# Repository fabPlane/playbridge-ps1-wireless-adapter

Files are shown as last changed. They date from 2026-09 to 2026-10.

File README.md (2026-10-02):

# PlayBridge PS1 Wireless Adapter

PlayBridge is an ESP32-based wireless bridge that receives PC controller state
over Wi-Fi and presents it to an original PlayStation through the native PS1
controller protocol.

## Hardware versions

| Version | Design | Status |
| --- | --- | --- |
| `v1.0.0` | Direct PCB-mounted PS1 pin array | Frozen prototype checkpoint under [`versions/v1-pcb-mounted-pin-array/`](versions/v1-pcb-mounted-pin-array/) |
| `v2.0.0` | Modular donor-plug harness through board-mounted 9-contact connectors | Frozen release candidate under [`versions/v2-donor-plug-modular-adapter/`](versions/v2-donor-plug-modular-adapter/) |
| `v2.1.0` | V2.0 baseline plus status LEDs and UART debug access | Release candidate under [`versions/v2.1-status-leds-uart-debug/`](versions/v2.1-status-leds-uart-debug/) |
| `v3.0.0` | Combined PS1 controller and serial-harness evaluation | Frozen development checkpoint under [`versions/v3.0-ps1-serial-harness/`](versions/v3.0-ps1-serial-harness/) |
| `v4.0.0` | New two-layer controller/serial bridge with protected dual-source power | Digitally verified design under [`versions/v4.0-controller-serial-bridge/`](versions/v4.0-controller-serial-bridge/); physical qualification pending |
| `v4.1.0` | V4.0 electrical design with ANTS-compatible enlarged routed vias | Digitally verified fabrication revision under [`versions/v4.1-controller-serial-bridge/`](versions/v4.1-controller-serial-bridge/); physical qualification pending |

Each hardware version is a self-contained FabDesk project under `versions/`.
Open the version directory itself in FabDesk; the repository root is only the
project index plus shared firmware and documentation.

## V4.0.0 status

- Board: 68 × 60 mm, two copper layers.
- J1: PS1 controller harness with open-drain DATA and ACK stages.
- J2: PS1 serial harness on ESP32 UART2.
- Power: protected USB-C and PS1 inputs, TPS2116 source mux, AP63203 buck,
  and AP2112K 3.3 V regulation.
- Programming: CH340C with manual BOOT and RESET switches; automatic DTR/RTS
  behavior is present but is not required for acceptance.
- Indicators: always-on power LED and firmware-controlled status LED.
- Digital checks: ERC, DRC, schematic/PCB parity, BOM/CPL reference parity,
  fabrication archive integrity, and export manifest all pass.
- Manufacturing: bare-board Gerbers and in-house assembly BOM/CPL are present.
- Production remains on hold until the current-limited power, source-switching,
  programming, J1, and J2 bench tests are recorded.

See [`versions/v4.0-controller-serial-bridge/README.md`](versions/v4.0-controller-serial-bridge/README.md)
for the design summary and exact connector/GPIO maps.

## V4.1.0 fabrication revision

V4.1 preserves the V4.0 schematic, component placement, connector mechanics,
GPIO map, and BOM. Its routed through-vias are enlarged to 0.90 mm copper
diameter with 0.40 mm drills to satisfy the ANTS PCB production feedback.
The affected escape routing and manufacturing outputs were regenerated and
pass ERC, DRC, connectivity, drill, and archive-integrity checks. The same
physical bench-test hold still applies.

## V3.0 and V4.0 comparison

| Area | V3.0 | V4.0 | Compatibility / action |
| --- | --- | --- | --- |
| J1/J2 | Hong Cheng C7501856; same signal pinout | Same | Harness-compatible |
| Shells | Isolated | J1→GND pad 4; J2→GND pad 7 | Grounding changed |
| Placement | J1 `(8.025,50.825)`; J2 `(26.025,50.825)` mm | J1 `(14,48.5)`; J2 `(39.2,48.5)` mm | Not mechanically drop-in |
| Controller GPIO | CMD32, CLK33, ATT34, DATA19, ACK21 | CMD19, CLK32, ATT21, DATA33, ACK27/sense34 | Firmware change |
| DATA/ACK | 2N7002 open-drain; no ACK sense | Same drivers plus ACK sense | Firmware change |
| J2 UART | TX17 / RX16 | TX17 / RX16 | Compatible |
| Power | AP63203 + AP2112K + TPS2113A | AP63203 + AP2112K + TPS2116 | Mux changed |
| Protection | USBLC6, SMBJ12A, BAT54 clamps | SMAJ TVS, TPD2EUSB30A, ACK ESD | Prototype-test required |
| LEDs | Red power; yellow-green status GPIO4 | Green power; blue status GPIO25 | GPIO/color change |
| Programming | CH340C; manual BOOT/RESET; DTR/RTS | Same | Auto mode unqualified |
| PCB | 56.295 × 62 mm; 4-layer; 1.2 mm | 68 × 60 mm; 2-layer; 1.6 mm | Size/stackup changed |
| Validation | J1/J2 PoC tested | Digital checks pass; bench pending | First prototype only |

## V2.0.0 historical status

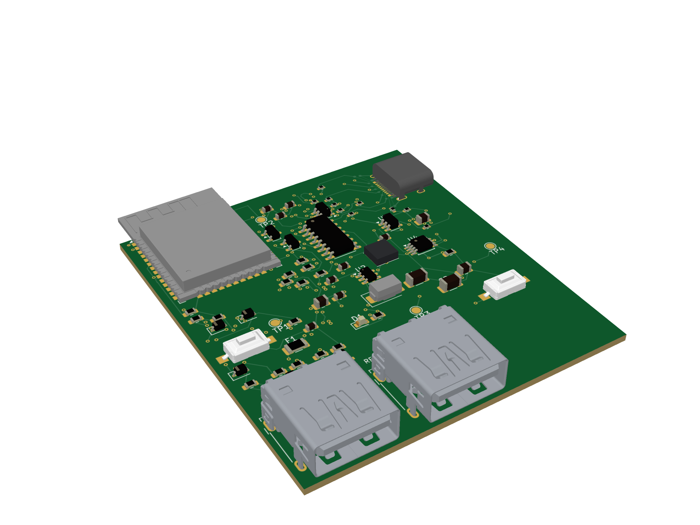
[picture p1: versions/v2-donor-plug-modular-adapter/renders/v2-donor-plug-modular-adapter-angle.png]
PlayBridge V2.0 donor-plug modular adapter board


_Board render created with [PCB Fiddle](https://pcbfiddle.com/)._

- Board: 56.295 × 62.000 mm, four copper layers, 1.20 mm thick.
- J1: 9-contact non-USB connector for a genuine PS1 donor-plug harness.
- J2: mechanically identical reserved connector; every contact is intentionally NC.
- J3: USB-C programming/power receptacle on the right edge, facing outward.
- J1 and J2: lower-edge mating mouths face outward and remain registered to the approved Molex footprints.
- Routing: complete; zero unconnected items.
- DRC: zero errors and zero warnings.
- ERC: zero errors and zero warnings.
- Schematic/PCB parity: zero findings.
- FabDesk release gate: PASS.
- PCBA data: 63 fitted references, 32 grouped BOM lines, and four DNP test pads.
- Controller-port bench firmware passed visible original-PS1 system-menu testing over Wi-Fi: all supported digital buttons worked, quick clicks were reliable, and the final check recorded 17,913 complete polls.

The design release is electrically and mechanically validated. Ordering still
requires a final live JLCPCB stock check and review of the uploaded BOM/CPL
rotation previews; see
[`versions/v2-donor-plug-modular-adapter/ordering/DO-NOT-ORDER.md`](versions/v2-donor-plug-modular-adapter/ordering/DO-NOT-ORDER.md).

## Repository layout

- `versions/v1-pcb-mounted-pin-array/` — complete frozen V1 FabDesk project, fit checks, historical renders, and provisional-contact studies.
- `versions/v2-donor-plug-modular-adapter/` — complete V2.0.0 FabDesk project, manufacturing package, reports, tools, references, and accepted renders.
- `versions/v2.1-status-leds-uart-debug/` — complete V2.1.0 FabDesk project, debug interface, manufacturing package, reports, tools, and accepted renders.
- `versions/v3.0-ps1-serial-harness/` — complete V3.0 controller/serial-harness development checkpoint and PoC evidence.
- `versions/v4.0-controller-serial-bridge/` — complete V4.0 FabDesk project, local libraries, validation evidence, renders, and manufacturing package.
- `versions/v4.1-controller-serial-bridge/` — V4.1 ANTS-compatible via revision, regenerated validation evidence, renders, and manufacturing package.
- `firmware/playbridge_wifi_test/` — shared ESP32 Wi-Fi controller firmware and bench instructions.
- `docs/` — shared protocol and modular-interconnect diagrams.

## Opening a hardware project

In FabDesk, select the desired directory under `versions/`, not the repository
root. New hardware work should begin by copying the latest applicable version
to a new version directory so previous releases remain unchanged.

## Important connector warning

J1 and J2 use USB 3 Type-A connector hardware only as inexpensive keyed
9-contact interconnects. They carry native console signals and are **NOT USB**.
Never connect either port to a computer, charger, or ordinary USB peripheral.

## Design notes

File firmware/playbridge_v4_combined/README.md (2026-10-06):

# PlayBridge V4 controller and J2 firmware

Experimental combined firmware for the PS1 controller port and rear serial
port. This preserves the console-tested polling controller and adds an opaque
TCP to UART2 bridge. The bench-profile combined build has now been flashed and
tested with controller input, two small RAM dumps, and a checksum-verified
128 KiB memory-card download through Wi-Fi to a Mac-mounted SD card. This is
not production qualification or proof of game loading/simultaneous gameplay.

The unchanged, working controller-only source is preserved in
[`../playbridge_v4_controller`](../playbridge_v4_controller).
The pre-existing `../playbridge_wifi_test` sketch is also untouched.
The older handoff prompt's SPI pin mapping and claim that J2 is NC must not be
used as V4 wiring instructions.

## Select the physical pin profile

The default is the **actual working breadboard**, not the assembled PCB.

| Signal | Profile 1 bench default | Profile 2 V4 PCB |
| --- | --- | --- |
| CMD input | GPIO34 | GPIO19 |
| CLK input | GPIO32 | GPIO32 |
| ATT input | GPIO21 | GPIO21 |
| DATA drive | GPIO33 | GPIO33 |
| ACK drive | GPIO27 | GPIO27 |
| DATA diagnostic input | GPIO19 via 1 kΩ | Disabled |
| ACK diagnostic input | Not used | GPIO34 reserved, not read |
| J2 TX | GPIO17 via **220 Ω** to console RX (bench equivalent of J2.1) | GPIO17 via 1 kΩ to J2.1; not qualified |
| J2 RX | Console TX via 1 kΩ to GPIO16; 10 kΩ pull-up at harness-side junction | J2.4 via 1 kΩ to GPIO16; not qualified |
| J2 GND | J2.7 | Same |

J2.1 connects to **console RX**, J2.4 to **console TX**. These are J2 connector
numbers, not rear-PS1-port pin numbers. Continuity-map the real harness and
verify 3.3 V-compatible levels; never infer by wire colour. J2 carries no power,
is not USB, and all other J2 contacts remain open. Remove the old UART loopback
before attaching the peer. UART0 USB programming/debug is separate.

Bench controller values verified during debugging: DATA C50 pull-up **1 kΩ** to
3.3 V; E51 to F51 control resistor **1 kΩ**; C51 pull-down **100 kΩ** to GND.
Keep E50 to F50 **1 kΩ** and G50 to GPIO19 for diagnostic readback in profile 1.
GPIO HIGH turns on the external output stage and pulls the PS1 line LOW.
The bench NPN circuit is not evidence that V4 PCB component values or its
2N7002 stages are physically qualified. No PCB or BOM files are changed by this
PR; the breadboard-only serial adjustments above are recorded in TEST-RESULTS.md.

## Architecture

- Core 1 Arduino loop owns the IRAM polling controller. The 16-bit active-low
  button state is latched once per transaction. ACK delay is 14 µs, LOW for
  2 µs, and there is no final-byte ACK. No per-edge ISR, networking, allocation,
  or logging occurs inside the controller transaction.
- Core 0 web task owns Wi-Fi AP/STA and HTTP 80. Saved credentials are reused,
  Wi-Fi sleep is disabled, and runtime credential writes/OTA are not exposed.
  The current full-state `POST /state` interface is retained; the obsolete
  reference `/input` and `/button` interfaces are not imported.
- A separate core 0 task owns UART2, TCP 3333 and UDP 3334. It initializes the
  IDF UART driver on that core, which also allocates the UART ISR there.
  HTTP never accesses live UART or bridge sockets.
- Short synchronized snapshots provide `/status` (controller) and
  `/bridge/status` (serial counters, baud, fault, owner core, timing, heap,
  stack). Web handling remains active during transfers.
- Browser holds refresh every 200 ms. Button input expires after 800 ms
  without an accepted update; blur/cancel/neutral release immediately when
  the request arrives. HTTP success is not proof the console accepted a reply.

The bounded polling wait still disables interrupts on core 1 for up to 2 ms,
plus up to a 2 ms transaction timeout. Core separation reduces UART contention
but is not proof of performance. Measure simultaneous pad latency, serial
integrity and throughput on hardware.

## Serial protocol

UART starts at **115200 8N1**, with no hardware flow control. The existing
PC launcher coordinates the PS1-side baud switch; the bridge does not negotiate
it with the console. Supported rates: 115200, 230400, 518400, 691200, 1036800,
2073600. Support here means accepted configuration, not a measured speed claim.

TCP 3333 has one owner and carries only raw bytes, with no added framing or
logs. The PC asset server, patched PS1 launcher/game code, and checksums/retries
remain external. This is not direct SD access or universal game compatibility.
The unchanged handoff `host/bridge_baud.py` controls bridge baud. The additional
`host/memcard_backup.py` performs read-only Unirom 8.0.K memory-card backups;
it is not the game asset server.

### Read-only memory-card backup (Unirom 8.0.K)

Use Python 3 on the host. Boot to the Unirom menu, insert the card, verify the
three-wire serial harness, remove any loopback, and leave the bridge idle at
115200. Specify the physical slot (1 or 2) and a **new** output filename in an
existing writable directory on the mounted destination. For example:

```sh
python3 firmware/playbridge_v4_combined/host/memcard_backup.py \
  --host ESP32_IP --slot 1 --output /Volumes/YOUR_SD/ps1-slot1-backup.mcd
```

The tool sends `MCDN`, negotiates `OKV2`/`UPV2` (or V3), waits for **`OKAY`**,
sends zero-based card index, and waits for `MCRD` plus RAM address/length.
It validates a 128 KiB buffer wholly within PS1 RAM, uses `DUMP`, sends `MORE`
after each 2048 bytes, verifies the negotiated checksum, saves without
overwriting, and verifies the saved file's SHA-256 by reading it back.
It prints a JSON result; it does not commit or upload backups anywhere.
The memory card is read-only; Unirom temporarily stages its data in console RAM.
Do not disconnect/power off or press controller buttons during the read.

This protocol is pinned to the
[older official NoPS definitions](https://github.com/JonathanDotCel/NOTPSXSerial/blob/63a47555353404ff067563f26529897bf84cf84c/NOTPSXSERIAL.CS)
and [transfer implementation](https://github.com/JonathanDotCel/NOTPSXSerial/blob/63a47555353404ff067563f26529897bf84cf84c/TransferLogic.cs).
The newer client's `HLTD` expectation for MCDN did not match this bench console.
After a timeout the console may still be waiting for a protocol field: **do not
blindly retry**. Return it to a fresh Unirom menu first. The published tool has
no automatic retry or mid-session resume shortcut.

`PING` returned only its own echo on this console, while DUMP and MCDN succeeded.
Do not treat an echoed PING as a loopback diagnosis or demand PONG as a required
gate for this setup. A full negotiated, checksum-verified dump is stronger
evidence. Do not stop a handshake just because the command itself is echoed.

UDP 3334 accepts exactly 20 bytes:

| Bytes | Meaning |
| --- | --- |
| 0 to 3 | ASCII PSB1 |
| 4 to 7 | Host nonce, little-endian |
| 8 to 11 | Baud, little-endian |
| 12 to 15 | Flags: 0 normal, 1 abort session |
| 16 to 19 | Standard CRC32 of bytes 0 to 15, little-endian |

Success echoes the exact request to its originating IP/port. Invalid packets,
wrong active-owner IP, busy queues, failed baud changes, or drain timeout get
no success echo. During normal handoff, both forwarding queues and new input
must be empty. TX drain is polled with zero ticks and a 150 ms deadline; new
input cancels that handoff. The launcher retries on no acknowledgement.

Successful control effects are cached **before** sending the echo: eight
requests for ten seconds, keyed by sender IP/port and exact frame. A retry
does not abort a new session. An older request whose baud has since changed
gets no misleading success echo. This is bounded duplicate suppression, not
authentication or indefinite replay protection; use a trusted LAN.

Abort/disconnect/error discards application queues and reinstalls UART2 to
discard driver RX/TX rings and reset FIFOs. Bytes already transmitted cannot be
retracted: abort does not reset the PS1 or restore Unirom. The launcher must
resynchronize. If UART reset fails, the bridge stays faulted until reboot.
New clients are accepted only after UART cleanup. UART bytes without a client
are discarded, so connect the PC session before requesting a console response.
TCP close is a session abort, not a supported half-close request/response mode.

Queue sizes: 16,384 UART RX; 4,096 UART TX; 16,384 UART-to-TCP pending;
1,024 TCP-to-UART pending. Partial writes retain offsets. Retryable socket
errors do not discard data. Each direction has its own ten-second progress
deadline; traffic in the other direction cannot mask a stalled queue.

## Build and test

Use Arduino CLI with installed Arduino-ESP32 **3.3.11**, Node32s, standard
4 MB board profile; do not copy the handoff's COM10 or 16 MB flash settings.
Commands from repository root:

```sh
sh firmware/playbridge_v4_combined/tests/run.sh

arduino-cli compile --fqbn esp32:esp32:node32s \
  --build-path /tmp/playbridge-combined-bench-build \
  firmware/playbridge_v4_combined

arduino-cli compile --fqbn esp32:esp32:node32s \
  --build-property compiler.cpp.extra_flags=-DPLAYBRIDGE_PROFILE=2 \
  --build-path /tmp/playbridge-combined-pcb-build \
  firmware/playbridge_v4_combined
```

Native tests need a C++17 compiler with ASan/UBSan, Node.js and Python 3. They execute the
actual transport core and actual polled engine, not independent protocol
reimplementations. The browser script is exercised with a mocked DOM/network.
The Python backup tests use synthetic data and fake peers. The test runner
does not open UART, send LAN traffic, or flash hardware. The explicitly invoked
host backup tool does send serial commands and writes the requested backup file.

Keep the controller-only rollback source and existing verified binary before
any separately authorized upload. Change wires only with USB unplugged and PS1
off; physically disconnect both console harnesses before flashing. Do not
flash the handoff's compile-only harness.

## Evidence and remaining acceptance

See [TEST-RESULTS.md](TEST-RESULTS.md) and [provenance.json](provenance.json).
The user confirmed every controller web button on the controller-only baseline,
then confirmed movement on the flashed combined build. Subsequent combined-build
testing transferred actual PS1 RAM and slot-1 memory-card data through Wi-Fi.
The preceding 1,624-complete-reply diagnostic with zero sampled DATA mismatches
remains controller-only evidence; do not attribute it to the combined build.

Before calling this combined firmware stable:

1. Recheck controller-only and known serial-only baselines.
2. Transfer a small known Unirom payload at 115200 with the existing launcher.
3. Run repeated large end-to-end CRC-verified transfers at every supported rate.
4. Repeat with rapid and held web inputs, checking pad poll failures/latency,
   UART errors, transfer retries, throughput, heap and stack headroom.
5. Exercise cable/network interruptions, baud changes, duplicate controls and
   reconnects; confirm no old bytes cross into a new session.
6. Observe simultaneous gameplay. Keep save-write tests separate from read-only
   integrity tests. Record exact harness, hardware/profile and firmware hash.

## Source references

The user-supplied handoff provides `bridge-txqueue-1`, its extraction starter,
PSB1 contract, and host helper. Hashes are recorded in provenance.json; no
game data, flash dumps, private credentials, or save files are included.
ACK timing follows the existing PlayBridge/BlueRetro PSX reference (BlueRetro,
Apache-2.0) and PSX-SPX documentation. The polling implementation replaces the
old SPI/per-edge controller path; existing repository attribution is preserved.

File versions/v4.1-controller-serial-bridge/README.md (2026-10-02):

# PlayBridge V4.1 — ANTS-compatible controller + serial bridge

Status: **digital verification PASS; production HOLD pending physical bench tests**.

V4.1 is the self-contained FabDesk/KiCad project for the 68 × 60 mm,
two-layer PlayBridge board. It combines the PS1 controller interface on J1,
the PS1 serial interface on J2, USB-C programming/power, protected PS1 power,
and automatic source selection.

## V4.1 fabrication adjustment

- The schematic, component placement, connector mechanics, firmware GPIO map,
  and BOM are unchanged from V4.0.
- All 190 routed through-vias are 0.90 mm diameter with 0.40 mm drills and a
  0.25 mm minimum annular ring.
- Local routing around the ESP32, CH340C, and USB-C fanout was adjusted for the
  enlarged vias. The USB-C VBUS escape uses a documented 0.15 mm neckdown.
- Generated drill data identifies all routed vias as 0.40 mm `ViaDrill` hits.
- ERC reports 0 violations; DRC reports 0 violations and 0 unconnected items.

## Interfaces

- J1: pin 1 NC, 2 CMD, 3 CLK, 4 GND, 5 ATT, 6 DATA, 7 ACK, 8 PS1 power,
  and 9 NC. Both shell/retention pads are GND through pad 4.
- J2: pin 1 TX, 4 RX, and 7 GND; all other signal pins are NC. Both
  shell/retention pads are GND through pad 7.
- J1 and J2 use USB-A connector hardware only as keyed PS1 harness ports.
  They are **NOT USB**.
- The SERVICE / DEBUG holes are GND, UART0 TX, and UART0 RX at 3.2 mm pitch.

The exact firmware GPIO map is in `exports/firmware-handoff.md` and
`exports/firmware-pin-map.h`.

## V3.0 and V4.1 comparison

| Area | V3.0 | V4.1 | Compatibility / action |
| --- | --- | --- | --- |
| J1/J2 | Hong Cheng C7501856; same signal pinout | Same | Harness-compatible |
| Shells | Isolated | J1→GND pad 4; J2→GND pad 7 | Grounding changed |
| Placement | J1 `(8.025,50.825)`; J2 `(26.025,50.825)` mm | J1 `(14,48.5)`; J2 `(39.2,48.5)` mm | Not mechanically drop-in |
| Controller GPIO | CMD32, CLK33, ATT34, DATA19, ACK21 | CMD19, CLK32, ATT21, DATA33, ACK27/sense34 | Firmware change |
| DATA/ACK | 2N7002 open-drain; no ACK sense | Same drivers plus ACK sense | Firmware change |
| J2 UART | TX17 / RX16 | TX17 / RX16 | Compatible |
| Power | AP63203 + AP2112K + TPS2113A | AP63203 + AP2112K + TPS2116 | Mux changed |
| Protection | USBLC6, SMBJ12A, BAT54 clamps | SMAJ TVS, TPD2EUSB30A, ACK ESD | Prototype-test required |
| LEDs | Red power; yellow-green status GPIO4 | Green power; blue status GPIO25 | GPIO/color change |
| Programming | CH340C; manual BOOT/RESET; DTR/RTS | Same | Auto mode unqualified |
| PCB | 56.295 × 62 mm; 4-layer; 1.2 mm | 68 × 60 mm; 2-layer; 1.6 mm | Size/stackup changed |
| Validation | J1/J2 PoC tested | Digital checks pass; bench pending | First prototype only |

## Electrical and mechanical verification evidence

- ERC: 0 errors and 0 warnings.
- DRC: 0 violations, 0 unconnected pads, and 0 schematic-parity issues.
- Connectivity: 53/53 named nets and 227/227 connected nodes match.
- Board: 68 × 60 mm, two copper layers.
- J1/J2 signal pins and retention legs cross the 1.6 mm PCB and protrude
  about 1.2 mm below it for soldering.
- Every fitted footprint has a 3D model; TP1/TP2/TP3 are intentionally DNP.
- Engineering BOM: 80 references. Assembly BOM/CPL: 77 fitted references,
  with an exact reference-set match and no blank LCSC codes.
- The fabrication ZIP contains the complete Gerber and drill set and passes
  archive integrity testing.
- `exports/manifest-sha256.txt` verifies the canonical project, manufacturing
  outputs, accepted renders, and final reports.

## Directory layout

- `board.kicad_*`, `circuit.netlist.json`, and `fabdesk.json` — canonical project.
- `NewPlayBridge.pretty/`, `NewPlayBridge.kicad_sym`, and
  `PlayBridge.3dshapes/` — project-local libraries and models.
- `exports/` — canonical Gerbers, fabrication ZIP, BOM, CPL, positions,
  shopping list, firmware handoff, interchange files, and checksum manifest.
- `ordering/` — convenient vendor-facing copies for bare-board ordering and
  in-house assembly preparation.
- `reports/` — final electrical, mechanical, procurement, and verification evidence.
- `renders/` — generated populated-board, connector, and GLB renders.

Open this version directory itself in FabDesk; do not open the repository root.

## Bench-test hold

No assembled V4 board has been bench-qualified. Complete and record the plan
in `reports/bench-test.md` before production approval. In particular, verify
current-limited USB and PS1 power, TPS2116 source switching and backfeed,
manual programming, J1 controller waveforms, J2 UART operation, and L1
temperature/current margin. Manual BOOT/RESET is the accepted programming path.

See `RELEASE-v4.1.0.md` for the digitally verified fabrication-revision statement.

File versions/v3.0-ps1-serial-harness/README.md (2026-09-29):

# PlayBridge V3.0 — PS1 serial harness evaluation

Status: **J2 implementation and bench test passed; manufacturing package refresh required before ordering**.

This directory is the authoritative V3.0 development project derived from the
validated, frozen V2.1 release. V3.0 evaluates a third keyed donor-harness
connector, J4, for a PS1 serial-port link while preserving the V2.1 status
LEDs and connector-free UART0 service row.

## V3.0 design intent

- Evaluate whether the currently all-NC J2 can safely serve the PS1 serial
  harness before adding another connector. Do not populate both J2 and J4 for
  the same purpose without a documented mechanical/electrical reason.
- If J4 remains necessary, use one outward-facing USB-A connector body matching
  J1/J2 and identify it clearly as J4 and `NOT USB`.
- Preserve J1, J2, J3, the SERVICE / DEBUG row, RESET, BOOT, STATUS, PWR,
  antenna clearance, and all V2.1 functionality.
- Confirm the PS1 serial-harness pinout, logic levels, direction, protocol,
  throughput/latency, supported console revisions, and isolation/backfeed
  policy before committing copper. Do not silently parallel console buses.
- Keep the intended path explicit: PC/browser -> Wi-Fi -> ESP32 -> GPIO17/TX,
  GPIO16/RX and GND -> keyed NOT-USB harness -> PS1 serial port.
- The user/team confirmed the teammate firmware/protocol and electrical bench
  PoC on 2026-09-25. The preserved photos document the powered test hardware;
  functional operation is a user-reported bench result rather than something
  independently visible in the still images. Do not generalize that result to
  untested console revisions, cables, protocol modes, or full handshaking.

## V2.1 baseline retained

- D1 is the yellow-green firmware `STATUS` LED: KENTO `KT-0603YG` / LCSC `C2289`, driven by ESP32 module pin 26 on `STATUS_LED` through R13, 1 kΩ Yageo `RC0603FR-071KL` / `C22548`; polarity is unchanged.
- D6 is the red always-on 3V3 `PWR` LED: KENTO `KT-0603R` / `C2286`, through R29, 1 kΩ Yageo `RC0603FR-071KL` / `C22548`.
- The physical J4 header was removed. The lower-right SERVICE/DEBUG row contains DNP plated holes: TP2 GND at (43.500, 54.000) mm, TP3 UART_TX at (46.700, 54.000) mm, and TP4 UART_RX at (49.900, 54.000) mm. Pitch is 3.200 mm; each pad is 2.0 mm with a 1.0 mm finished plated hole.
- J1, J2, J3, and SERVICE / DEBUG are explicitly identified on F.Silkscreen. No J4 reference is fabricated in V2.1; V3.0 must first decide whether J2 can serve the serial harness or whether a distinct J4 is justified.
- TP1 remains the existing 3V3 test point. UART signals are 3.3 V logic only.
- RESET, BOOT, J1/J2/J3, USB orientations, antenna keepout, outline, and unrelated V2.0 placement/copper remain unchanged.

## Final verification and outputs

Verified 2026-09-25: DRC 0 errors, 0 unconnected, and only three approved historical `track_dangling` warnings; ERC 0 errors/0 warnings; schematic/PCB parity 0; release gate PASS.

- Accepted verification renders: `renders/service-debug-full-top.png` and `renders/service-debug-close.png`.
- Generic outputs: `exports/gerbers/`, `exports/gerbers/board.drl`, `exports/bom.csv`, `exports/positions.csv`, `exports/assembly-bom.csv`, `exports/assembly-cpl.csv`, `exports/netlist.net`, and `exports/fabrication.zip`.
- JLCPCB preparation: `ordering/jlcpcb-bom.csv`, `ordering/jlcpcb-cpl.csv`, and `ordering/gerbers-jlcpcb.zip`.
- Detailed evidence: `reports/V2.1-AUDIT.md`.
- V3.0 PoC evidence: `reports/evidence/README.md` and the two preserved setup
  photographs.
- V3.0 release result and package hashes: `reports/final-release-gate.md`.

**ORDER CHECKOUT HOLD:** fresh V3.0 manufacturing files are generated from the
verified board. Before purchase, upload them to the assembler and complete the
BOM/CPL rotation, substitution, and live-stock review described in
`ordering/DO-NOT-ORDER.md`. The user-reported J2 bench test has passed.

The fabrication exports and validation reports have been regenerated for V2.1.

V2 replaces the PCB-mounted PlayStation pin array with a removable donor-plug harness.

The main PlayBridge board will expose removable multi-contact connectors. A console-specific adapter will use a genuine donor controller cable and molded PlayStation male plug soldered to a matching breakout board. Swapping the adapter cable will make it possible to support other console systems without manufacturing their proprietary plug contacts directly on the main PCB.

## Architecture

- Keep the ESP32, signal protection and protocol-generation circuitry on the main board.
- Replace the console-facing PCB pin array with a removable cable interface.
- Use the genuine molded PlayStation donor plug for console alignment, contact geometry and insertion loads.
- Map every donor wire by continuity testing; never rely on wire color.
- Treat the observed missing pin 8 as a donor-plug property that must be verified electrically.
- Define connector pin allocation, power/backfeed protection, shield policy and cable requirements before designing the V2 PCB.
- Add other console adapters only after the PS1 harness is validated.

## Safety warning

The concept currently uses USB 3 Type-A connector hardware because it provides enough inexpensive contacts and readily available breakout boards. The signals would be native console signals—not USB. Any implementation must be clearly marked **NOT USB**, protected against accidental connection to computers/chargers, and reviewed before hardware is powered.

## References

- [`concepts/`](concepts/) contains the supplied system architecture, breakout-board example and illustrative product layout.
- [`references/ps1-donor-plug/`](references/ps1-donor-plug/) contains photographs of the actual donor plug, including the empty pin-8 position.

## V2.0.0 baseline checkpoint

This directory began as a self-contained copy of the V2.0.0 release snapshot. It includes the
KiCad project, FabDesk netlist/configuration, local symbol/footprint/3D-model
libraries, verification reports, manufacturing package, release tools,
references, and accepted renders.

The baseline details below remain useful for comparison, but V2.1 must pass a
fresh release gate after modification.

- Board: 56.295 × 62.000 mm, four layers, 1.20 mm thick.
- J1/J2: Hong Cheng `HC-USB3.0-L168-ZP` / JLCPCB `C7501856`, used as keyed nine-contact **non-USB** harness interfaces. J2 carries the validated three-wire PS1 serial link.
- The official JLCPCB/EasyEDA footprint and 3D model are stored locally. All nine electrical-pad centers exactly match the prior routed pattern; only the connector shell slots, body/courtyard and visual model changed.
- J1 is at (8.025, 50.825) mm and J2 at (26.025, 50.825) mm in the vendor footprint coordinate frame. Their absolute signal-pad coordinates and all routed copper are unchanged, and both mating mouths face outward through the lower edge. J3 remains at (51.025, 9.625) mm, 90°, facing outward through the right edge.
- ERC, DRC, schematic parity, and connectivity currently pass with zero errors, warnings, or unconnected items. Ordering remains subject to the sourcing and PCBA-completeness checks in `ordering/`.

See [`RELEASE-v2.0.0.md`](RELEASE-v2.0.0.md) for the release gate,
manufacturing-package status, 3D-model provenance, and remaining checkout hold.

## Snapshot layout

- `board.kicad_*`, `circuit.netlist.json`, and `fabdesk.json` — complete V2 design.
- `PlayBridge.pretty/`, `PlayBridge.3dshapes/`, and the symbol libraries — project-local libraries required to reopen the design.
- `ordering/` — Gerber archive, BOM, CPL, sourcing audit, and checkout hold.
- `reports/` — release build, DRC, ERC, statistics, and gate reports.
- `tools/` — scripts used for model inspection and order-file generation.
- `renders/` — accepted V2.0.0 renders only.

## USB-A mechanical fit

J1 and J2 use the official Hong Cheng `HC-USB3.0-L168-ZP` / `C7501856`
through-hole pattern: nine 0.70 mm signal holes plus two 0.60 × 2.30 mm plated
shell slots. The 13.10 × 16.80 mm body fits at the existing lower edge without
a PCB cutout; its mouth intentionally overhangs the board while all signal pins
and both shell slots remain supported by the PCB. Board thickness remains 1.20 mm.

## 3D-model validation

The official `C7501856` WRL/STEP model uses zero offset, zero rotation and unit
scale in the vendor footprint frame. Direct front and perspective renders show
both bodies seated on the top surface, the two mouths facing outward, and the
through-hole tails/retention legs aligned to their pads. See the accepted
`renders/v3.0-*.png` inspection set.

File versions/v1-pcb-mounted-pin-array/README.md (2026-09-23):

# V1.0.0 — PCB-mounted PS1 pin array

PlayBridge is an ESP32-based adapter intended to plug directly into an original PlayStation controller port. A PC sends controller state over Wi-Fi, and the adapter presents that state to the console through the PS1 controller protocol.

Open this directory directly in FabDesk. This is the frozen V1.0.0 project;
start later hardware work from a separate version directory.

## Current status

The PCB design is electrically complete, but physical PS1-contact validation is still required before fabrication release.

- Board: 55 x 52 mm, four copper layers
- ESP32-WROOM-32 module
- USB-C programming and development connection
- Nine-position provisional PS1 contact footprint with eight metal contacts
- Seven active PS1 contacts; pin 5 is physically present but isolated, and pin 8 is physically absent
- Routing: complete, with zero unconnected items
- ERC: zero errors and zero warnings
- DRC: zero errors and zero unconnected items; 25 physical warnings remain documented
- Schematic/PCB parity: 66 archived `extra_footprint` warnings because this
  checkpoint predates synchronized schematic-to-board identity metadata
- USB-C breakout and full-board routing are complete
- The nine-pin 4.00 mm spacing/insertion concept passed a physical guide fit; the final contact MPN, assembly tolerances, retention and printed alignment shell still require manufacturing validation

## Repository layout

- `circuit.netlist.json` — FabDesk source design
- `board.kicad_*` — generated/current KiCad project files
- `PlayBridge.pretty/` — project-local footprints
- `PlayBridge.3dshapes/` — project-local provisional 3D models
- `fit-test-coupon/` — PS1 contact measurement and fit-test material
- `fit-check/` — printable STL fixtures and physical controller-port test photos
- `enclosure/` — provisional mechanical studies
- `manufacturing-notes.md` — current manufacturing constraints and open questions
- `docs/images/current/` — latest reviewed images only
- `docs/images/archive/` — superseded and diagnostic images kept for design history

## Important mechanical note

The nine PS1 contacts use 4.00 mm pitch and a 32.00 mm first-to-last center span. A printed guide carrying all nine nominal 0.64 mm square pins was successfully inserted into a spare original PS1 controller port. Each pin projects 16.00 mm beyond the PCB edge: the inner 8.00 mm is reserved for printed-nose capture/alignment/support and only the outer 8.00 mm is the console mating section. The final contact manufacturer part number, production hole/tolerance, retention method and plating have not been released.

J1 pin 5 is `PS_3V5_CONSOLE`, measured at 3.58 V relative to pin 4/GND with the console powered and ESP32 disconnected. It remains intentionally isolated from board 3V3 and every USB/console power path to avoid backfeed. Pin 8 is the only true console NC.

This checkpoint is suitable for team review and prototype-output preparation, but it is not yet an approved assembly release. Resolve or formally accept the remaining DRC and parity warnings, finish J1 contact sourcing/assembly validation, and verify the production-board USB-C 3D transform before ordering assembled boards.

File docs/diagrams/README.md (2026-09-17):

# PlayBridge modular interconnect diagrams

These diagrams document the proposed two-connector modular architecture. The
USB 3 Type-A shells are used only as inexpensive **nine-contact mechanical
connectors**. The signals are native PlayStation/ESP32 signals, not USB data,
so the finished hardware must be labeled to prevent connection to a USB host.

## Rendered diagrams

- [System architecture](./ps1-modular-interconnect.svg)
- [Front-port harness](./ps1-front-harness.svg)
- [Proposed contact allocation](./ps1-contact-allocation.svg)
- [Photorealistic product concept](../images/concepts/playbridge-modular-harness-concept.png)

PNG exports are stored beside the SVG files for quick previews. The editable
Mermaid sources are the matching `.mmd` files.

## Architecture summary

The main ESP32 PCB has two USB 3 female receptacles:

1. `J1 FRONT BUS` connects to a passive harness for two controller plugs and,
   optionally, two memory-card edge adapters.
2. `J2 SERIAL` connects to a passive rear-serial-port harness.

The front harness shares `DATA`, `CMD`, `CLK`, `ACK`, and `GND` between the two
PlayStation ports. Separate `ATT1` and `ATT2` lines select the two ports. This
mirrors the PlayStation bus topology; it is not a USB hub.

The proposed contact assignments are a design reference, not a finalized
pinout. Confirm voltage rails, ESP32 protection, the PS1 serial-port electrical
interface, connector orientation, and continuity on actual donor cables before
fabrication.

The product concept image is illustrative rather than dimensionally accurate.
Connector geometry, pin count, cable construction, enclosure clearances, and
the memory-card edge adapters must be validated against production parts.

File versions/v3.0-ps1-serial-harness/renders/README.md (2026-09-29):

# Accepted V3.0 J2 serial verification renders

- `v3.0-populated-top.png`: complete populated top view with board routing,
  component models, `J2 PS1 SERIAL`, STATUS/PWR LEDs, switches and UART0 service
  holes visible.
- `v3.0-populated-perspective.png`: populated perspective view proving the J1
  and J2 connector bodies are seated at the lower edge and face outward.
- `v3.0-j1-j2-edge.png`: direct lower-edge view into both J1 and J2 mouths.
- `v3.0-bottom.png`: full bottom copper, pad and via inspection view.

These images were regenerated after replacing the unavailable C3197928 with
ready-for-assembly Hong Cheng HC-USB3.0-L168-ZP / JLCPCB C7501856. The nine
electrical-pad centers remain unchanged, so no copper was rerouted. The new
official vendor model, two shell slots and body/courtyard are shown. Final DRC
remains zero errors, zero unconnected pads and zero schematic-parity findings,
with only the three inherited locally approved UART0 test-stub warnings.

SHA-256:

```text
7430235c1d6ccdc6e1f984870e74b5c252d18815d5336b8645e68bc4859c599c  v3.0-bottom.png
3348143ce81ccffe45ece28a55ce5dd7a45624dd9e076883bae2e75fa52c4568  v3.0-j1-j2-edge.png
e473214ecfee678085f4d2535282d27b7a868cd929821892c8ba9b2b4f12acbb  v3.0-populated-perspective.png
4f17eef1b52b5d0e5f0a0a7df80283226a352747681b3990957ca9d529a8d80f  v3.0-populated-top.png
```

The older V2.1 service-debug images remain as inherited comparison artifacts;
the four `v3.0-*.png` images above are the V3.0 release-review set.

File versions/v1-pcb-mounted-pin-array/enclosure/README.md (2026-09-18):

# PlayBridge direct bare-male-pin architecture

## Corrected signal path

**Eight bare PCB-mounted male contacts in a nine-position pattern → PS1 console female controller port → PCB traces → protection/interface → ESP32.**

The two user photographs under `references/user-photos/` show nine recessed console socket openings behind three keyed plastic housing divisions. Direct physical measurement establishes that the nine electrical contact centers remain on one continuous uniform pitch; the plastic divisions do not introduce wider contact gaps.

The product has no donor plug, cable, internal wires, or female socket contacts. Eight provisional straight male contacts project from the console-facing PCB edge; position 8 is intentionally empty, matching the reference controller plug. A future printed keyed shell must align the contacts, reproduce the plastic 3+3+3 divisions, set the insertion datum, prevent rotation, and transfer insertion/removal/rocking loads into the enclosure rather than the contacts or solder joints.

## Fixed architecture

- CONSOLE SIDE: eight bare male contacts projecting outward in positions 1–7 and 9; position 8 is empty. The three visible groups are mechanical shell divisions only.
- USER SIDE: USB-C on the exact opposite edge, opening outward.
- ESP32-WROOM-32 retained with full antenna keepout.
- Maximum assembled envelope: 42 × 42 mm; PCB must fit the measured internal cavity.
- Manufacturing solder mask: **red**.

Position 8 is the only true console NC and has no metal contact on the reference controller plug. Position 5 is physically present and is `PS_3V5_CONSOLE`: it measured 3.58 V relative to pin 4/GND with the console powered and the ESP32 disconnected. The self-powered MVP intentionally leaves pin 5 electrically isolated to prevent backfeed; it must never be tied directly to board 3V3 or USB-derived power.

## Gate status

| Item | Status |
| --- | --- |
| Electrical gender | Eight bare male contacts in a nine-position pattern, mating with the console's female port |
| Nine positions and plastic 3+3+3 divisions | Proven by user photo |
| Electrical center pitch/span | Measured and spacing-fit-checked with nine temporary test pins: continuous 4.00 mm; 32.00 mm first-to-last. Production omits position 8. |
| Pin projection | 16.00 mm beyond PCB edge: inner 8.00 mm capture/support plus outer 8.00 mm console insertion; coupon confirmation required |
| Console contact/opening size | Approximately 1.00 mm; exact mating profile/tolerance still required |
| Exact male pin MPN, production drill and assembly process | Not selected |
| Production footprint | Not created |
| Fit-test status | Nine-position guide fit passed; production uses eight contacts. MPN, hole tolerance, retention and assembled-process validation remain open. |
| Full PCB placement/routing | Frozen |

See `male-pin-feasibility.md` and `../fit-test-coupon/`.

## Provisional male-pin-array update

J1 is a provisional nine-position pattern populated with eight bare male contacts. Looking directly at the male mating face, positions run left-to-right as `1 2 3 | 4 5 6 | 7 8 9`, with position 8 empty. In PCB top view the order is mirrored. Contact-center positions are `0, 4, 8, 12, 16, 20, 24, 28, 32 mm`: continuous uniform 4.00 mm pitch and a 32.00 mm first-to-last span. The separators shown by `|` describe only the future keyed shell divisions.

Each provisional installed contact is 0.64 × 0.64 mm square and gold plated, projecting 16.00 mm beyond the PCB-edge datum. The inner 8.00 mm is reserved for keyed-shell capture, alignment and lateral support; only the outermost 8.00 mm enters the console. The current PCB footprint/model still needs position 8 removed before release. The 1.00 mm drills and 1.70 mm pads are **MECHANICAL TBD / NOT PRODUCTION RELEASED**. A coupon must validate the selected pin MPN, mating fit, both datums, retention, production drill and assembly method before any populated-board order.

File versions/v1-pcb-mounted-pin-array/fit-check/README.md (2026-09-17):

# PS1 direct-plug fit checks

These models are provisional mechanical test fixtures for the PlayBridge
direct-plug connector. They are not final enclosure or manufacturing CAD.

## STL files

- [`playbridge-ps1-fit-check-v4-one-piece.stl`](stl/playbridge-ps1-fit-check-v4-one-piece.stl)
  tests the one-piece printed guide and overall controller-port fit.
- [`9-pin-fitcheck.stl`](stl/9-pin-fitcheck.stl) tests simultaneous insertion
  and alignment of all nine metal contacts. The model measures approximately
  39.4 x 9.8 x 2.5 mm.

Print at 100% scale. Perform initial insertion tests with the console powered
off and do not force the fixture if the contacts do not align freely.

## Physical test photos

### One-piece V4

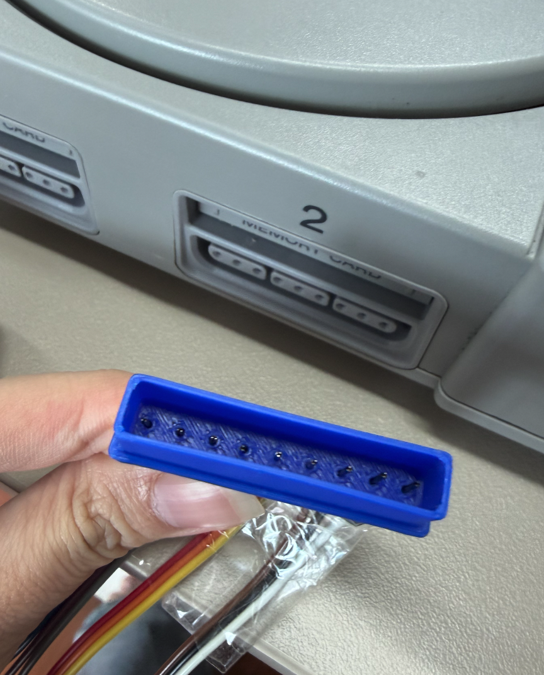
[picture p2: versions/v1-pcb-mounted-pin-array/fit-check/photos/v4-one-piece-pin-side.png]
One-piece V4 pin side


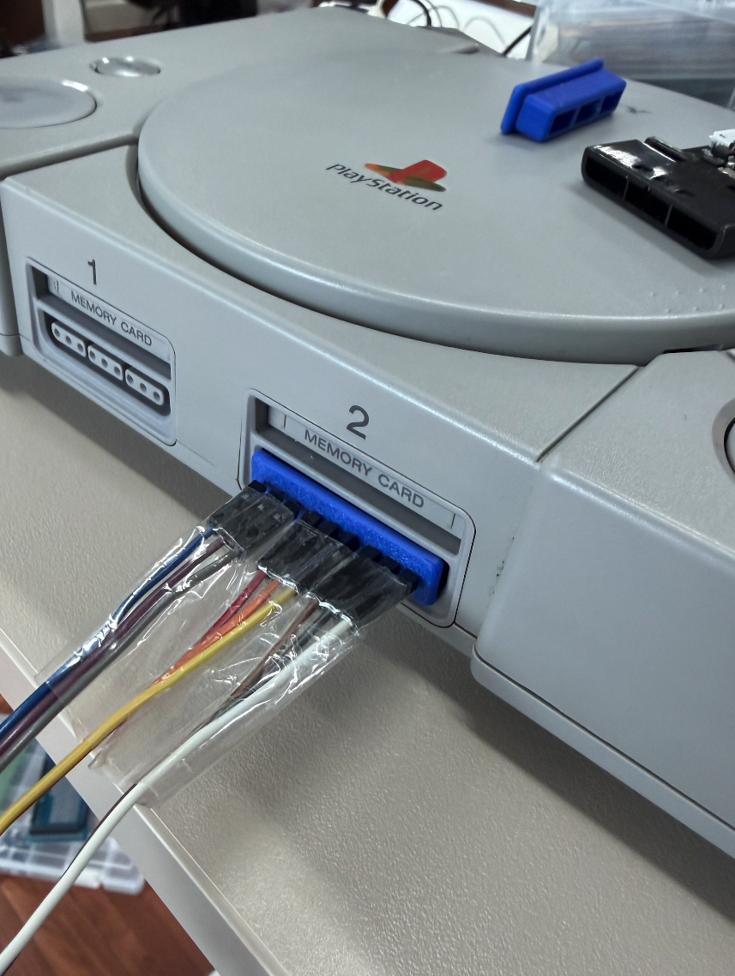
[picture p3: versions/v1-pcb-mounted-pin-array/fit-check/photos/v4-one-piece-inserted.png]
One-piece V4 inserted into the PS1 controller port


### Nine-pin insertion coupon

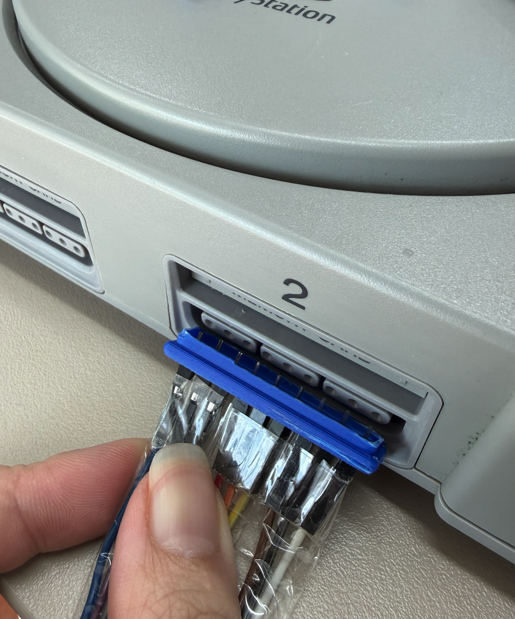
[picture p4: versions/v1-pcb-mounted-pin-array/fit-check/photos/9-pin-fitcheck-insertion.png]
Nine-pin fit-check during controller-port insertion


The photos document early fit checks only. Electrical contact reliability,
final tolerances, retention and production pin selection still require
validation.

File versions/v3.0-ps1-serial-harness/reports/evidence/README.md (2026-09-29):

# V3.0 user-confirmed bench PoC evidence

Date recorded: 2026-09-25

The user confirmed that the teammate firmware/protocol and electrical proof of
concept passed on the tested hardware configuration. The accompanying photos
are preserved here as supporting setup evidence:

- `poc-node32lite-wiring.png` — Node32 Lite development board with the bench
  wiring attached and USB power/programming connection present.
- `poc-esp32-powered.png` — ESP32 development board powered over USB with its
  indicator illuminated.

These still photographs document the physical powered setup. They do not, by
themselves, display protocol traces, measured voltage levels, console screen
output, or game-image contents. Functional operation is therefore recorded as
a user/team-reported bench result. Acceptance is limited to the tested console,
donor harness, firmware and protocol configuration; it is not a claim of full
PS1 serial handshaking or untested-console compatibility.

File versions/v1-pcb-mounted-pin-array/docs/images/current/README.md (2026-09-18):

# Current images

These are the visually reviewed renders of the electrically complete 55 x 52 mm revision generated on 2026-09-17.

Routing is complete with zero DRC errors and zero unconnected items; 25 physical DRC warnings remain documented. ERC is 0/0. The provisional nine-pin model has the corrected 0.3937007874 WRL scale and outward orientation.

The six images in this folder were generated from a disposable visualization copy using the verified J2 USB-C model transform: offset `(-4.45, -3.65, 0)`, rotation `(-90, 0, 0)`, scale `(1, 1, 1)`. They show the intended final appearance, but do not prove that the production `board.kicad_pcb` has synchronized that 3D-only transform. PCB land geometry and routing were not changed for these renders.

Connector correction found after these renders: the standard controller plug has eight metal contacts across nine positions, with pin 8 (second from the right when looking directly at the male mating face) physically absent. These images still show nine provisional pins and must not be used as the final J1 population reference.

- `full-board-top-orthographic.png`
- `full-board-bottom-orthographic.png`
- `full-board-perspective.png`
- `usb-c-edge-close-up.png`
- `usb-c-top-close-up.png`
- `usb-c-close-perspective.png`

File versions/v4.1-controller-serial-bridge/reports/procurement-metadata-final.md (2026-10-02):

# NewPlayBridge2 procurement metadata update

Date: 2026-10-01

## Applied substitutions

| References | Final manufacturer / MPN | LCSC | Quantity |
| --- | --- | --- | ---: |
| L1 | Magnetsyc CPN4020H4R7MT | C52741363 | 1 |
| Q4, Q5 | onsemi MMBT3904LT1G | C81464 | 2 |
| U2 | WCH CH340C | C84681 | 1 |
| R5, R7, R9, R10, R11, R14, R15, R41, R42 | 0603WAF1001T5E | C21190 | 9 |

The red power LED D8 remains MPN 19-217/GHC-YR1S2/3T, LCSC C2286.
No C22548, C98363, C20526, or C7464026 identifiers remain in the canonical
source, schematic, PCB metadata, engineering BOM, assembly BOM, or shopping
list.

## L1 engineering review

The electrical inductance remains 4.7 uH +/-20% and the existing 4 x 4 mm
footprint remains unchanged. CPN4020H4R7MT is rated for 2.5 A DC current,
4.7 A saturation current, and approximately 123 milliohm DCR.

The 4.7 A saturation rating comfortably exceeds the AP63203 full-load peak
inductor-current range. The 2.5 A DC rating is acceptable for this board only
while sustained load remains below approximately 1.85 A. It provides 25%
headroom over a 2.0 A load, while the AP63203 datasheet recommends at least
35% DC-current-rating headroom (2.7 A for a sustained 2.0 A load). The 123
milliohm DCR is also above the datasheet's preferred sub-100-milliohm value
for highest efficiency.

Therefore L1 is accepted for the expected sub-2 A board load, subject to the
existing production HOLD and current/temperature verification during bench
qualification. It must not be represented as qualified for continuous 2.0 A
operation without thermal testing or a higher-current inductor.

## V4.1 no-BOM-change guard

- ERC: 0 errors, 0 warnings.
- DRC: 0 violations, 0 unconnected pads, 0 schematic parity issues.
- Connected-net parity: 53/53 named nets, 0 node mismatches.
- Metadata-normalized source, schematic, and PCB signatures exactly match
  their pre-update signatures.
- Q4/Q5 remain SOT-23 with pins 1=B, 2=E, 3=C and retain their DTR/RTS nets.
- CPL, engineering positions, BOM, and shopping-list contents are unchanged.
- PCB routing, Gerbers, drill files, maps, IPC-2581, connectivity export,
  fabrication ZIP, GLB, and board renders were regenerated for V4.1.
- The 190 routed vias are 0.90 mm diameter with 0.40 mm drills.
- Engineering BOM: 80 references.
- Assembly BOM: 77 fitted references.
- Shopping list: 29 purchasing groups totaling 77 fitted components.

Production remains on HOLD pending physical bench tests.

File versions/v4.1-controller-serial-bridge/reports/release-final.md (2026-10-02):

# NewPlayBridge2 final digital verification report

Date: 2026-10-01

## Status

**Digital design/order package: PASS. Production: HOLD pending physical bench tests.**

No bench qualification is claimed. Manual BOOT/RESET is the accepted
programming path.

## Final ESP32 map

| Function | GPIO | U1 pad | Direction / path |
| --- | ---: | ---: | --- |
| PS1 CMD | 19 | 31 | output via R7 1 kOhm |
| PS1 CLK | 32 | 8 | output via R9 1 kOhm |
| PS1 ATT | 21 | 33 | output via R21/R22 and R10 1 kOhm |
| PS1 DATA drive | 33 | 9 | output via R8 100 Ohm to Q1 gate |
| PS1 ACK drive | 27 | 12 | output via R37 100 Ohm to Q2 gate |
| PS1 ACK sense | 34 | 6 | input via R11 |
| Status LED | 25 | 10 | output via R42 to D9 |
| UART2 TX | 17 | 28 | output via R14 1 kOhm to J2 pin 1 |
| UART2 RX | 16 | 27 | input via R15 1 kOhm from J2 pin 4 |
| UART0 TX | 1 | 35 | CH340/debug only |
| UART0 RX | 3 | 34 | CH340/debug only |

GPIO13/U1 pad 16 and GPIO5/U1 pad 29 are unconnected.

## Open-drain stages

- Q1 is a 2N7002 DATA driver: pin 1 gate=`DATA_GATE`, pin 2 source=`GND`,
  pin 3 drain=`J1_DATA`.
- Q2 is a 2N7002 ACK driver: pin 1 gate=`ACK_GATE`, pin 2 source=`GND`,
  pin 3 drain=`J1_ACK`.
- Gate resistors R8/R37 remain 100 Ohm. The proven external series parts
  R7/R9/R10/R14/R15 remain 1 kOhm, MPN `0603WAF1001T5E`, LCSC `C21190`.

## BOOT/RESET topology

- SW1 manually pulls `ESP_EN` low.
- SW2 manually pulls `ESP_BOOT`/GPIO0 low.
- Retained Q4 MMBT3904: base from DTR through R39, emitter=`CH340_RTS`,
  collector=`ESP_EN`.
- Retained Q5 MMBT3904: base from RTS through R40, emitter=`CH340_DTR`,
  collector=`ESP_BOOT`/GPIO0.
- Q4/Q5 pin semantics are 1=B, 2=E, 3=C. Automatic behavior is not claimed
  as bench-qualified; the manual switches are accepted.

## Connectors and mechanics

- J1: 1 NC, 2 CMD, 3 CLK, 4 GND, 5 ATT, 6 DATA, 7 ACK, 8 PS1 power, 9 NC.
  Both retention/shell pads are pad 4/GND.
- J2: 1 TX, 4 RX, 7 GND; all other signal pins NC. Both retention/shell pads
  are pad 7/GND.
- J1/J2 anchors remain `(14.0,48.5)` and `(39.2,48.5)` mm. Their exact local
  HC-USB3.0-L168-ZP models use zero translation/rotation and unit scale.
- All nine connector pins and both retention legs cross the 1.6 mm PCB and
  protrude approximately 1.200096 mm below it for soldering.

## V4.1 fabrication adjustment

- 190/190 routed through-vias are 0.90 mm diameter with 0.40 mm drills.
- The minimum routed-via annular ring is 0.25 mm.
- The generated Excellon report identifies exactly 190 0.40 mm `ViaDrill`
  hits; smaller drills belong only to component pads.
- Local ESP32, CH340C, and USB-C fanout routing was adjusted without changing
  the schematic, component placement, connector anchors, GPIO map, or BOM.
- The USB-C VBUS escape includes a 0.15 mm local neckdown; all other board
  rules and the explicit ANTS via constraints pass DRC.

## Validation

- ERC: 0 errors, 0 warnings.
- DRC: 0 violations, 0 unconnected pads, 0 schematic-parity issues.
- Source/schematic/PCB: 80/80 references, 53/53 connected nets, 227/227
  connected nodes, 0 value/footprint or MPN/LCSC mismatches.
- 3D models: 77/80 footprints. The only omissions are intentionally
  unpopulated plated holes TP1/TP2/TP3; every fitted footprint is modeled.
- Engineering BOM/positions: 80/80 references.
- Assembly BOM/CPL: 77/77 references, exact reference-set match, no blank
  LCSC codes.
- Fabrication ZIP: 13 entries and passes archive integrity testing.
- GLB: valid binary glTF v2 container.

## Core hashes

- schematic: `a37339ff2e3cd012f82b29cc9e7a413b695dbe06d35fb2b2dbc70e65833c2766`
- PCB: `8fd929cdf0b25af03990034cb2438cf1a9f9e3fe6bf505f63394370eb3d723d0`
- source netlist: `7104430e672968607f18d1a9db0ea59e10c2b096bb1d0f0d475dc129700e53ef`
- GLB: `31fca05641d61d162e14c98a57e09779deead4df406bec145a6c0ee69dee7d42`
- fabrication ZIP: `7c78ebbeda8da288dd8440135660bd6ea79eea3ad4738a35f8e296a6d68de48b`
- assembly BOM: `7c8db1dd1eff2c2cde9a478bdd75c6df08e845f80563c4fcab68b336eed56539`
- CPL: `688b4a6d6405525f1ae15db4892079bc81b94ff4be9aa11bdee67e2d655c9458`

See `reports/bench-test.md`. Do not release to production until its required
physical measurements have been completed and recorded.

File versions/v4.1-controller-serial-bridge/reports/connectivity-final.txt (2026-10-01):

NEWPLAYBRIDGE2 FINAL CONNECTIVITY / PIN-DIRECTION / METADATA CHECK

PASS: GPIO19_CMD - nodes=[('R7', '1'), ('U1', '31')]
PASS: GPIO32_CLK - nodes=[('R9', '1'), ('U1', '8')]
PASS: GPIO21_ATT - nodes=[('R21', '1'), ('U1', '33')]
PASS: GPIO33_DATA - nodes=[('R8', '1'), ('U1', '9')]
PASS: GPIO27_ACK_DRIVE - nodes=[('R37', '1'), ('U1', '12')]
PASS: GPIO34_ACK - nodes=[('R11', '1'), ('U1', '6')]
PASS: GPIO25_STATUS - nodes=[('R42', '1'), ('U1', '10')]
PASS: GPIO17_UART2_TX - nodes=[('R14', '1'), ('U1', '28')]
PASS: GPIO16_UART2_RX - nodes=[('R15', '2'), ('U1', '27')]
PASS: Q1 gate - pin1 on DATA_GATE
PASS: Q1 source - pin2 on GND
PASS: Q2 gate - pin1 on ACK_GATE
PASS: Q2 source - pin2 on GND
PASS: Q1 symbol - Transistor_FET:2N7002
PASS: Q1 drain - pin3 on J1_DATA
PASS: Q2 symbol - Transistor_FET:2N7002
PASS: Q2 drain - pin3 on J1_ACK
PASS: Q4 B/E/C - B=DTR_BASE, E=CH340_RTS, C=ESP_EN
PASS: Q5 B/E/C - B=RTS_BASE, E=CH340_DTR, C=ESP_BOOT
PASS: R7 proven value/MPN - 1k PS1 CMD, 0603WAF1001T5E, C21190
PASS: R9 proven value/MPN - 1k PS1 CLK, 0603WAF1001T5E, C21190
PASS: R10 proven value/MPN - 1k PS1 ATT, 0603WAF1001T5E, C21190
PASS: R14 proven value/MPN - 1k UART2 TX, 0603WAF1001T5E, C21190
PASS: R15 proven value/MPN - 1k UART2 RX, 0603WAF1001T5E, C21190
PASS: U1 pad 10 - GPIO25_STATUS
PASS: U1 pad 12 - GPIO27_ACK_DRIVE
PASS: U1 pad 16 - unconnected-(U1-IO13-Pad16)
PASS: U1 pad 29 - unconnected-(U1-IO5-Pad29)
PASS: J1 signal+shell grounds - 3 pads numbered 4 on GND
PASS: J2 signal+shell grounds - 3 pads numbered 7 on GND
PASS: J2 pad 1 - J2_TX
PASS: J2 pad 4 - J2_RX
PASS: J2 pad 7 - GND
PASS: J1 pad 2 - J1_CMD
PASS: J1 pad 3 - J1_CLK
PASS: J1 pad 4 - GND
PASS: J1 pad 5 - J1_ATT
PASS: J1 pad 6 - J1_DATA
PASS: J1 pad 7 - J1_ACK
PASS: J1 pad 8 - PS1_7V6_RAW

Checks passed: 40
Checks failed: 0

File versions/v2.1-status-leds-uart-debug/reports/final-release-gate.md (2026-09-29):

# V2.1 final release gate

- Date: 2026-09-25
- Board SHA-256: `1a1a1da305ea273c94f223b624208c1a9615784997cdfd1591985f96933a2df3`
- DRC errors: 0
- DRC unconnected: 0
- Approved historical warnings: 3 `track_dangling`
- ERC errors/warnings: 0/0
- Schematic/PCB parity findings: 0
- FabDesk release gate: PASS
- Order state: DO-NOT-ORDER pending human approval

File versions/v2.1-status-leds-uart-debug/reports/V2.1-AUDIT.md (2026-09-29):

# PlayBridge V2.1 final audit — 2026-09-25

## Authoritative design

- PCB SHA-256: `1a1a1da305ea273c94f223b624208c1a9615784997cdfd1591985f96933a2df3`
- Schematic SHA-256: `1858ee6e73ef7d452be634f165da4e10daeaf17e959187c368d39088004af4d0`
- Netlist SHA-256: `0368790999dae2bda2095eb750de953a6a60f364de7f9eb6ac775d2783a27dc2`
- Board: 56.295 x 62.000 mm, four copper layers, 1.20 mm thick.
- J4 is absent. TP1 remains the original 3V3 point.
- F.Silkscreen labels: J1 (2.500,46.200), J2 (20.000,44.500), J3 (52.500,17.000), SERVICE / DEBUG (46.700,49.700) mm. The planned V2.2 third SNAC-style connector will take J4.

## Electrical identity

- D1: green STATUS LED, Everlight `19-217/GHC-YR1S2/3T`, LCSC `C72043`; `STATUS_LED` from ESP32 module pin 26 through R13.
- R13: 1 kΩ UNI-ROYAL `0603WAF1001T5E`, LCSC `C21190`.
- D6: red always-on POWER LED, KENTO `KT-0603R`, LCSC `C2286`; cathode to GND.
- R29: 1 kΩ UNI-ROYAL `0603WAF1001T5E`, LCSC `C21190`; 3V3 to `POWER_LED_A`.
- TP2 GND: (43.500,54.000) mm; TP3 UART_TX: (46.700,54.000) mm; TP4 UART_RX: (49.900,54.000) mm.
- Test-hole geometry: 2.0 mm plated copper, 1.0 mm finished hole, 3.2 mm pitch; DNP/no purchased component.

## Mechanical/usability audit

- TP2 copper to J2 courtyard/body envelope: 8.975 mm.
- Debug copper to bottom edge: 7.000 mm; TP4 copper to right edge: 5.395 mm.
- Debug row to BOOT courtyard: approximately 7.425 mm.
- RESET and BOOT remain top-accessible. STATUS and PWR are readable and visible.
- J1/J2 mouths face outward through the lower edge; J3 USB-C faces outward through the right edge.
- Antenna region, outline, connectors, switches, and unrelated placement/copper are unchanged.

## Verification

- DRC: 0 errors; 0 unconnected; only three approved historical `track_dangling` warnings.
- ERC: 0 errors, 0 warnings. Schematic/PCB parity: 0. FabDesk release gate: PASS.
- Reports: `final-release-drc.rpt`, `final-release-erc.rpt`.

## Fresh release artifacts

- Generic: `exports/gerbers/`, `exports/gerbers/board.drl`, `exports/bom.csv`, `exports/positions.csv`, `exports/assembly-bom.csv`, `exports/assembly-cpl.csv`, `exports/netlist.net`, `exports/fabrication.zip`.
- JLCPCB: `ordering/jlcpcb-bom.csv`, `ordering/jlcpcb-cpl.csv`, `ordering/gerbers-jlcpcb.zip`.
- D6/R29 are present in both assembly sets. TP1–TP4 are excluded from assembly BOM/CPL but remain in bare-board fabrication data. J4 is absent.
- Accepted renders: `renders/service-debug-full-top.png`, `renders/service-debug-close.png`.

## Artifact hashes

- `exports/fabrication.zip`: `e9d03d99454d954de3735937dcde97e5e4bd061d33e074a3a4b483aed9a517ab`
- Gerber/drill set manifest hash: `b1ce125daa3033edb0288c89d64e4c2e00f4970826d6f4aae0074c7f7dd0a6b0`
- `exports/assembly-bom.csv`: `77ad00e2c9268b5353d16dc4867df91f27e2c11c09419f5c55171346396c80fa`
- `exports/assembly-cpl.csv`: `a7dc2abaf22eea658672b5ca4eeb491b89b85bff55613b182417f520f6b2779e`
- `ordering/jlcpcb-bom.csv`: `362af10cb74084845b3440dcdc97842ee0becfff98721d71c47a5d02e554f191`
- `ordering/jlcpcb-cpl.csv`: `5d506d808bb20b2ac4206f4502e4b090c33d59e9e54dea799f1549c17d84139d`
- `ordering/gerbers-jlcpcb.zip`: `df883a90075e0b347b25f078679040470e5020530c69fcce4d5c8430f2af641e`
- `renders/service-debug-full-top.png`: `383c5050c014bc21f2286277cde47892aabb3d7aaaf03e59859af51b7aeb5a22`
- `renders/service-debug-close.png`: `8d876d6af57bd42fa26932f45aeba3c829c0efe7d64f4039b675d4db12052a4d`

**DO NOT ORDER** until final human render/mechanical review, BOM/CPL rotation preview, substitutions, and live-stock checks are approved.

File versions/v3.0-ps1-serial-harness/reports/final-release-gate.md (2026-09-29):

# V3.0 J2 serial implementation gate

- Date: 2026-09-25
- PCB DRC errors: 0
- PCB unconnected pads: 0
- Approved historical warnings: 3 `track_dangling` UART0 test stubs
- ERC errors/warnings: 0/0
- Schematic/PCB parity findings: 0
- J2 serial pins: GPIO17/UART2 TX, GPIO16/UART2 RX, GND
- Bench result: PASS, confirmed by the user/team for the tested PoC; supporting
  setup photos are preserved under `reports/evidence/`
- Design gate: PASS
- Manufacturing package gate: PASS — fresh V3.0 Gerbers, drill, BOM, CPL,
  netlist and fabrication archives were regenerated and include J2/R30/R31
- Archive integrity: PASS — both ZIP archives pass `zip -T`
- Assembler checkout gate: PENDING — live stock, substitutions and uploaded
  BOM/CPL rotation/placement previews require final human review
- Order state: HOLD until the assembler checkout gate passes

## J1/J2 sourcing replacement

- Replaced unavailable/pre-order Molex C3197928 with ready-for-assembly Hong
  Cheng HC-USB3.0-L168-ZP / JLCPCB C7501856.
- All nine signal-pad centers are unchanged; no routed copper moved.
- Official C7501856 shell slots, courtyard, footprint and WRL/STEP model are
  included locally.
- New top, perspective, lower-edge and bottom renders confirm correct seating
  and outward-facing connector mouths.

## Release hashes

- PCB: `9f35f14a72d0283f639ca8e53e08e3d4ad675e4c4d4937ba2a34dda01c05f976`
- Schematic: `73d8a4e9e3b117d3dc982e4980389b215d62b1fa0540ba7ee33bbf3e6a9babcf`
- Generic fabrication ZIP: `f9774fabc9b61e5b25378fa0577895634e06d6d3ad8792c2b2a0efb07ab0fc4d`
- JLCPCB Gerber ZIP: `79cee6ab2a2817c448c97eeb5dafd0ae774262c85803f4c59c31d65bda27bab0`
- JLCPCB BOM: `843957971777767e52d6aeeaf623a05dd8f5f9a323449939d0142b77e3f60fef`
- JLCPCB CPL: `686bd018bfcfe1f596070ecc0887670ec0c4ec81c907151657b2d36fe336b2dd`

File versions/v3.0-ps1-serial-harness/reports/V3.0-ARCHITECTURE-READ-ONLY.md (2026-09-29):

# PlayBridge architecture audit — corrected read-only report

Date: 2026-09-25  
Status: planning only — **DO NOT ORDER**  
Current project: PlayBridge V3.0 PS1 serial harness
PCB baseline SHA-256: `1a1a1da305ea273c94f223b624208c1a9615784997cdfd1591985f96933a2df3`

This report is documentation only. It does not authorize changes to the PCB,
netlist, footprints, manufacturing outputs, folder name, project name or
firmware.

## Corrected intended architecture

J4 is **not** another controller/SNAC bus and is **not** an alternate copy of
J1. The intended future data path is:

`PC/browser -> Wi-Fi -> PlayBridge ESP32 -> UART GPIO17/TX and GPIO16/RX -> J4 -> donor-cable harness -> PS1 serial port`

J4 uses a USB-A connector only as a readily available nine-contact physical
interconnect. It is explicitly **NOT USB**. A normal USB host, charger or device
must never be connected to J4.

The provisional J4 electrical roles are only:

- PlayBridge UART TX on ESP32 GPIO17;
- PlayBridge UART RX on ESP32 GPIO16;
- GND.

Exact J4 contact numbers are intentionally unassigned until the PS1 serial
harness pinout and electrical requirements are received. All other J4 contacts,
including any contact that resembles USB VBUS and all shell pads, remain
reserved/NC. No J4 power rail, console-power input, USB data pair, controller
signal or board 3V3 connection is assumed.

## Preserved connector identities

- J1 remains the existing active PS1 controller/SNAC donor-harness bus with its
  current pinout and protection. Nothing in the J4 serial proposal changes or
  parallels J1.
- J2 remains electrically all-NC/reserved. Contacts 1–9 and the shell pads have
  no assigned nets.
- J3 remains the real USB-C power/program/debug connector and its orientation,
  USB-UART circuitry and power path remain unchanged.
- J4 serial traffic and the J1 controller/SNAC bus must remain electrically
  separate.

## Existing SERVICE/DEBUG UART audit

The inherited TP2/TP3/TP4 row is not presently connected to GPIO16/GPIO17.

| Test point | Existing net | Existing connections | Result |
| --- | --- | --- | --- |
| TP2 | GND | Board ground | Passive ground probe/harness reference |
| TP3 | `UART_TX` | ESP32 module pin 35, GPIO1/U0TXD; CH340C pin 3; TP3 | UART0 transmit test point |
| TP4 | `UART_RX` | ESP32 module pin 34, GPIO3/U0RXD; CH340C TX through R16/R17 divider; TP4 | UART0 receive test point |

ESP32 module pin 28/GPIO17 and pin 27/GPIO16 are currently unassigned in the
board netlist. They are therefore available candidates for the proposed J4
serial link, subject to teammate firmware review and confirmation that no
implicit firmware or boot-time use exists.

The present SERVICE/DEBUG row may remain a passive UART0 test interface while
J4 uses the separate GPIO17/GPIO16 UART. This is an architectural observation,
not routing approval.

### Drive-contention rule

An external USB-UART adapter and a PS1 serial harness must never drive the same
UART line simultaneously. Series resistance can limit fault current but does
not turn two push-pull transmitters into a safe shared bus.

The existing TP4 receive net can also be driven by the onboard CH340C path.
Attaching an external adapter to TP4 while the onboard USB-UART is powered or
active can cause contention. Future documentation and silkscreen must specify
the allowed connection/power state, or hardware isolation must enforce it.

If the future J4 design keeps GPIO16/GPIO17 separate from UART0, the present
TP2/TP3/TP4 row does not electrically share the PS1 serial link. If later
requirements move debug access onto GPIO16/GPIO17, the following isolation
options must be evaluated before routing.

## UART isolation options to evaluate

### 1. Series isolation resistors

Place series resistors near the ESP32 and/or external connector. They reduce
edge ringing and limit current during accidental contention. They are compact
and preserve a direct UART path.

They do not prevent two transmitters from driving opposite logic levels, do
not guarantee powered-off isolation and do not solve incompatible voltage
levels. This option is acceptable only after directionality, voltage levels and
the permitted connection states are proven.

### 2. UART mux or analog/digital switch

A mux/switch can enforce one selected external source, provide a safe default
state and isolate an unpowered endpoint. The device must be qualified for the
actual PS1 serial voltage range, directionality, bandwidth, power-off behavior,
leakage and fail-safe state. Selection behavior during reset and firmware
startup must be defined.

This is the appropriate class of solution if GPIO16/GPIO17 must be shared
between the PS1 harness and a debug adapter, but no device or topology is
selected in this report.

### 3. Separate debug UART

Retain the existing UART0/CH340/TP2–TP4 path for programming and service, while
dedicating GPIO17/TX and GPIO16/RX to J4. This avoids normal signal sharing and
minimizes contention between the debug and PS1 serial domains. Firmware UART
availability, boot logging, pin ownership and PS1 protocol timing must still be
confirmed.

No option is chosen or routed here. The teammate firmware and PS1 electrical
requirements are prerequisites.

## Mechanical planning fact

The coherent third-shell location remains the vacant lower-right board edge:

- proposed J4 origin: `(40.525, 50.525) mm`;
- proposed rotation: `0°`;
- exact approved J1/J2 Molex 48393-0003 connector family and registered
  `Molex_48393-0003_TraceParts_exact_visual.wrl` model;
- mouth facing outward through the lower edge;
- 18.000 mm connector-origin pitch from J2.

At that location, J4 physically overlaps the present TP2/TP3/TP4 area, so the
three SERVICE/DEBUG holes would have to be relocated if J4 is implemented. The
planning locations remain:

- TP2 GND: `(34.000, 44.500) mm`;
- TP3 TX: `(37.200, 44.500) mm`;
- TP4 RX: `(40.400, 44.500) mm`.

These coordinates retain 3.2 mm pitch but are not authorized placements. They
require future DRC, routing, silkscreen, probe-access, populated connector,
cable-overmold, enclosure and strain-relief validation.

The proposed J4 courtyard is X=36.525–51.525 mm. It leaves 3.000 mm to the J2
courtyard, 4.770 mm to the right board outline and 1.950 mm vertical courtyard
clearance to BOOT. The nominal connector-body gap at 18 mm pitch is about
4.200 mm. Actual donor-cable overmold fit remains unproven.

Future silkscreen must preserve the readable J1/J2/J3 identities and add clear
`J4` and `NOT USB` markings. Final production renders must not contain editor
selection/pink element borders or annotation clutter.

## V3.0 combined-subsystem boundary

The PC-wireless PS1 game-loader work is being evaluated in this **V3.0 major
development line**. Renaming the project does not prove the teammate subsystem,
authorize a board merge, or authorize manufacturing.

The PC/browser is the game-image source. Do not assume:

- an SD slot or mandatory local storage;
- a CD-drive bus connection;
- a parallel expansion interface;
- reuse of J1/J4 controller or serial nets for game-stream traffic.

Any SD or other local storage remains optional until buffering, offline and
capacity requirements are known. Game-stream traffic and the PS1 game-data
interface must remain electrically separate from controller/SNAC buses and
from the J4 PS1 serial service path unless a later, documented interface review
proves otherwise.

Do not begin the V3.0 schematic/PCB merge until the teammate provides:

1. Firmware and protocol implementation.
2. Exact PS1 serial electrical levels and voltage tolerances.
3. Signal directionality, including startup, idle and power-off behavior.
4. Baud rate, sustained/burst throughput and latency targets.
5. Exact PS1 serial donor-harness connector/contact pinout.
6. Supported PS1 hardware revisions and any revision-dependent behavior.
7. Power-source behavior, rail requirements, current peaks, sequencing and
   backfeed constraints.

The broader combined-release review will additionally need the teammate's
schematic, PCB/netlist, wireless protocol, buffering/storage requirements and
fault-containment plan before deciding whether a combined PCB is appropriate.

## Release hold

`ordering/DO-NOT-ORDER.md` remains active. Do not create or refresh Gerbers,
drills, BOM/CPL, pick-and-place data, fabrication ZIPs or ordering packages.
No J4 contact assignment, isolation component, placement or route is approved
until the required firmware, protocol, electrical and mechanical inputs are
available and a later implementation passes DRC, ERC, schematic parity,
connectivity and populated-render inspection.

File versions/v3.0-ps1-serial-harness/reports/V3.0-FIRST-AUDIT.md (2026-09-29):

# PlayBridge V3.0 first audit — read-only design baseline

Date: 2026-09-25  
Status: **DO NOT ORDER — decision gate not passed**

Active path: `/Users/amliomnie/fabdesk/wireless-pc-to-ps1-controller-bridge/versions/v3.0-ps1-serial-harness`

This audit changed no PCB, netlist, schematic, footprint, route, render, export, or manufacturing artifact. The only created file is this report. No build, route, DRC/ERC, render, or export command was run.

## Baseline and capability

- Inherited PCB SHA-256 before this audit: `1a1a1da305ea273c94f223b624208c1a9615784997cdfd1591985f96933a2df3`.
- That hash exactly matches the frozen V2.1 hash recorded in `reports/V2.1-AUDIT.md`; the inherited schematic and netlist hashes also match that record: `1858ee6e73ef7d452be634f165da4e10daeaf17e959187c368d39088004af4d0` and `0368790999dae2bda2095eb750de953a6a60f364de7f9eb6ac775d2783a27dc2`.
- Board baseline: 56.295 x 62.000 mm, four copper layers. J4 is absent.
- Existing functions are an ESP32-WROOM-32 Wi-Fi MCU, the J1 nine-contact **NOT-USB** PS1 controller donor-harness interface, the electrically unused J2 nine-contact **NOT-USB** receptacle, and the real J3 USB-C power/program/debug port through the onboard CH340C USB-UART path.
- This hardware inventory does not prove the missing PS1 serial protocol or full game-image streaming. No SD slot, CD-drive bus, parallel expansion, graphics output, storage architecture, or game-stream path is assumed.

## J2 versus J4 decision

J2 is physically present at `(22.525, 50.525) mm`, faces outward through the lower edge, uses the same approved keyed nine-contact Molex 48393-0003 connector family as J1, and has no nets on contacts 1-9 or its shell pads. Its value and documentation identify it as the reserved rear-serial **NOT-USB** interface. Those facts make J2 the preferred candidate for the requested future path:

`PC/browser -> Wi-Fi -> ESP32 -> GPIO17/TX + GPIO16/RX + GND -> keyed NOT-USB harness -> PS1 serial port`

No known evidence presently requires a distinct J4:

- electrically, J2 is completely free;
- mechanically, it is already edge-mounted in the intended connector family and orientation;
- no enclosure, cable-overmold, strain-relief, or mating-access conflict has been supplied;
- no simultaneous second use of J2 has been defined;
- its future reference/value/silkscreen can identify the serial role and **NOT USB** warning without creating a third connector.

Therefore: **do not add J4 at this gate**. J2 is recommended in principle, but no J2 contact assignment or copper change is approved until the missing harness and electrical inputs are supplied. Because J4 is not justified, this report intentionally provides no candidate J4 placement. A distinct J4 would become defensible only if evidence proves J2 must remain available simultaneously for a different interface, cannot mate or clear the enclosure/harness, or cannot be labeled safely. The previously discussed lower-right third-shell concept would overlap TP2-TP4 and require their relocation, adding mechanical and routing risk.

## UART and contention findings

- TP2 is GND.
- TP3 is `UART_TX`: ESP32 module pin 35, GPIO1/U0TXD, shared with CH340C pin 3 (its receive input).
- TP4 is `UART_RX`: ESP32 module pin 34, GPIO3/U0RXD, shared with CH340C pin 2 through the existing R16 1 kOhm / R17 2 kOhm divider.
- TP2/TP3/TP4 therefore expose UART0 on GPIO1/GPIO3; they do **not** expose GPIO16/GPIO17.
- ESP32 module pin 27/GPIO16 and pin 28/GPIO17 have no assigned nets in the inherited netlist. Their firmware ownership and boot-time behavior are still unknown.

If the PS1 serial link remains on GPIO17/GPIO16, it is electrically separate from the onboard CH340C and TP3/TP4 UART0 path. Retaining this separate debug UART is the evidence-supported recommendation and avoids normal PS1/debug contention.

An external adapter correctly driving TP4 can still contend with the onboard CH340C transmitter whenever that device is powered or active; an adapter incorrectly driving TP3 can contend with ESP32 UART0 TX. Do not connect adapter power, and do not permit simultaneous transmitters, until allowed power/connection states are documented. Series resistors can limit fault current and ringing but cannot arbitrate push-pull drivers or guarantee powered-off isolation. A mux/switch is warranted only if one ESP32 UART must be shared and must then be selected for verified voltage range, bandwidth, leakage, fail-safe state, reset behavior, and power-off isolation. Current evidence favors neither added series isolation nor a mux on GPIO16/GPIO17 because the separate UART0 debug path already exists.

## Missing prerequisites

Do not assign contacts or begin implementation until the following are authoritative:

1. Teammate schematic/netlist and interface ownership.
2. Firmware and PS1 serial protocol implementation.
3. Exact J2/J4 donor-harness contact pinout, connector views, keying, and cable wiring.
4. PS1 serial logic levels and tolerances at every endpoint.
5. TX/RX direction, idle state, reset/startup behavior, and powered-off behavior.
6. Baud rate, sustained/burst throughput, latency, and buffering requirements.
7. Supported PS1 revisions and revision-dependent behavior.
8. Power-source/rail requirements, current, sequencing, grounding, and backfeed constraints.
9. Enclosure opening, connector access, cable-overmold, bend radius, and strain-relief dimensions.

## Next-decision gate

Keep `ordering/DO-NOT-ORDER.md` active. The next decision is: after all prerequisites above are reviewed, explicitly approve **J2 reuse** or document the concrete requirement that forces **J4**. Only then may a scoped electrical/mechanical proposal assign TX, RX, and GND, choose protection/isolation, and proceed to schematic/PCB work and fresh verification. Browser/Wi-Fi/ESP32/PS1 digital-button operation alone is not acceptance evidence for game-image streaming.

Post-write integrity verification must confirm the PCB SHA-256 remains `1a1a1da305ea273c94f223b624208c1a9615784997cdfd1591985f96933a2df3`. The report's own SHA-256 is stated in the audit handoff because embedding a file's hash inside itself is self-referential.

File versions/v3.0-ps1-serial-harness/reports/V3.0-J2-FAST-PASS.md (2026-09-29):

# PlayBridge V3.0 J2 serial fast-pass

Date: 2026-09-25  
Status: **layout and user-confirmed bench PoC complete; order checkout review remains**

## Result

J2 now uses a dedicated ESP32 UART and does not reuse the controller/SNAC GPIOs or the USB programming/debug UART.

| Function | ESP32 signal | Module pad | Board path | J2 contact |
| --- | --- | ---: | --- | ---: |
| PS1 serial transmit | GPIO17 / UART2 TX | U1.28 | `U2_TX_RAW` -> R30 1 kOhm -> `PS1_RXD` | J2.1 |
| PS1 serial receive | GPIO16 / UART2 RX | U1.27 | `PS1_TXD` -> R31 1 kOhm -> `U2_RX_RAW` | J2.4 |
| Signal reference | GND | ground plane | GND | J2.7 |

J2 contacts 2, 3, 5, 6, 8 and 9 remain NC. J2 is a keyed physical harness connector and is explicitly **NOT USB**.

The existing interfaces remain separate:

- J1 controller/SNAC GPIOs remain GPIO19, GPIO21, GPIO32, GPIO33 and GPIO34.
- USB-C programming/debug remains UART0 on GPIO1 TX and GPIO3 RX through the CH340C path.
- J2 serial uses UART2 on GPIO17 TX and GPIO16 RX.

## Verification

- PCB DRC: 0 errors introduced; 0 unconnected pads.
- Schematic ERC: 0 errors, 0 warnings.
- PCB/schematic parity: 0 issues.
- Three inherited local-override warnings remain for intentionally dangling UART0 test stubs (`UART_TX`/`UART_RX`). They are unrelated to J2.
- Board zones were refilled and the final PCB was saved by KiCad CLI.

Evidence files:

- `final-j2-drc.rpt`
- `final-j2-erc.rpt`
- `final-j2-parity.rpt`

## Bench evidence and release scope

On 2026-09-25 the user confirmed that the teammate firmware/protocol and
electrical PoC passed on the tested hardware and supplied two photos of the
powered ESP32 development-board setup. The photos are preserved under
`reports/evidence/`; they document the physical setup, while the functional
result remains a user/team bench report rather than a behavior visible in the
still images.

R30 and R31 remain 1 kOhm series resistors; they are not level shifters. The
accepted result applies only to the tested console, donor harness, firmware and
protocol configuration. It does not claim support for untested console
revisions or full PS1 serial handshaking. The remaining
`ordering/DO-NOT-ORDER.md` hold concerns assembler upload/preview, stock,
rotation and substitution review—not J2 routing or the accepted bench result.

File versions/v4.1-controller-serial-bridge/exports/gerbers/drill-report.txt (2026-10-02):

Drill report for board.kicad_pcb
Created on 2026-10-01T12:58:51

Copper Layer Stackup:
    =============================================================
    L1 :  F.Cu                      front
    L2 :  B.Cu                      back

Drill file 'board-PTH.drl' contains
    plated through holes:
    =============================================================
    T1  0.300mm  0.0118"  (12 holes))
    T2  0.400mm  0.0157"  (190 holes))
    T3  0.600mm  0.0236"  (8 holes)  (with 8 slots)
    T4  0.700mm  0.0276"  (18 holes))
    T5  1.000mm  0.0394"  (3 holes))

    Total plated holes count 231

Drill file 'board-NPTH.drl' contains
    unplated through holes:
    =============================================================
    T1  0.650mm  0.0256"  (2 holes))

    Total unplated holes count 2

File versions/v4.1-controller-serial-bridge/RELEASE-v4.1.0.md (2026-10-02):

# PlayBridge V4.1.0 fabrication revision

Date: 2026-10-01

V4.1.0 preserves the electrically verified V4.0 controller/serial bridge while
updating the PCB for the ANTS fabrication limits. Every routed through-via is
now 0.90 mm in diameter with a 0.40 mm drill, providing a 0.25 mm annular ring.
The affected ESP32, CH340C, and USB-C escape routing was adjusted without
changing the schematic, component placement, connector mechanics, firmware
GPIO map, or BOM.

The regenerated digital release gate passes:

- ERC: 0 violations.
- DRC: 0 violations and 0 unconnected items.
- Routed-via audit: 190/190 vias at 0.90/0.40 mm.
- Excellon audit: 190 routed `ViaDrill` hits at 0.40 mm.
- Schematic/PCB connectivity remains 53 named nets and 227 connected nodes.
- Fabrication and ordering ZIPs contain the complete 13-file Gerber/drill set
  and pass archive-integrity testing.
- Updated board SVG, GLB, top, bottom, and perspective renders are included.

This is a fabrication adjustment, not production qualification. Production
remains on hold until the physical measurements in `reports/bench-test.md`
pass and are recorded. The Magnetsyc CPN4020H4R7MT remains accepted for the
expected sub-2 A load but is not qualified for sustained 2.0 A operation
without thermal testing.

Order files are under `exports/`; convenient vendor-facing copies are under
`ordering/`.

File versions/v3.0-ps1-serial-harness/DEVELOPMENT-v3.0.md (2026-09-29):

# PlayBridge V3.0 development plan

V3.0 starts from the validated, frozen V2.1 PCB and evaluates a dedicated
PS1 serial-port donor harness. The requested physical path is ESP32 GPIO17/TX,
GPIO16/RX and GND through a keyed USB-A-style connector marked `NOT USB`.

## Fixed baseline

- Keep J1 and J2 at their validated lower-edge positions and orientations.
- Keep J3 USB-C, ESP32/antenna geometry, RESET, BOOT, STATUS, PWR, and the
  TP2 GND / TP3 TX / TP4 RX SERVICE / DEBUG row functional and accessible.
- Preserve the V2.1 board outline and unrelated placement/copper unless a
  measured mechanical constraint makes a scoped change necessary.

## Architecture gate: J2 or J4

1. Resolve why the physically present, all-NC J2 cannot serve the PS1 serial
   harness, because that was its historical reserved purpose.
2. Add J4 only if the teammate architecture or mechanical requirements prove a
   distinct third connector is necessary.
3. For either connector, use the approved J1/J2 family and exact 3D
   registration, mouth outward, with unambiguous `NOT USB` silkscreen.
4. Assign only TX, RX and GND provisionally; reserve all other contacts until
   the teammate provides the exact harness pinout and electrical specification.
5. Keep UART0 SERVICE/DEBUG on GPIO1/GPIO3 separate from the proposed PS1 link
   on GPIO17/GPIO16. If sharing is later required, select and prove series
   isolation, a mux/switch, or another UART before routing.
6. Check enclosure, cable-overmold and strain-relief clearance for the selected
   connector layout.
7. Require DRC 0 errors, ERC 0/0, parity 0, zero unconnected items and populated
   render review before any manufacturing outputs are regenerated.

Ordering remains blocked until the teammate firmware, protocol, exact logic
levels, directionality, baud/latency targets, harness wiring and supported PS1
revisions are recorded and the V3.0 architecture is explicitly approved.

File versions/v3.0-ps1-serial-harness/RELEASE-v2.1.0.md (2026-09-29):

# PlayBridge V2.1 review candidate

Status: **DO NOT ORDER — pending final human review**.

V2.1 preserves the validated V2.0 design and adds two clearly identified indicators plus a connector-free 3.3 V UART service interface. D1/R13 is the firmware STATUS indicator on ESP32 module pin 26. D6/R29 is the always-on 3V3 POWER indicator. The former J4 header is absent.

Top silkscreen identifies J1, J2, J3, and the SERVICE / DEBUG row. V2.1 deliberately has no fabricated J4 reference; the planned third SNAC-style connector in V2.2 will use J4.

The SERVICE/DEBUG row is TP2 GND (43.500,54.000), TP3 UART_TX (46.700,54.000), and TP4 UART_RX (49.900,54.000), with 3.200 mm pitch and 2.0/1.0 mm plated pad/hole geometry. TP1 remains 3V3.

Final 2026-09-25 gates: DRC 0 errors, 0 unconnected, three approved historical `track_dangling` warnings; ERC 0/0; parity 0; release gate PASS. Manufacturing and ordering files were regenerated from PCB SHA-256 `1a1a1da305ea273c94f223b624208c1a9615784997cdfd1591985f96933a2df3`.

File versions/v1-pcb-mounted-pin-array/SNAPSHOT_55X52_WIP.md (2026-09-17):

# 55 x 52 mm work-in-progress checkpoint

This branch preserves the 55 x 52 mm PlayBridge board revision captured on
2026-09-17 while FabDesk continued work on the compact successor.

This is an engineering checkpoint, not a fabrication release. Routing and
release verification were still in progress when it was captured. Use the
latest validated branch or release for manufacturing.

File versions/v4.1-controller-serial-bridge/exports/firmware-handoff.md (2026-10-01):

# NewPlayBridge2 firmware handoff

## Verified ESP32 GPIO map

| Function | GPIO | ESP32 module pad | Direction |
| --- | ---: | ---: | --- |
| PS1 CMD | 19 | 31 | Output through R7, 1 kOhm |
| PS1 CLK | 32 | 8 | Output through R9, 1 kOhm |
| PS1 ATT | 21 | 33 | Output through R21/R22 and R10, 1 kOhm interface resistor |
| PS1 DATA drive | 33 | 9 | Output through 100 Ohm gate resistor R8 to Q1 |
| PS1 ACK drive | 27 | 12 | Output through 100 Ohm gate resistor R37 to Q2 |
| PS1 ACK sense | 34 | 6 | Input through R11 |
| Status LED | 25 | 10 | Output through R42 to D9 |
| UART2 TX | 17 | 28 | Output through R14, 1 kOhm, to J2 pin 1 |
| UART2 RX | 16 | 27 | Input through R15, 1 kOhm, from J2 pin 4 |
| UART0 TX | 1 | 35 | CH340C programming/debug only |
| UART0 RX | 3 | 34 | CH340C programming/debug only |

GPIO13/module pad 16 and GPIO5/module pad 29 are unconnected. They must not be
used as aliases for the status LED or ACK drive.

Q1 and Q2 are 2N7002 open-drain stages with pin 1 = gate, pin 2 = source/GND,
and pin 3 = drain. Firmware drives the gates high to pull the corresponding
PlayStation line low and drives them low to release the line.

## BOOT/RESET behavior

Manual switches are supported and are the accepted programming fallback:

- SW1 pulls `ESP_EN` low for reset.
- SW2 pulls `ESP_BOOT`/GPIO0 low for bootloader entry.

The existing DTR/RTS-assisted topology is retained without redesign:

- DTR passes through R39 to Q4 base; Q4 emitter is RTS and collector is
  `ESP_EN`.
- RTS passes through R40 to Q5 base; Q5 emitter is DTR and collector is
  `ESP_BOOT`/GPIO0.
- Q4 and Q5 are MMBT3904 devices with pin 1 = base, pin 2 = emitter, and
  pin 3 = collector.

Do not claim automatic programming qualification until it is verified on an
assembled board. Manual BOOT/RESET remains the approved bring-up method.

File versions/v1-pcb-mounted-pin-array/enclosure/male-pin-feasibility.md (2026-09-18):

# PS1 bare male PCB-pin feasibility — NOT FOR ORDER

## Confirmed concept

PlayBridge uses eight bare conductive male contacts in a nine-position pattern, mounted directly to the PCB and projecting horizontally toward the PS1 console's female controller port. Position 8 is intentionally empty. There is no donor plug, cable, internal wiring, or female socket array.

Measured geometry:

- centers: `0, 4, 8, 12, 16, 20, 24, 28, 32 mm`;
- uniform 4.00 mm pitch;
- 32.00 mm first-to-last span;
- approximately 1.00 mm console openings;
- provisional mating section: 0.64 × 0.64 mm square, gold plated;
- projection beyond the PCB-edge datum: 16.00 mm total; inner 8.00 mm capture/support section and outer 8.00 mm console insertion section.

The plastic 3+3+3 divisions are mechanical keying features only. They do not change electrical pitch. A future printed shell must reproduce those divisions, align the pins, establish insertion depth, prevent rotation, and carry insertion/removal loads.

## Data required before selecting a production pin

1. Purchasable manufacturer and exact MPN.
2. Mating-section tolerance around the provisional 0.64 × 0.64 mm profile.
3. Gold plating thickness and underplate on the mating section.
4. Pin material, current rating and mating-cycle suitability.
5. Total pin length, 16.00 mm PCB-edge projection, 8.00 mm capture datum, 8.00 mm insertion datum, PCB thickness allowance and rear retention length.
6. Tail/retention style: straight PTH stake, compliant section, swage feature or carrier strip.
7. Manufacturer-recommended finished-hole diameter and tolerance.
8. Pad diameter, annular ring and solder-mask opening.
9. Hand, selective-solder, press-fit or fixture-assisted assembly process.
10. Coplanarity/perpendicularity tolerance and assembly fixture requirements.
11. Console insertion/extraction force and printed-shell load path.

## Provisional footprint

`PROVISIONAL_PS1_MALE_PIN_ARRAY_P4.00_SQ0.64_MECH_TBD` currently uses provisional 1.00 mm finished drills and 1.70 mm pads. Before release, position 8 must be removed from the populated footprint/model. These dimensions are not released until an actual contact manufacturer specifies its tail and hole. Position 1 remains the orientation datum. Looking directly at the male mating face, positions are `1 2 3 | 4 5 6 | 7 8 9`; position 8 is empty. PCB top view is mirrored.

## Release gate

Build a connector-only coupon before ordering a populated PlayBridge board. The coupon must verify fit without console damage, contact continuity and isolation, the 16.00 mm projection with separate 8.00 mm capture and 8.00 mm insertion sections, pin retention, alignment, repeated cycles and shell load transfer. Do not substitute 2.54 mm pitch or change the measured 4.00 mm pitch.

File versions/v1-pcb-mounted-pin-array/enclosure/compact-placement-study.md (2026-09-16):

# PlayBridge compact placement study

## Reference mesh measurements

Measurements were extracted directly from every triangle vertex in the binary STL meshes under `enclosure/reference/`. Coordinate extrema establish the external envelope; repeated planar vertex coordinates establish the opposing inner wall faces.

| Mesh | External bounds (mm) | Size (mm) | Dominant inner wall faces (mm) | Wall-to-wall cavity (mm) |
| --- | --- | --- | --- | --- |
| BlueRetro2_PS1_bottom_Ali.stl | X -26.000…16.000; Y -64.000…-22.000; Z 0…6.497 | 42.000 × 42.000 × 6.497 | X -24.504…14.506; Y -60.497…-24.603 | 39.010 × 35.894 |
| BlueRetro2_PS1_top_Ali.stl | X -26.000…16.000; Y -60.000…-18.000; Z 0…6.098 | 42.000 × 42.000 × 6.098 | X -24.505…14.505; Y -56.497…-20.606 | 39.010 × 35.891 |

The nominal common wall-to-wall cavity is therefore about **39.01 × 35.89 mm**, not 42 × 42 mm. A rectangular PCB must be smaller still. With a provisional 0.25 mm assembly gap per side, the pre-intrusion ceiling is **38.51 × 35.39 mm**. This is not yet an approved PCB outline: corner posts, shell-registration features, the PS1 plug shoulder capture, button actuators, and the USB-C opening intrude into this rectangle and require either measured corner cutouts or local PCB keepouts. Their irregular mesh surfaces were not reduced to invented rectangular dimensions.

## MVP size-reduction options

| Block/item | MVP status | Current implementation | Compact action | Count reduction | Estimated PCB-area benefit |
| --- | --- | --- | --- | ---: | ---: |
| ESP32 Wi-Fi | Mandatory | ESP32-WROOM-32 | Retain for firmware compatibility; place antenna at cavity edge | 0 | 0 mm²; fixes antenna zone |
| PS1 interface | Mandatory | Provisional nine-position bare male-pin array plus CMD/CLK/ATT conditioning and DATA/ACK MOSFETs | Reserve pin/shell keepout; finalize drill and retention only after coupon-tested pin selection, then move small conditioning parts to B.Cu | 0 | 35–55 mm² top-side recovery |
| PS1 power | Mandatory | AP63203, inductor, fuse, TVS, input/output capacitors | Retain topology; verify smaller TVS/fuse/cap packages and compact shielded inductor | 0 | 20–35 mm² |
| USB-C | Mandatory | Amphenol receptacle, CC resistors, USBLC6 | Retain; direct fine-pitch escape and B.Cu passives | 0 | 10–20 mm² top-side recovery |
| USB-UART | Mandatory for current firmware workflow | CH340C SOIC-16 | Use verified CH340C QFN-16 variant or compact equivalent after pin/driver audit | 0 | 35–45 mm² |
| Source isolation | Mandatory while USB bench power remains | TPS2113A TSSOP-8 plus AP2112K | Retain unless a separately reviewed compact protected power path replaces it | 0 | 0–10 mm² |
| BOOT/RESET | Mandatory access | Two CK side switches | Replace with verified miniature side-actuated switches; keep both functions | 0 | 20–30 mm² |
| UART/rail test points | Non-MVP | TP1–TP4, 1.5 mm pads | Remove TP1/TP2; replace TX/RX with small labeled pogo pads | 2 footprints | 18–25 mm² |
| Status LED | Optional | LED plus resistor | Remove for minimum build, or retain only if enclosure indication is required | 2 footprints | 4–7 mm² |
| Auto-programming | Useful but reducible | Two transistors and two base resistors | Retain for normal flashing; aggressive option uses compact dual transistor/array after verification | 1–2 footprints | 8–15 mm² |
| Large passives | Mandatory electrically | 1206/0805 supply capacitors and fuse | Use verified voltage/current-rated 0805/0603 alternatives only where derating permits | 0 | 10–20 mm² |

Conservative reduction: remove two rail test points, convert UART points to pogo pads, use compact side switches, compact CH340C package, and move low-profile passives to B.Cu. Estimated reduction is **4–6 footprints and 100–160 mm² of top-side demand**.

Aggressive alternative: ESP32-S3 with native USB can remove CH340C and much of the auto-program block, but it changes the MCU, USB firmware, boot behavior, GPIO allocation, and PS1 timing validation. It is a separate product/firmware-port option and is not applied here.

## Placement decision

No replacement PCB placement was created. The existing 60-footprint design already failed at 42 × 42 mm with 40 courtyard overlaps; the measured cavity ceiling is only 38.51 × 35.39 mm before posts and connector intrusions. A legal placement requires the component/package reductions above and a PCB outline derived around the actual corner/post and plug-capture geometry. Compressing the existing parts again would not be an engineering result.

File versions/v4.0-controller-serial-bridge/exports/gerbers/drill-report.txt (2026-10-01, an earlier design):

Drill report for board.kicad_pcb
Created on 2026-09-29T16:03:13

Copper Layer Stackup:
    =============================================================
    L1 :  F.Cu                      front
    L2 :  B.Cu                      back

Drill file 'board-PTH.drl' contains
    plated through holes:
    =============================================================
    T1  0.300mm  0.0118"  (185 holes))
    T2  0.300mm  0.0118"  (12 holes))
    T3  0.350mm  0.0138"  (3 holes))
    T4  0.400mm  0.0157"  (4 holes))
    T5  0.600mm  0.0236"  (8 holes)  (with 8 slots)
    T6  0.700mm  0.0276"  (18 holes))
    T7  1.000mm  0.0394"  (3 holes))

    Total plated holes count 233

Drill file 'board-NPTH.drl' contains
    unplated through holes:
    =============================================================
    T1  0.650mm  0.0256"  (2 holes))

    Total unplated holes count 2

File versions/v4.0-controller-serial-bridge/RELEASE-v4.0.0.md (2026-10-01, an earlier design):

# PlayBridge V4.0.0 digital design checkpoint

Date: 2026-09-29

V4.0.0 records the digitally verified two-layer controller/serial bridge and
its manufacturing outputs for bench testing. The canonical board is 68 × 60 mm
and provides a PS1 controller harness on J1, PS1 UART2 serial harness on J2,
USB-C programming/power, protected PS1 power, and TPS2116 source multiplexing.

The digital verification gate passes: ERC, DRC, schematic/PCB parity, connectivity,
BOM/CPL consistency, 3D model coverage for fitted parts, fabrication archive
integrity, and the SHA-256 manifest all pass. Procurement metadata includes
the final LCSC substitutions and consolidates all nine 1 kΩ 0603 resistors on
C21190.

This is not a production qualification. Production remains on hold until the
physical measurements in `reports/bench-test.md` pass and are recorded.
The Magnetsyc CPN4020H4R7MT inductor is accepted for the expected sub-2 A load
but must not be claimed for sustained 2.0 A operation without thermal testing.

Order files are under `exports/` and convenient copies are under `ordering/`.

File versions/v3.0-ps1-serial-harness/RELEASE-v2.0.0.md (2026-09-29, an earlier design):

# PlayBridge hardware v2.0.0 release candidate

## Scope

V2 replaces the provisional PCB-mounted PS1 contact array with a modular
donor-plug harness. J1 carries the native PS1 controller interface through a
keyed 9-contact connector. J2 reserves the same mechanical interface for a
future rear-serial harness and is intentionally all-NC. USB-C J3 remains the
programming and user power connection.

J1 and J2 use USB 3 Type-A connector hardware but do not carry USB. Both ports
must be marked **NOT USB** in the enclosure and harness.

## Validated board

- Dimensions: 56.295 × 62.000 mm.
- Stackup: four copper layers, 1.20 mm finished thickness.
- Population: 67 footprints; 63 fitted references and four DNP test pads.
- J1/J2: Hong Cheng HC-USB3.0-L168-ZP / JLCPCB C7501856, outward at the lower edge; nine signal-pad coordinates preserved from the validated routing.
- J3: HRO TYPE-C-31-M-12 / JLCPCB C165948, outward at the right edge.
- Board SHA-256: `4e4068be3e2941f74bfe923bd5959de7a7d2209ca3e7ce8036483f3a8c5df5ab`.

## Release gate

- KiCad DRC: 0 errors, 0 warnings, 0 unconnected items.
- KiCad ERC: 0 errors, 0 warnings.
- Schematic-to-PCB parity: 0 findings.
- FabDesk release gate: PASS with no warning baselines.
- Connectivity: 135/135 connections routed.

## 3D inspection coverage

- Exact/authoritative component models: J1, J2, J3, U1, SW1, SW2, and D2.
- L1: dimensionally controlled datasheet-derived 4 × 4 × 3 mm model because
  exact vendor CAD was unavailable.
- Remaining fitted packages use their KiCad/project models or dimensionally
  representative package envelopes in the populated audit renders.
- Missing footprint representations: 0.

Accepted technical renders are in [`renders/`](renders/). They are render-only
artifacts and do not modify PCB geometry, placement, routing, footprints, or nets.

## Manufacturing package

The repository includes:

- `ordering/gerbers-jlcpcb.zip`
- `ordering/jlcpcb-bom.csv`
- `ordering/jlcpcb-cpl.csv`
- `ordering/PCBA-SOURCING-AUDIT.md`

## Checkout hold

Before placing the PCBA order, recheck live stock for J1/J2 C7501856 and L1
Sunlord WPN4020H4R7MT / C98363, then inspect the JLCPCB BOM/CPL placement preview—especially both
USB-A connectors, USB-C, switches, D2, and L1. This is a commercial/assembly
review hold; no electrical-layout or connector-orientation defect is open.

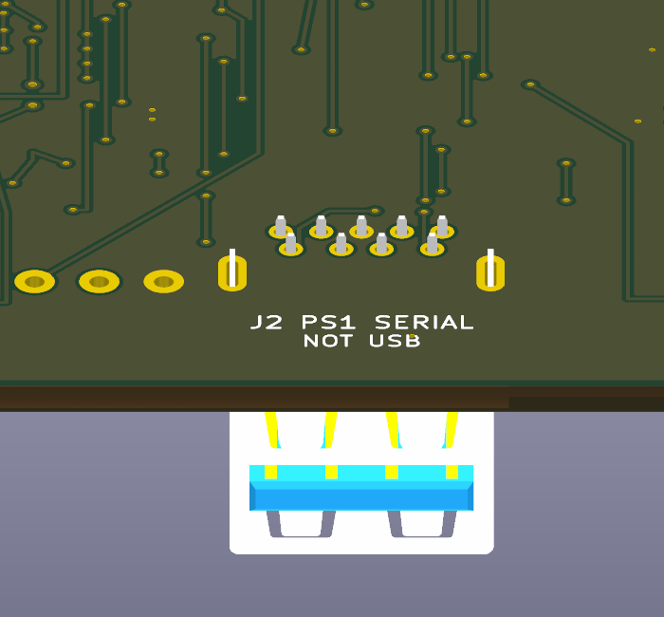
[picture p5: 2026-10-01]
versions/v4.1-controller-serial-bridge/renders/j2-mechanical-underside.png

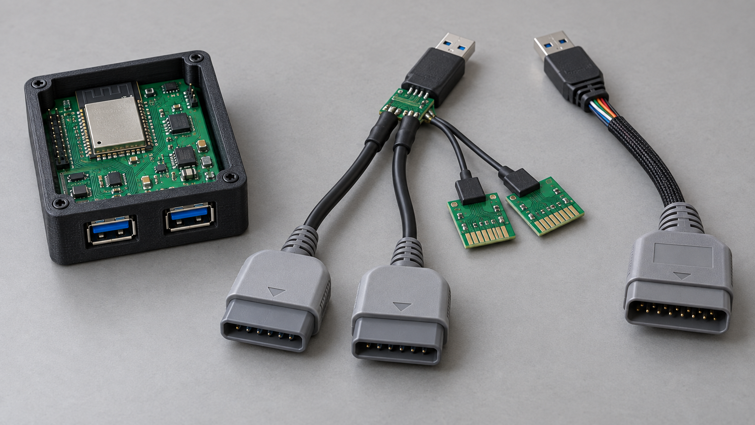
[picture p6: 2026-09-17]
docs/images/concepts/playbridge-modular-harness-concept.png

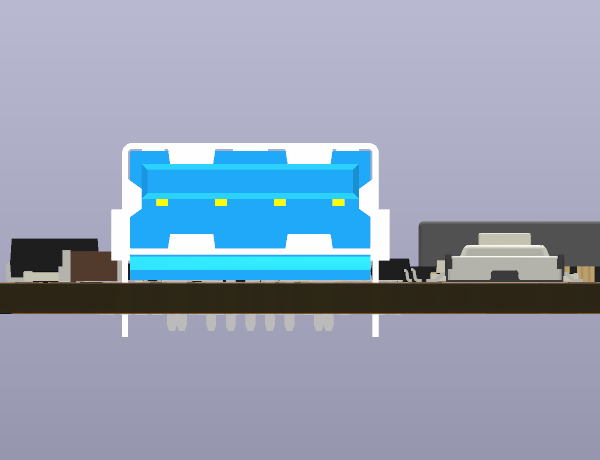
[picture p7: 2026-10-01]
versions/v4.1-controller-serial-bridge/renders/j2-mechanical-side.png

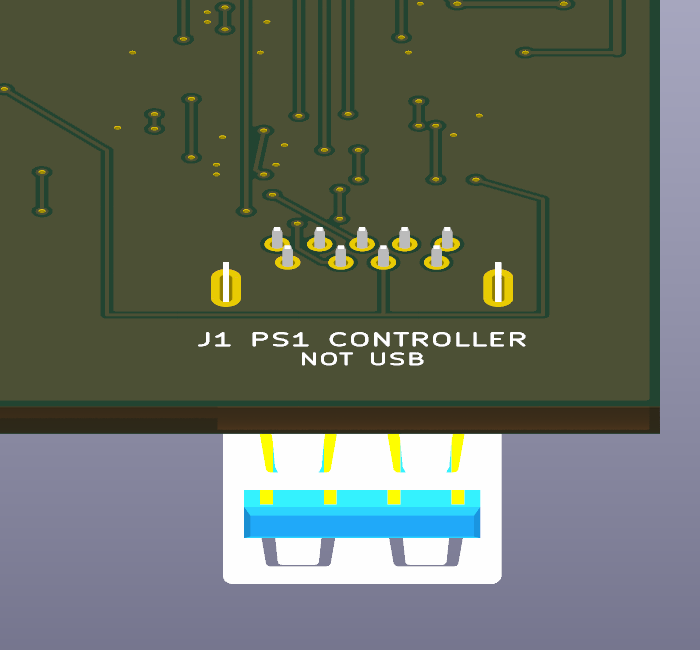
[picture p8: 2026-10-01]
versions/v4.1-controller-serial-bridge/renders/j1-mechanical-underside.png

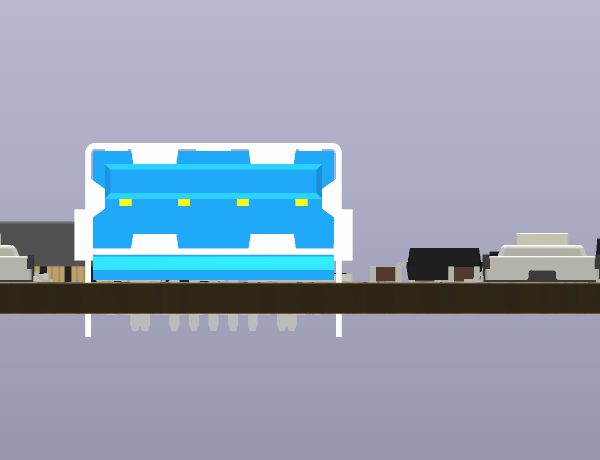
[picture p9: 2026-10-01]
versions/v4.1-controller-serial-bridge/renders/j1-mechanical-side.png

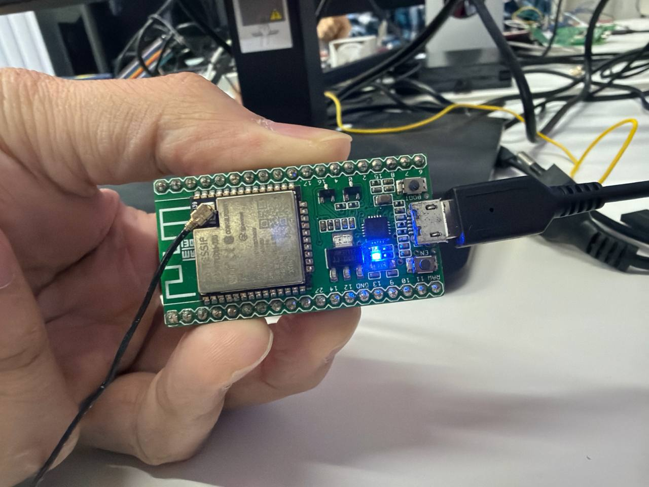
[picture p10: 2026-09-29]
versions/v3.0-ps1-serial-harness/reports/evidence/poc-esp32-powered.png

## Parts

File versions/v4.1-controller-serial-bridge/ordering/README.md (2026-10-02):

# V4.1 ordering package

The current plan is to order bare PCBs and assemble them in-house on the
LumenPnP.

- Upload `NewPlayBridge2-v4.1-ANTS-Gerbers.zip` when replying to ANTS PCB.
  It is a vendor-named copy of the verified 13-file fabrication archive.
- `gerbers-jlcpcb.zip` remains the generic bare-board-order copy of the same
  fabrication data.
- Confirm the drill preview shows 190 routed vias with 0.40 mm drills and
  0.90 mm copper diameters before purchase.
- `assembly-bom.csv` and `assembly-cpl.csv` contain the 77 fitted references
  for in-house assembly preparation.
- `lcsc-shopping-list.csv` is the canonical one-board grouped parts list.
  Distributor MOQ quantities may be larger than the design quantity.
- `order-metadata.json` records board and output metadata.

The complete canonical outputs remain under `../exports/`. Confirm board
preview, dimensions, layer count, drill files, and quantity before purchase.
Do not release assembled hardware to production until `../reports/bench-test.md`
has recorded passing results.

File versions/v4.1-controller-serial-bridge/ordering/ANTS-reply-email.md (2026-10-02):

# Reply to ANTS PCB

Subject: ส่งไฟล์แก้ไข NewPlayBridge2 V4.1 สำหรับตรวจสอบอีกครั้ง

เรียน ทีมงาน ANTS PCB

ขอบคุณสำหรับคำแนะนำครับ/ค่ะ ได้แก้ไขไฟล์ NewPlayBridge2 เป็นเวอร์ชัน V4.1 แล้ว โดยปรับ VIA ที่ใช้เดินลายทั้งหมดดังนี้

- Hole size ของ VIA: 0.40 mm (16 mil)
- Diameter / PAD ของ VIA: 0.90 mm (36 mil)
- Annular ring: 0.25 mm ต่อด้าน
- จำนวน routed VIA: 190 จุด

ได้ตรวจสอบไฟล์ใหม่แล้ว ไม่พบ DRC error หรือ unconnected item และไฟล์ drill report แสดง VIA ขนาด 0.40 mm จำนวน 190 จุด

แนบไฟล์ `NewPlayBridge2-v4.1-ANTS-Gerbers.zip` เพื่อขอให้ตรวจสอบและใช้แทนไฟล์เดิมครับ/ค่ะ

ก่อนเริ่มผลิต รบกวนช่วยยืนยันเพิ่มเติมว่าสเปกโรงงานรองรับ copper spacing ขั้นต่ำ 0.08 mm และ track width ขั้นต่ำ 0.15 mm สำหรับไฟล์นี้ หากไม่รองรับ กรุณาแจ้งค่าขั้นต่ำที่ต้องการเพื่อให้แก้ไขไฟล์อีกครั้ง

ขอบคุณครับ/ค่ะ

---

English reference:

Thank you for the fabrication feedback. The NewPlayBridge2 design has been updated to V4.1. All routed vias now use a 0.40 mm (16 mil) finished drill and a 0.90 mm (36 mil) copper diameter, giving a 0.25 mm annular ring per side. The regenerated drill report contains 190 routed 0.40 mm via holes, and the updated board passes DRC with no unconnected items.

Please inspect and use the attached `NewPlayBridge2-v4.1-ANTS-Gerbers.zip` instead of the previous file. Before production, please also confirm that your process supports the design's 0.08 mm minimum copper spacing and 0.15 mm minimum track width. If not, please advise the required minimums so the files can be revised.

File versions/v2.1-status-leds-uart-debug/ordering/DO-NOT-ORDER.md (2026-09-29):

# DO NOT ORDER — sourcing and PCBA completeness review

**V2.1 REVIEW HOLD:** all manufacturing, assembly, validation, and render files
have been regenerated from the final V2.1 board. Do not place an order until a
human approves the mechanical renders, BOM/CPL rotation preview, substitutions,
and live stock.

The connector-orientation and routing hold is resolved. J1 and J2 are installed at their approved
lower-edge placements with both mating mouths facing outward, and the authoritative board passes ERC,
DRC, connectivity, and schematic-parity checks with zero findings.

Keep this ordering hold only until the following commercial checks are completed at checkout:

- Reconfirm live JLCPCB/LCSC availability for Molex 48393-0003 / C3197928. Two are required per board;
  the last public check showed only seven units.
- Reconfirm availability of the low-stock 4.7 uH inductor L1, MYX MCNR4030AF-4R7M / C49449313.
- Review the uploaded BOM and CPL for 65 fitted references and four DNP bare-board test pads
  (TP1–TP4), including rotation previews and any assembler substitutions.
- Confirm the assembler accepts every project-local/custom footprint and the explicitly reserved,
  all-NC J2 population.

This is a sourcing/assembly-completeness hold, not a connector-orientation or electrical-layout hold.

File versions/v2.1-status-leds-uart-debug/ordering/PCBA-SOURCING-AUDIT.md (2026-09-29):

# JLCPCB PCBA sourcing audit — 2026-09-25

## Result

- Fitted references: 65
- Unique orderable line items: 34
- DNP/bare-board test pads: TP1, TP2, TP3, TP4
- Missing fitted references: none
- Duplicate reference assignments: none
- Board routing/placement changed by this sourcing pass: no

## Footprint-sensitive selections

- D2: GOODWORK SMAJ12A / C908766, DO-214AC (SMA). The earlier value label said SMBJ12A, but the PCB uses an SMA land pattern; the selected SMAJ12A preserves the 12 V unidirectional TVS function and fits the footprint family.
- F1: BHFUSE BSMD1206-075-30V / C976305, 1206, 750 mA hold, 1.5 A trip, 30 V.
- L1: MYX MCNR4030AF-4R7M / C49449313, 4.0 x 4.0 mm, 4.7 uH, 2.5 A rated, 3 A saturation. JLC stock was low (40 units when checked), so recheck immediately before ordering.
- R20: TA-I RMS06FT6980 / C912219, 698 ohm E96 substitute for the 700 ohm nominal. The TPS2113A current-limit setpoint difference is approximately +0.29%.
- J1/J2: Molex 48393-0003 / C3197928. JLC showed only 7 available units when checked; with two populated per board, the public stock supports at most 3 complete boards. J2 is electrically reserved/all-NC, but remains populated in this BOM because the current board/render includes it.
- D6: KENTO KT-0603R / C2286, red 0603 always-on 3V3 POWER indicator.
- R29: UNI-ROYAL 0603WAF1001T5E / C21190, 1 kΩ 0603 POWER-LED series resistor.

## Order files

- `jlcpcb-bom.csv`: grouped JLC/LCSC BOM; all fitted references assigned exactly once.
- `jlcpcb-cpl.csv`: top-side placement list derived from FabDesk's existing `exports/positions.csv`, excluding bare-board test pads.
- `gerbers-jlcpcb.zip`: flat manufacturing Gerber/drill archive copied from FabDesk's verified export set.

## Fresh release verification

- KiCad DRC: 0 errors, with only the three approved historical track_dangling warnings
- Unconnected items: 0
- Schematic-to-PCB parity issues: 0
- KiCad ERC: 0 violations
- Board and schematic hashes remained unchanged during the BOM/order-file pass.

Stock is time-sensitive; JLCPCB/LCSC availability must be rechecked by the order portal at upload time.

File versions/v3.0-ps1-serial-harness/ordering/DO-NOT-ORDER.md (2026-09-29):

# V3.0 ORDER REVIEW COMPLETE — not yet purchased

Date: 2026-09-25

The V3.0 J2 serial implementation is complete. On 2026-09-25 the user confirmed
that the teammate firmware/protocol and electrical PoC passed on the tested
hardware; the two supplied setup photographs are preserved under
`reports/evidence/`. KiCad verification also passes with zero unconnected pads,
zero ERC findings, zero schematic-parity findings, and only the three inherited
locally approved UART0 test-stub warnings.

Fresh V3.0 manufacturing and assembly files have now been generated from the
verified V3.0 board. The package includes J2, R30 and R31. On 2026-09-25 the
files were uploaded to a live JLCPCB Standard PCBA quote for five boards; all
34 BOM rows were confirmed and the placement preview was reviewed. The quote
reached $157.05 before shipping and tax. Save to Cart was not clicked and no
order was placed.

The live quote required one catalog substitution:

- R1, R3, R5, R13, R16, R29, R30 and R31 changed from unavailable UNI-ROYAL
  0603WAF1001T5E / C21190 to Yageo RC0603FR-071KL / C22548. Both are 0603,
  1 kOhm, +/-1%, 100 mW, 75 V resistors; land pattern, routing and placement
  are unchanged.
- J1/J2 were reselected as the exact original C7501856, and SW1/SW2 were
  reselected as the exact original C2837195. JLCPCB's initial zero-quantity
  matches were stale; these were not substitutions.

Current package hashes:

- `gerbers-jlcpcb.zip` SHA-256:
  `a88b31894732a681873b0c5fa4dddc82e82b0fdcf7c66dfae1b98b0ab3e725d8`
- `jlcpcb-bom.csv` SHA-256:
  `dc14498df3f4fc5ce8dd69c2211daf1fb5ab602a2a89adb5fe740414ea47b6fa`
- `jlcpcb-cpl.csv` SHA-256:
  `686bd018bfcfe1f596070ecc0887670ec0c4ec81c907151657b2d36fe336b2dd`
- Generic `exports/fabrication.zip` SHA-256:
  `92a6d5d03cca62bb854a6787f041eaa93b8f6ecc017e9756aa2eaffc077d354a`

The previous external assembler checkout hold is complete for the reviewed
2026-09-25 quote. Before a future purchase, recheck time-sensitive stock and
pricing, confirm the same catalog selections remain active, and perform JLCPCB's
final production-file/placement confirmation. No firmware, protocol, J2-routing,
DRC/ERC, sourcing, or file-generation blocker remains for the tested hardware
configuration.

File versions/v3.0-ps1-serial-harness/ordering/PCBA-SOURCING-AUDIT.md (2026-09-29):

# JLCPCB PCBA sourcing audit — 2026-09-25

## Result

- Fitted references: 67
- Unique orderable line items: 34
- DNP/bare-board test pads: TP1, TP2, TP3, TP4
- Missing fitted references: none
- Duplicate reference assignments: none
- Board routing/placement changed by this sourcing pass: no

## Footprint-sensitive selections

- D2: GOODWORK SMAJ12A / C908766, DO-214AC (SMA). The earlier value label said SMBJ12A, but the PCB uses an SMA land pattern; the selected SMAJ12A preserves the 12 V unidirectional TVS function and fits the footprint family.
- F1: BHFUSE BSMD1206-075-30V / C976305, 1206, 750 mA hold, 1.5 A trip, 30 V.
- L1: Sunlord WPN4020H4R7MT / C98363, 4.0 x 4.0 x 2.0 mm, 4.7 uH +/-20%, 2.85 A rated, 4.9 A saturation, 108 mOhm. The official 1.9 mm pad gap and 1.1 x 3.7 mm lands exactly match the inherited routed footprint.
- R20: UNI-ROYAL 0603WAF6800T5E / C23228, 680 ohm +/-1%. Relative to the previous 698 ohm selection, the calculated TPS2113A current limit increases by approximately 2.65%; verify intended current-limit acceptability.
- C3: Samsung CL21A106KOQNNNE / C1713, 10 uF 16 V X5R +/-10%, 0805.
- C9: Samsung CL21A226MQQNNNE / C5674, 22 uF 6.3 V X5R +/-20%, 0805.
- D1: KENTO KT-0603YG / C2289, yellow-green 0603 STATUS LED; polarity and STATUS_LED wiring are unchanged.
- J1/J2: Hong Cheng HC-USB3.0-L168-ZP / C7501856. JLCPCB listed this as a ready-for-assembly in-stock part during the 2026-09-25 replacement pass; recheck live stock at checkout. Its nine electrical-pad coordinates exactly match the replaced connector, so routing is unchanged. J2 carries the user/team bench-validated three-signal PS1 serial harness on contacts 1 (PS1_RXD), 4 (PS1_TXD) and 7 (GND); all other signal contacts remain NC.
- D6: KENTO KT-0603R / C2286, red 0603 always-on 3V3 POWER indicator.
- R1/R3/R5/R13/R16/R29/R30/R31: Yageo RC0603FR-071KL / C22548, 1 kΩ +/-1%, 100 mW, 75 V, 0603. This is the quote-time replacement for out-of-stock UNI-ROYAL 0603WAF1001T5E / C21190. Electrical value, tolerance, power rating, voltage rating, and land pattern are unchanged; routing and placement are unchanged.

## Live JLCPCB quote review — 2026-09-25

- JLCPCB initially displayed zero available quantity for C7501856 and C2837195. Searching public PCBA inventory and reselecting the exact same catalog entries resolved the stale matches: J1/J2 remain C7501856 and SW1/SW2 remain C2837195. These were not substitutions.
- C21190 was genuinely unavailable in the live PCBA quote. All eight 1 kΩ 0603 positions were replaced in the quote with C22548 as documented above.
- All 34 uploaded BOM rows were confirmed. The portal grouped duplicate catalog selections into 31 charged component items.
- Placement preview was reviewed before pricing: J1/J2 mouths face the lower board edge, J3 remains on the right edge, and no obvious 180-degree placement error was visible.
- Five-board quote: PCB $13.10; Standard PCBA $143.95; total $157.05 before shipping and tax. No order was placed and Save to Cart was not clicked.

## Order files

- `jlcpcb-bom.csv`: grouped JLC/LCSC BOM; all fitted references assigned exactly once.
- `jlcpcb-cpl.csv`: top-side placement list derived from FabDesk's existing `exports/positions.csv`, excluding bare-board test pads.
- `gerbers-jlcpcb.zip`: flat manufacturing Gerber/drill archive copied from FabDesk's verified export set.

## Fresh release verification

- KiCad DRC: 0 errors, with only the three approved historical track_dangling warnings
- Unconnected items: 0
- Schematic-to-PCB parity issues: 0
- KiCad ERC: 0 violations
- Board and schematic hashes remained unchanged during the BOM/order-file pass.

Stock is time-sensitive; JLCPCB/LCSC availability must be rechecked by the order portal at upload time.

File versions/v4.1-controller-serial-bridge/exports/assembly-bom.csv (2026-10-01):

Designator | Comment | Footprint | Manufacturer | MPN | LCSC | ProcurementNote | Quantity | DNP
C1 | 10uF 10V USB IN | Capacitor_SMD:C_0805_2012Metric |  | CL21A106KOQNNNE | C1713 |  | 1
C2 | 100nF USB IN | Capacitor_SMD:C_0603_1608Metric |  | CC0603KRX7R9BB104 | C14663 |  | 1
C3 | 1uF AP2112 IN | Capacitor_SMD:C_0603_1608Metric |  | CL10A105KA8NNNC | C5673 |  | 1
C4 | 10uF AP2112 OUT | Capacitor_SMD:C_0805_2012Metric |  | CL21A106KOQNNNE | C1713 |  | 1
C5 | 100nF CH340 VCC | Capacitor_SMD:C_0603_1608Metric |  | CC0603KRX7R9BB104 | C14663 |  | 1
C6 | 100nF CH340 V3 | Capacitor_SMD:C_0603_1608Metric |  | CC0603KRX7R9BB104 | C14663 |  | 1
C7 | 22uF ESP BULK | Capacitor_SMD:C_0805_2012Metric |  | CL21A226MQQNNNE | C5674 |  | 1
C8 | 100nF ESP BYPASS | Capacitor_SMD:C_0603_1608Metric |  | CC0603KRX7R9BB104 | C14663 |  | 1
C9 | 1uF EN RESET | Capacitor_SMD:C_0603_1608Metric |  | CL10A105KA8NNNC | C5673 |  | 1
C10 | 22uF 25V AP63203 IN | Capacitor_SMD:C_1206_3216Metric |  | CL31A226KAHNNNE | C12891 |  | 1
C11 | 100nF 50V AP63203 IN | Capacitor_SMD:C_0603_1608Metric |  | CC0603KRX7R9BB104 | C14663 |  | 1
C12 | 100nF 50V BOOTSTRAP | Capacitor_SMD:C_0603_1608Metric |  | CC0603KRX7R9BB104 | C14663 |  | 1
C13 | 22uF 25V AP63203 OUT | Capacitor_SMD:C_1206_3216Metric |  | CL31A226KAHNNNE | C12891 |  | 1
C14 | 22uF 25V AP63203 OUT | Capacitor_SMD:C_1206_3216Metric |  | CL31A226KAHNNNE | C12891 |  | 1
C15 | 10uF MUX OUT | Capacitor_SMD:C_0805_2012Metric |  | CL21A106KOQNNNE | C1713 |  | 1
C16 | 100nF MUX OUT | Capacitor_SMD:C_0603_1608Metric |  | CC0603KRX7R9BB104 | C14663 |  | 1
C17 | 1uF MUX VIN1 | Capacitor_SMD:C_0603_1608Metric |  | CL10A105KA8NNNC | C5673 |  | 1
C18 | 1uF MUX VIN2 | Capacitor_SMD:C_0603_1608Metric |  | CL10A105KA8NNNC | C5673 |  | 1
D1 | SMAJ5.0A USB TVS | Diode_SMD:D_SMA | LRC | SMAJ5.0A | C140902 |  | 1
D2 | SMAJ12A PS1 TVS | Diode_SMD:D_SMA | GOODWORK | SMAJ12A | C908766 |  | 1
D3 | PESD3V3U1UA ACK ESD | Diode_SMD:D_SOD-323 | Nexperia | PESD3V3U1UA,115 | C403915 |  | 1
D4 | TPD2EUSB30A USB ESD | Package_TO_SOT_SMD:Texas_DRT-3 | TECH PUBLIC | TPD2EUSB30ADRTR-TP | C2987043 |  | 1
D5 | TPD2EUSB30A HARNESS ESD | Package_TO_SOT_SMD:Texas_DRT-3 | TECH PUBLIC | TPD2EUSB30ADRTR-TP | C2987043 |  | 1
D6 | TPD2EUSB30A HARNESS ESD | Package_TO_SOT_SMD:Texas_DRT-3 | TECH PUBLIC | TPD2EUSB30ADRTR-TP | C2987043 |  | 1
D7 | TPD2EUSB30A HARNESS ESD | Package_TO_SOT_SMD:Texas_DRT-3 | TECH PUBLIC | TPD2EUSB30ADRTR-TP | C2987043 |  | 1
D8 | GREEN POWER | LED_SMD:LED_0603_1608Metric |  | 19-217/GHC-YR1S2/3T | C2286 |  | 1
D9 | BLUE STATUS | LED_SMD:LED_0603_1608Metric |  | 19-217/BHC-ZL1M2RY/3T | C2293 |  | 1
F1 | 750mA USB PTC | Fuse:Fuse_1206_3216Metric | BHFUSE | BSMD1206-075-30V | C976305 |  | 1
F2 | 0.75A PS1 PTC | Fuse:Fuse_1206_3216Metric | BHFUSE | BSMD1206-075-30V | C976305 |  | 1
J1 | J1 PS1 CONTROLLER - NOT USB | Connector_USB:HC-USB3.0-L168-ZP | Hong Cheng | HC-USB3.0-L168-ZP | C7501856 |  | 1
J2 | J2 PS1 SERIAL - NOT USB | Connector_USB:HC-USB3.0-L168-ZP | Hong Cheng | HC-USB3.0-L168-ZP | C7501856 |  | 1
J3 | J3 USB-C POWER / PROGRAM / PC | Connector_USB:USB_C_Receptacle_HRO_TYPE-C-31-M-12_S1 | Korean Hroparts | TYPE-C-31-M-12 | C165948 |  | 1
J5 | AP63203WU-7 | Package_TO_SOT_SMD:TSOT-23-6 | Diodes Incorporated | AP63203WU-7 | C780769 |  | 1
L1 | 4.7uH +/-20%, 2.5A rated, 4.7A Isat | Inductor_SMD:L_Sunlord_SWPA4020S | Magnetsyc | CPN4020H4R7MT | C52741363 | 4.7uH +/-20%; 2.5A rated; 4.7A Isat; SMD 4x4mm | 1
Q1 | 2N7002 DATA OPEN-DRAIN | Package_TO_SOT_SMD:SOT-23 | Jiangsu Changjing Electronics | 2N7002 | C8545 |  | 1
Q2 | 2N7002 ACK OPEN-DRAIN | Package_TO_SOT_SMD:SOT-23 | Jiangsu Changjing Electronics | 2N7002 | C8545 |  | 1
Q4 | MMBT3904 AUTO RESET | Package_TO_SOT_SMD:SOT-23 | onsemi | MMBT3904LT1G | C81464 |  | 1
Q5 | MMBT3904 AUTO BOOT | Package_TO_SOT_SMD:SOT-23 | onsemi | MMBT3904LT1G | C81464 |  | 1
R1 | 5.1k CC1 | Resistor_SMD:R_0402_1005Metric |  | 0402WGF5101TCE | C25905 |  | 1
R2 | 5.1k CC2 | Resistor_SMD:R_0402_1005Metric |  | 0402WGF5101TCE | C25905 |  | 1
R3 | 10k EN PU | Resistor_SMD:R_0603_1608Metric |  | 0603WAF1002T5E | C25804 |  | 1
R4 | 10k BOOT PU | Resistor_SMD:R_0603_1608Metric |  | 0603WAF1002T5E | C25804 |  | 1
R5 | 1k UART RX SERIES | Resistor_SMD:R_0603_1608Metric |  | 0603WAF1001T5E | C21190 |  | 1
R6 | 100k UART RX PULLDOWN | Resistor_SMD:R_0603_1608Metric |  | 0603WAF1003T5E | C25803 |  | 1
R7 | 1k PS1 CMD | Resistor_SMD:R_0603_1608Metric |  | 0603WAF1001T5E | C21190 |  | 1
R8 | 100R DATA GATE | Resistor_SMD:R_0603_1608Metric |  | 0603WAF1000T5E | C22775 |  | 1
R9 | 1k PS1 CLK | Resistor_SMD:R_0603_1608Metric |  | 0603WAF1001T5E | C21190 |  | 1
R10 | 1k PS1 ATT | Resistor_SMD:R_0603_1608Metric |  | 0603WAF1001T5E | C21190 |  | 1
R11 | 1k PS1 ACK | Resistor_SMD:R_0603_1608Metric |  | 0603WAF1001T5E | C21190 |  | 1
R12 | 10k PS1 DATA PU | Resistor_SMD:R_0603_1608Metric |  | 0603WAF1002T5E | C25804 |  | 1
R13 | 10k PS1 ACK PU | Resistor_SMD:R_0603_1608Metric |  | 0603WAF1002T5E | C25804 |  | 1
R14 | 1k UART2 TX | Resistor_SMD:R_0603_1608Metric |  | 0603WAF1001T5E | C21190 |  | 1
R15 | 1k UART2 RX | Resistor_SMD:R_0603_1608Metric |  | 0603WAF1001T5E | C21190 |  | 1
R16 | 100k MUX STATUS PU | Resistor_SMD:R_0603_1608Metric |  | 0603WAF1003T5E | C25803 |  | 1
R17 | 0R CH340 3V3 LINK | Resistor_SMD:R_0402_1005Metric |  | 0402WGF0000TCE | C17168 |  | 1
R18 | 10k TPS2116 PR1 TOP | Resistor_SMD:R_0603_1608Metric |  | 0603WAF1002T5E | C25804 |  | 1
R19 | 10k TPS2116 PR1 BOTTOM | Resistor_SMD:R_0603_1608Metric |  | 0603WAF1002T5E | C25804 |  | 1
R21 | 0R GPIO21 ROUTE LINK | Resistor_SMD:R_0402_1005Metric |  | 0402WGF0000TCE | C17168 |  | 1
R22 | 0R GPIO21 ROUTE LINK 2 | Resistor_SMD:R_0402_1005Metric |  | 0402WGF0000TCE | C17168 |  | 1
R23 | 0R UART TX ROUTE LINK | Resistor_SMD:R_0402_1005Metric |  | 0402WGF0000TCE | C17168 |  | 1
R24 | 0R UART TX LINK 2 | Resistor_SMD:R_0402_1005Metric |  | 0402WGF0000TCE | C17168 |  | 1
R25 | 0R UART TX SERVICE LINK | Resistor_SMD:R_0402_1005Metric |  | 0402WGF0000TCE | C17168 |  | 1
R32 | 100k UNUSED INPUT PULLDOWN | Resistor_SMD:R_0603_1608Metric |  | 0603WAF1003T5E | C25803 |  | 1
R35 | 100k UNUSED INPUT PULLDOWN | Resistor_SMD:R_0603_1608Metric |  | 0603WAF1003T5E | C25803 |  | 1
R36 | 100k DATA GATE PULLDOWN | Resistor_SMD:R_0603_1608Metric |  | 0603WAF1003T5E | C25803 |  | 1
R37 | 100R ACK GATE | Resistor_SMD:R_0603_1608Metric |  | 0603WAF1000T5E | C22775 |  | 1
R38 | 100k ACK GATE PULLDOWN | Resistor_SMD:R_0603_1608Metric |  | 0603WAF1003T5E | C25803 |  | 1
R39 | 10k DTR BASE | Resistor_SMD:R_0603_1608Metric |  | 0603WAF1002T5E | C25804 |  | 1
R40 | 10k RTS BASE | Resistor_SMD:R_0603_1608Metric |  | 0603WAF1002T5E | C25804 |  | 1
R41 | 1k POWER LED | Resistor_SMD:R_0603_1608Metric |  | 0603WAF1001T5E | C21190 |  | 1
R42 | 1k STATUS LED | Resistor_SMD:R_0603_1608Metric |  | 0603WAF1001T5E | C21190 |  | 1
SW1 | RESET | Button_Switch_SMD:K2-1107ST-A4SW-06 | Korean Hroparts | K2-1107ST-A4SW-06 | C2837195 |  | 1
SW2 | BOOT | Button_Switch_SMD:K2-1107ST-A4SW-06 | Korean Hroparts | K2-1107ST-A4SW-06 | C2837195 |  | 1
U1 | ESP32-WROOM-32E | RF_Module:ESP32-WROOM-32E-N4-PROD | Espressif Systems | ESP32-WROOM-32E-N4 | C701341 |  | 1
U2 | CH340C | Package_SO:SOIC-16_3.9x9.9mm_P1.27mm | WCH | CH340C | C84681 |  | 1
U4 | AP2112K-3.3 | Package_TO_SOT_SMD:SOT-23-5 | Diodes Incorporated | AP2112K-3.3TRG1 | C51118 |  | 1
U6 | TPS2116DRLR POWER MUX | Package_TO_SOT_SMD:SOT-583-8 | Texas Instruments | TPS2116DRLR | C3235557 |  | 1

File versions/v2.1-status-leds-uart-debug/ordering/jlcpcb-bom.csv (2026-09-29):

Comment | Designator | Footprint | LCSC Part # | Manufacturer | Manufacturer Part Number | Package | Quantity
CL31A226KAHNNNE | C1,C2 | C_1206_3216Metric | C12891 | Samsung Electro-Mechanics | CL31A226KAHNNNE | 1206, 22uF, 25V, X5R, +/-10% | 2
TCC0805X5R106K160FT | C3 | C_0805_2012Metric | C380332 | CCTC | TCC0805X5R106K160FT | 0805, 10uF, 16V, X5R, +/-10% | 1
CL10A105KA8NNNC | C5,C11,C12 | C_0603_1608Metric | C5673 | Samsung Electro-Mechanics | CL10A105KA8NNNC | 0603, 1uF, 25V, X5R, +/-10% | 3
TCC0805X5R475K160FT | C6 | C_0805_2012Metric | C380342 | CCTC | TCC0805X5R475K160FT | 0805, 4.7uF, 16V, X5R, +/-10% | 1
C0805X5R226M6R3NT | C9 | C_0805_2012Metric | C466795 | SANYEAR | C0805X5R226M6R3NT | 0805, 22uF, 6.3V, X5R, +/-20% | 1
CC0603KRX7R9BB104 | C4,C7,C8,C10,C13 | C_0603_1608Metric | C14663 | Yageo | CC0603KRX7R9BB104 | 0603, 100nF, 50V, X7R, +/-10% | 5
19-217/GHC-YR1S2/3T | D1 | LED_0603_1608Metric | C72043 | Everlight Electronics | 19-217/GHC-YR1S2/3T | 0603 green LED | 1
SMAJ12A | D2 | D_SMA | C908766 | GOODWORK | SMAJ12A | DO-214AC (SMA), 12V standoff, 400W unidirectional TVS | 1
BAT54WS | D3,D4,D5 | D_SOD-323_SILK_CLEAN | C916997 | JSMSEMI | BAT54WS | SOD-323 Schottky diode | 3
KT-0603R | D6 | LED_SMD:LED_0603_1608Metric | C2286 | KENTO | KT-0603R | 0603 red LED | 1
BSMD1206-075-30V | F1 | Fuse_1206_3216Metric | C976305 | BHFUSE | BSMD1206-075-30V | 1206 resettable fuse, 750mA hold, 1.5A trip, 30V | 1
48393-0003 | J1 | USB3_A_Molex_48393-0003_AUTHORIZED_COPY_MODEL_V3 | C3197928 | Molex | 48393-0003 |  | 1
48393-0003 | J2 | USB3_A_Molex_48393-0003_RESERVED_NOT_USB_MODEL_V3 | C3197928 | Molex | 48393-0003 |  | 1
TYPE-C-31-M-12 | J3 | USB_C_Receptacle_HRO_TYPE-C-31-M-12_INTERIOR_FANOUT_V16_C165948_MODEL | C165948 | Korean Hroparts Elec | TYPE-C-31-M-12 | USB Type-C 16P right-angle SMD receptacle | 1
MCNR4030AF-4R7M | L1 | L_Sunlord_SWPA4030S | C49449313 | MYX | MCNR4030AF-4R7M | SMD 4.0x4.0mm, 4.7uH, 2.5A rated, 3A saturation | 1
2N7002 | Q1,Q2 | SOT-23_SILK_CLEAN_V2 | C8545 | Jiangsu Changjing Electronics Technology | 2N7002 | SOT-23 N-channel MOSFET | 2
MMBT3904(RANGE:100-300) | Q3,Q4 | SOT-23_SILK_CLEAN_V2 | C20526 | Jiangsu Changjing Electronics Technology | MMBT3904(RANGE:100-300) | SOT-23 NPN transistor | 2
0603WAF1001T5E | R1,R3,R5,R13,R16 | R_0603_1608Metric_SILK_CLEAN | C21190 | UNI-ROYAL | 0603WAF1001T5E | 0603, 1k, +/-1% | 5
0603WAF1002T5E | R2,R4,R6,R11,R12,R18,R19 | R_0603_1608Metric_SILK_CLEAN | C25804 | UNI-ROYAL | 0603WAF1002T5E | 0603, 10k, +/-1% | 7
0603WAF1000T5E | R7,R9 | R_0603_1608Metric_SILK_CLEAN | C22775 | UNI-ROYAL | 0603WAF1000T5E | 0603, 100R, +/-1% | 2
0603WAF1003T5E | R8,R10 | R_0603_1608Metric_SILK_CLEAN | C25803 | UNI-ROYAL | 0603WAF1003T5E | 0603, 100k, +/-1% | 2
0402WGF5101TCE | R14,R15 | R_0402_1005Metric_SILK_CLEAN | C25905 | UNI-ROYAL | 0402WGF5101TCE | 0402, 5.1k, +/-1% | 2
0603WAF2001T5E | R17 | R_0603_1608Metric_SILK_CLEAN | C22975 | UNI-ROYAL | 0603WAF2001T5E | 0603, 2k, +/-1% | 1
RMS06FT6980 | R20 | R_0603_1608Metric_SILK_CLEAN | C912219 | TA-I | RMS06FT6980 | 0603, 698R, +/-1% (700R nominal ILIM; -0.29% substitution) | 1
0402WGF0000TCE | R21,R22,R23,R24,R25,R26,R27,R28 | R_0402_1005Metric_SILK_CLEAN | C17168 | UNI-ROYAL | 0402WGF0000TCE | 0402, 0R jumper | 8
0603WAF1001T5E | R29 | Resistor_SMD:R_0603_1608Metric | C21190 | UNI-ROYAL | 0603WAF1001T5E | 0603, 1 kΩ, ±1% | 1
K2-1107ST-A4SW-06 | SW1 | SW_SPST_HRO_K2-1107ST-A4SW-06_RESET_V8 | C2837195 | Korean Hroparts Elec | K2-1107ST-A4SW-06 | SMD 6.0x3.6mm, 8.0mm terminal-center span | 1
K2-1107ST-A4SW-06 | SW2 | SW_SPST_HRO_K2-1107ST-A4SW-06_BOOT_V8 | C2837195 | Korean Hroparts Elec | K2-1107ST-A4SW-06 | SMD 6.0x3.6mm, 8.0mm terminal-center span | 1
ESP32-WROOM-32E-N4 | U1 | ESP32-WROOM-32_D0.3mm_SILK_CLEAN | C701341 | Espressif Systems | ESP32-WROOM-32E-N4 | ESP32-WROOM-32 module | 1
AP63203WU-7 | U2 | TSOT-23-6 | C780769 | Diodes Incorporated | AP63203WU-7 | TSOT-23-6 | 1
AP2112K-3.3TRG1 | U3 | SOT-23-5 | C51118 | Diodes Incorporated | AP2112K-3.3TRG1 | SOT-25-5 | 1
TPS2113APWR | U4 | TSSOP-8_3x3mm_P0.65mm_AUTHORIZED_KICAD_COPY | C130052 | Texas Instruments | TPS2113APWR | TSSOP-8 | 1
CH340C | U5 | SOIC-16_3.9x9.9mm_P1.27mm_SILK_CLEAN | C7464026 | WCH | CH340C | SOP-16 | 1
USBLC6-2SC6 | U6 | SOT-23-6 | C7519 | STMicroelectronics | USBLC6-2SC6 | SOT-23-6L | 1

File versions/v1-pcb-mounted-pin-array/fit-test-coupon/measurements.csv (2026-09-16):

parameter | units | measured_value | method
P1_X_from_center | mm | 16.00 | direct physical measurement
P2_X_from_center | mm | 12.00 | direct physical measurement
P3_X_from_center | mm | 8.00 | direct physical measurement
P4_X_from_center | mm | 4.00 | direct physical measurement
P5_X_from_center | mm | 0.00 | direct physical measurement
P6_X_from_center | mm | -4.00 | direct physical measurement
P7_X_from_center | mm | -8.00 | direct physical measurement
P8_X_from_center | mm | -12.00 | direct physical measurement
P9_X_from_center | mm | -16.00 | direct physical measurement
contact_centerline_Y | mm | TBD | depth gauge/caliper
console_opening_size | mm | approximately 1.00 | direct measurement; exact tolerance required
provisional_mating_width | mm | 0.64 | coupon starting value only
provisional_mating_thickness | mm | 0.64 | coupon starting value only
pin_projection_from_console_datum | mm | approximately 8.00 | direct measurement; fit-coupon validation required
pin_total_length | mm | TBD | selected-pin manufacturer drawing
pin_tail_or_retention_geometry | mm | TBD | selected-pin manufacturer drawing
recommended_finished_drill | mm | TBD | selected-pin manufacturer drawing
gold_plating_thickness | um | TBD | selected-pin manufacturer drawing
assembly_method | text | TBD | selected-pin manufacturer drawing and PCBA review
maximum_insertion | mm | TBD | depth gauge
fascia_to_socket_face | mm | TBD | depth gauge
group1_key_profile | mm | TBD | contour/optical
group2_key_profile | mm | TBD | contour/optical
group3_key_profile | mm | TBD | contour/optical
known_plug_insertion_force | N | TBD | force gauge
known_plug_extraction_force | N | TBD | force gauge

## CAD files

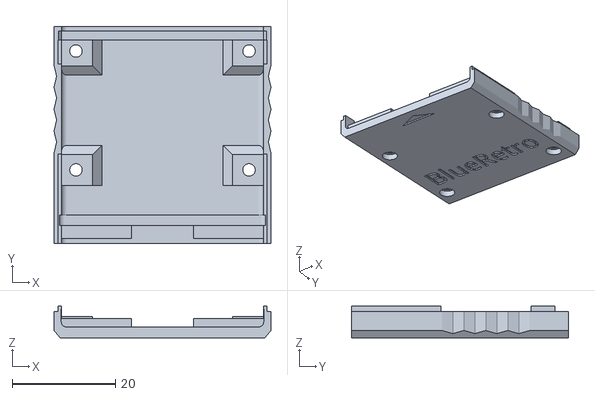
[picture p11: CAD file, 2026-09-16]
versions/v1-pcb-mounted-pin-array/enclosure/reference/BlueRetro2_PS1_top_Ali.stl
42.0 x 42.0 x 6.10

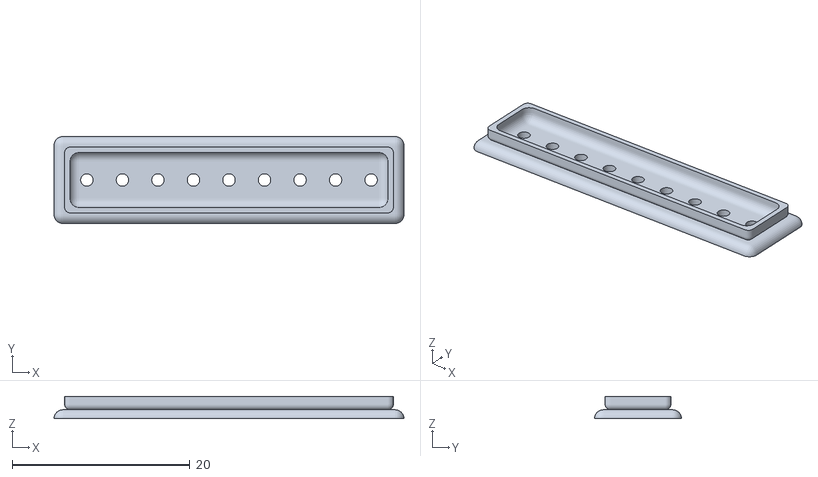
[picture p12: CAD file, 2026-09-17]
versions/v1-pcb-mounted-pin-array/fit-check/stl/9-pin-fitcheck.stl
39.4 x 9.80 x 2.50

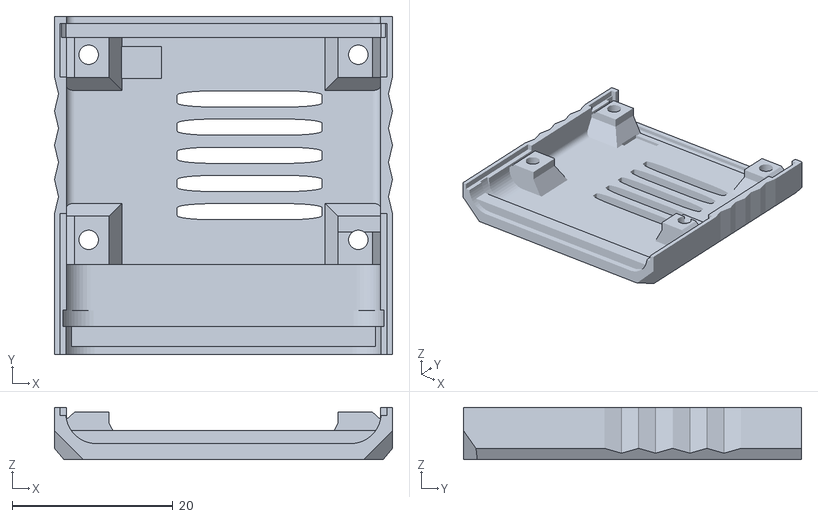
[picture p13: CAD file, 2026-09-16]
versions/v1-pcb-mounted-pin-array/enclosure/reference/BlueRetro2_PS1_bottom_Ali.stl
42.0 x 42.0 x 6.50

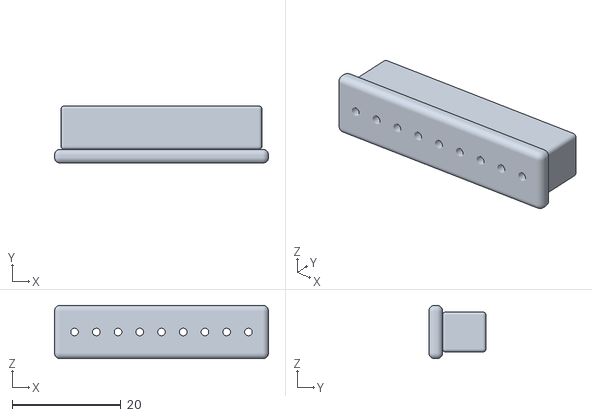
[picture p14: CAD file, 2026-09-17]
versions/v1-pcb-mounted-pin-array/fit-check/stl/playbridge-ps1-fit-check-v4-one-piece.stl
39.4 x 10.5 x 9.80

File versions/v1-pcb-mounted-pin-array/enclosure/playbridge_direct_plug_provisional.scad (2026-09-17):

// PROVISIONAL ONLY — NOT MECHANICALLY VERIFIED OR PRINT-READY.
// Reference meshes remain unscaled. The printed keyed shell must align nine
// bare PCB-mounted male pins and transfer mating loads away from solder joints.

reference_top = "reference/BlueRetro2_PS1_top_Ali.stl";
reference_bottom = "reference/BlueRetro2_PS1_bottom_Ali.stl";

pcb_x = 90;
pcb_y = 70;
pcb_z = 1.6;

// Board-envelope design parameters; validate after component-height measurement.
board_clearance_xy = 0.75;
wall = 2.0;
provisional_body_x = pcb_x + 2 * (board_clearance_xy + wall); // 85 mm
provisional_body_y = pcb_y + 2 * (board_clearance_xy + wall); // 65 mm

// Connector-specific values: deliberately undefined until measured.
TBD_nose_width = undef;
TBD_nose_height = undef;
TBD_shoulder_width = undef;
TBD_shoulder_height = undef;
TBD_shoulder_thickness = undef;
provisional_pin_projection = 16.0;
provisional_capture_section = 8.0;
provisional_console_insertion = 8.0;
TBD_rear_body_depth = undef;
TBD_contact_centerline_z = undef;
provisional_pin_width = 0.64;
provisional_pin_thickness = 0.64;
TBD_pin_mpn = undef;
TBD_pin_tail_retention_geometry = undef;
TBD_production_drill = undef;
TBD_pin_assembly_method = undef;
TBD_console_fascia_clearance = undef;
TBD_adjacent_port_clearance = undef;
TBD_key_profile = undef;
measured_contact_pitch = 4.0;
measured_first_to_last_span = 32.0;
TBD_case_capture_clearance = undef;

module verified_reference_top() { import(reference_top, convexity=10); }
module verified_reference_bottom() { import(reference_bottom, convexity=10); }

module keyed_pin_shell_tbd() {
    assert(is_num(TBD_nose_width), "Measure controller-plug nose width");
    assert(is_num(TBD_shoulder_width), "Measure shoulder before creating load stops");
    assert(is_num(TBD_contact_centerline_z), "Measure pin/PCB vertical relationship");
    assert(is_string(TBD_pin_mpn), "Select coupon-tested male pin MPN");
    assert(is_num(TBD_pin_tail_retention_geometry), "Obtain pin tail/retention drawing");
    assert(is_num(TBD_production_drill), "Set drill from selected pin drawing");
    assert(is_string(TBD_pin_assembly_method), "Define pin assembly process and fixture");
    // Implement only after all TBD values are populated and fit-checked.
}

// Product axis, fixed independently of the still-unmeasured dimensions:
// CONSOLE SIDE -> [8 mm insertion][8 mm printed-nose capture/support][PCB edge][J1]
// PCB/enclosure then extends toward USER SIDE -> [outward-facing USB-C mouth].
// J1 is provisional until pin MPN, tail, drill and assembly method pass coupon testing.
module provisional_male_pin_assembly_tbd() {
    assert(is_num(TBD_nose_width), "PROVISIONAL PLUG: measure nose width");
    assert(is_num(TBD_nose_height), "PROVISIONAL PLUG: measure nose height");
    assert(is_num(TBD_rear_body_depth), "Measure rear pin-retention/PCB cavity");
    assert(is_num(TBD_key_profile), "Digitize keyed mating profile");
    assert(is_num(TBD_case_capture_clearance), "Fit-test enclosure shoulder capture");
    keyed_pin_shell_tbd();
}

// Preview the untouched open-source reference halves only. Do not scale these.
color([0.75,0.85,1.0,0.35]) verified_reference_bottom();
translate([0,0,8]) color([0.75,0.85,1.0,0.20]) verified_reference_top();

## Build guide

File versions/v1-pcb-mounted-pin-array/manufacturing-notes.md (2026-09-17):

# Manufacturing notes

- Product PCB solder mask: red.
- PS1 bare-male-pin fit-test coupon solder mask: red.
- J1 uses provisional 1.00 mm drills and 1.70 mm pads for nine straight male pins on continuous 4.00 mm pitch.
- The coupon starting profile is 0.64 × 0.64 mm square and gold plated, projecting 16.00 mm beyond the PCB-edge datum. The inner 8.00 mm is for printed-nose capture/alignment/support; only the outer 8.00 mm is the console insertion section.
- A nine-pin printed guide has passed an initial simultaneous insertion fit in a spare original PS1 port. Exact pin MPN, tail/retention geometry, manufacturer-recommended finished drill/tolerance, gold thickness and assembly method remain TBD.
- J1 pin 5 is `PS_3V5_CONSOLE`, bench-measured at 3.58 V relative to pin 4/GND with the console powered and ESP32 disconnected. Leave it isolated from all PCB power rails to prevent backfeed. Pin 8 is the only NC.
- Never substitute a 2.54 mm header or alter the measured 4.00 mm pitch.
- No populated PlayBridge PCB is approved until a connector-only coupon passes unpowered fit, retention, continuity, isolation and repeated-cycle testing. The printed keyed shell must carry mating loads.

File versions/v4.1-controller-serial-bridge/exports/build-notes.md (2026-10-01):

# NewPlayBridge2 build notes

- Board: 68 x 60 mm, two copper layers.
- Status: digital order package passes; production remains on HOLD pending
  physical current-limited power, source-switching, manual programming, J1,
  and J2 tests.
- Manual RESET/BOOT is the accepted programming method. The retained DTR/RTS
  network is documented but is not bench-qualified.
- TP1/TP2/TP3 are plated service holes and are DNP. They remain in the
  engineering BOM/position file and are excluded from the assembly BOM/CPL.
- J1 and J2 are proprietary PlayStation harness ports and are not USB.
- See `firmware-handoff.md`, `order-metadata.json`, and the reports directory.

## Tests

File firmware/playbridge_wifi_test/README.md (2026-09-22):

# PlayBridge PS1 wireless bench firmware

This Arduino sketch turns an ESP32 into an experimental digital PlayStation controller. A browser sends button state to the ESP32 over Wi-Fi, and the ESP32 answers controller polls from an original PlayStation through the native controller-port protocol.

This is bench-validation firmware, not production firmware. The breadboard interface described below has been validated on an original PlayStation with visible output captured through OBS. All supported digital buttons were exercised from the browser UI and produced the expected console response. Validation across multiple consoles, games, PCB revisions, and long-duration sessions is still required.

## Current capabilities

- Digital-controller identity (`0x41`)
- D-pad, Select, Start, shoulder buttons, and four face buttons
- Browser controller served directly by the ESP32
- Ordered browser press/release requests with an 80 ms minimum press time for reliable quick clicks
- Local-network station mode plus a fallback access point
- Serial Wi-Fi setup and PS1 protocol diagnostics
- Byte-at-a-time SPI2 responder for complete five-byte PS1 polls
- Open-collector DATA and ACK outputs through external NPN stages
- Protected CMD, ATT, and CLK inputs

Analog sticks, vibration, pressure-sensitive buttons, authentication, and encrypted web control are not implemented.

## Safety and signal rules

The controller cable carries native PlayStation signals. It is not USB, even when a USB-style connector is used as a modular harness.

- Never connect the native-signal harness to a computer, charger, USB hub, or other USB device.
- Power the bench ESP32 from its normal USB development connection.
- Connect ESP32 ground to PS1 controller-port pin 4.
- Leave PS1 pin 3 (`~7.5 V`) isolated from the ESP32 and breadboard power rails.
- Leave PS1 pin 5 (`~3.5 V`) isolated from ESP32 `3V3` and USB power.
- Leave PS1 pin 8 disconnected.
- Turn off the PS1 before inserting, removing, or continuity-testing controller wiring.

## Bench pin mapping

| PS1 pin | Wire used in the validated harness | Signal | Bench connection |
| ---: | --- | --- | --- |
| 1 | White | DATA | NPN open-collector stage driven by GPIO19 |
| 2 | Black | CMD | 1 kΩ protected input to GPIO32 |
| 3 | Brown | Motor supply, approximately 7.5 V | Isolated |
| 4 | Yellow | Ground | ESP32 and breadboard ground |
| 5 | Orange | Console supply, approximately 3.5 V | Isolated |
| 6 | Red | ATT | 1 kΩ protected input to GPIO34 |
| 7 | Grey | CLK | 1 kΩ protected input to GPIO33 |
| 8 | Purple | Unused | Disconnected; the extension may omit this contact |
| 9 | Blue | ACK | NPN open-collector stage driven by GPIO21 |

The bench input stages use a 1 kΩ series resistor and BAT85 clamps to the ESP32 3.3 V and ground rails. DATA and ACK use external NPN transistors so the ESP32 only pulls the console lines low. A `104` (100 nF) capacitor decouples the breadboard 3.3 V and ground rails.

The current GPIO definitions are:

| Function | GPIO |
| --- | ---: |
| DATA drive | 19 |
| ACK drive | 21 |
| CMD sense | 32 |
| CLK sense | 33 |
| ATT sense | 34 |

## Connector orientation

Looking directly at the extension cable's male contact face with the key/top upward:

```text
1 2 3 | 4 5 6 | 7 8 9
```

Looking into its female socket with the key/top upward:

```text
9 8 7 | 6 5 4 | 3 2 1
```

Do not rely on wire colors alone. Confirm every harness with continuity mode while the PS1 and ESP32 are unpowered.

## Build requirements

The validated build used:

- Arduino CLI
- Espressif ESP32 Arduino core 3.3.11
- Board FQBN `esp32:esp32:node32s`
- A classic ESP32 NODE32LITE-style development board

Compile from the repository root:

```sh
arduino-cli compile --fqbn esp32:esp32:node32s firmware/playbridge_wifi_test
```

Upload, replacing the port with the ESP32 serial device on the development computer:

```sh
arduino-cli upload \
  --port /dev/cu.usbserial-DEVICE \
  --fqbn esp32:esp32:node32s \
  firmware/playbridge_wifi_test
```

## Wi-Fi setup

The sketch always starts a fallback access point:

- SSID: `PlayBridge-Test`
- Password: `playbridge`
- Controller page: `http://192.168.4.1/`

It also attempts to reconnect using credentials previously stored by the ESP32 Wi-Fi stack. Before building for another network, change `LOCAL_WIFI_NAME` near the top of `playbridge_wifi_test.ino`.

To save or refresh the password for that SSID:

1. Open the ESP32 serial monitor at 115200 baud.
2. Enter `SET_WIFI`.
3. Enter the Wi-Fi password when prompted. The sketch does not echo it.
4. After connection, use the local IP address printed by the ESP32.

The web server uses plain HTTP and has no authentication. Use it only on a trusted test network.

## Browser control

Open the ESP32 address in a browser. Press and hold a button to assert it; release the pointer to release it. Very quick clicks are automatically stretched to at least 80 ms, and the release request is sent only after the press request completes. The page provides:

- Up, Down, Left, and Right
- Select and Start
- L1, L2, R1, and R2
- Triangle, Circle, Cross, and Square
- Neutral, which releases all buttons

PS1 button bits are active-low. A neutral digital reply is:

```text
FF 41 5A FF FF
```

For example, holding Right produces:

```text
FF 41 5A DF FF
```

## Serial diagnostics

Open the serial monitor at 115200 baud and use:

- `STATUS` — Wi-Fi addresses, SPI state, completed-poll and transaction counters, and the last raw request
- `PAD_STATUS` — current five-byte controller reply and most recent browser input
- `SET_WIFI` — update the password for `LOCAL_WIFI_NAME`

A healthy digital poll uses console address `01`, command `42`, and controller reply:

```text
FF 41 5A <button-low-byte> <button-high-byte>
```

`PS1 completed polls` should continue increasing while the console is polling controller port 1. The decoded `01`/`42` counts and complete five-byte requests are the most useful health checks.

## Validated bench result

On 2026-09-22, the prototype completed a visible end-to-end test using controller port 1 on an original PlayStation and OBS video capture:

1. The PS1 continuously issued complete five-byte `01`/`42` controller requests.
2. The system menu remained stable without phantom or stuck input after reset.
3. Up, Down, Left, Right, Select, Start, L1, L2, R1, R2, Triangle, Circle, Cross, and Square were each tested from the browser UI.
4. Every press produced the expected active-low reply and visible menu action; every release restored `FF 41 5A FF FF`.
5. Quick clicks became reliable after ordered press/release requests and an 80 ms minimum press duration were added.
6. The final status check reported 17,913 completed polls and 89,655 SPI bytes.

The tested connection was `Browser -> Wi-Fi -> ESP32 -> breadboard signal-conditioning circuit -> PS1 controller port 1`.

This verifies the full path from a browser command to a visible response in the PS1 system menu.

### Test photos

Physical PS1 controller-port bench setup:

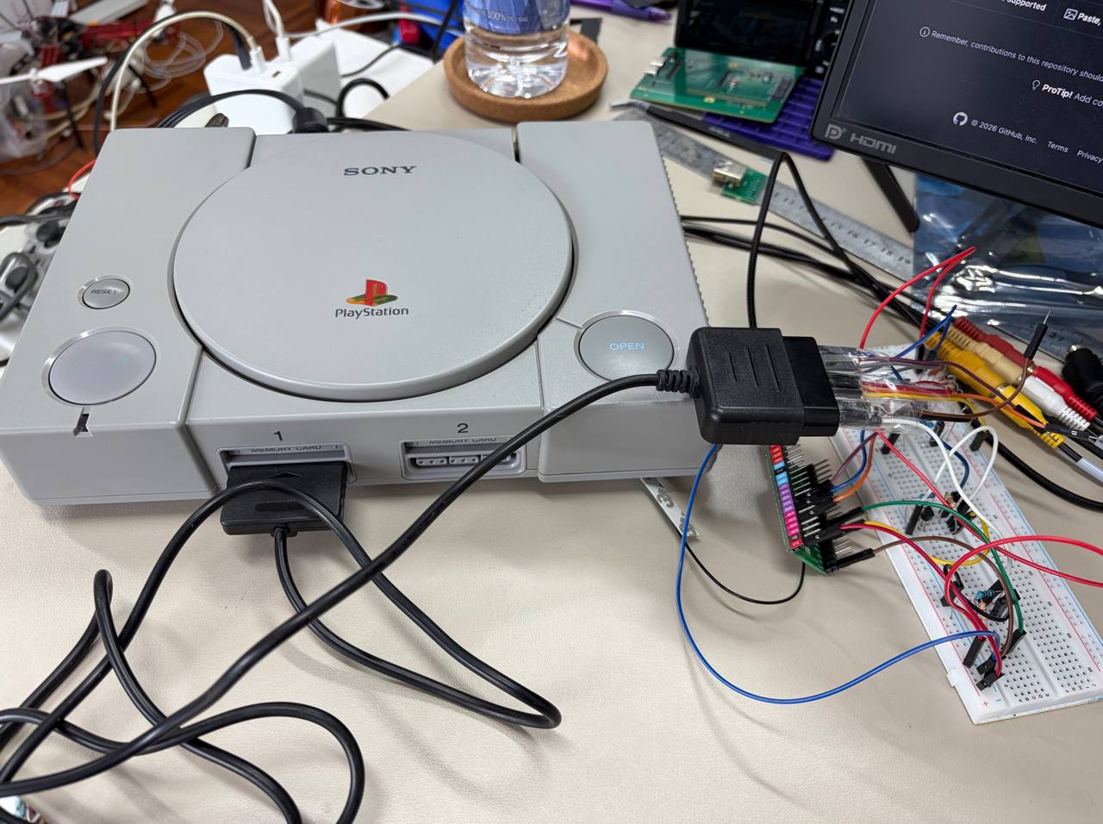
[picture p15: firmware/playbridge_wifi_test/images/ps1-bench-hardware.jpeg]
PlayBridge PS1 bench hardware


Browser controller and OBS validation:

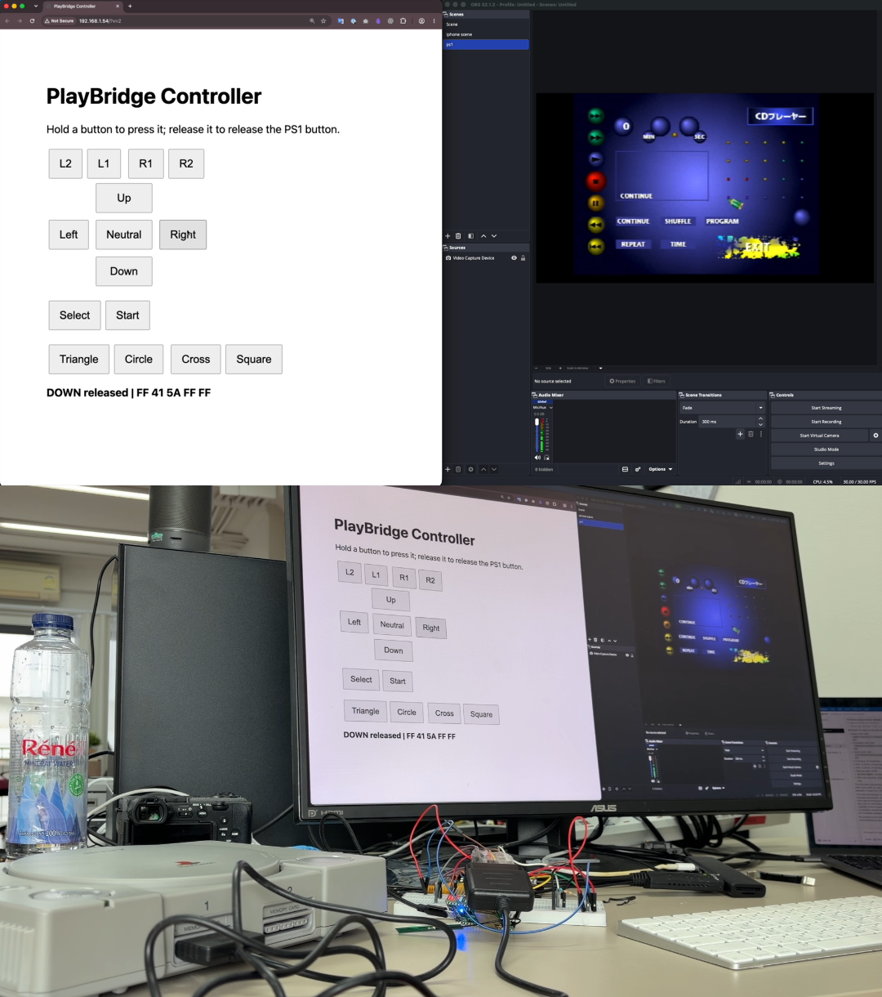
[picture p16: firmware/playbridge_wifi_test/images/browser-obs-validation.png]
PlayBridge browser and OBS validation


## Implementation notes

- PS1 bytes are transferred least-significant bit first.
- SPI2 handles one eight-bit byte per transaction and is re-armed between bytes so ACK can be generated at the protocol boundary.
- DATA remains high-impedance until the responder sees controller address `0x01`; memory-card address `0x81` is ignored.
- ACK is asserted after each of the first four reply bytes following a 14 microsecond wait, then released after a 2 microsecond pulse.
- DATA and ACK logic is inverted by the external NPN stages: GPIO high pulls the PS1 line low, while GPIO low releases it.
- The SPI MISO timing is configured for the delay introduced by the external NPN stage and was validated across the full 40-bit poll.
- The implementation answers as a five-byte digital controller: `FF 41 5A buttons-low buttons-high`.

The byte-at-a-time SPI responder is adapted from the [BlueRetro PSX SPI implementation](https://github.com/darthcloud/BlueRetro), which is licensed under Apache-2.0. The source file retains the corresponding attribution notice.

## Known limitations

- The direct-register SPI implementation is intended for the validated classic ESP32 and Arduino core configuration.
- Breadboard jumpers and long parallel wires can introduce crosstalk and intermittent contacts.
- The fallback AP uses a development password and the webpage is unauthenticated.
- The firmware currently contains a build-time local SSID constant.
- No gameplay test, analog-mode test, vibration test, multi-console test, or long-duration reliability test has been completed.
- Do not treat this bench circuit as a production electrical or mechanical release.

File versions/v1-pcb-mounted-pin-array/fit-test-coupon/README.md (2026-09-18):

# PS1 contact fit-test coupon — NOT FOR ORDER

This coupon precedes the PlayBridge PCB. It contains only:

- nine provisional straight 0.64 × 0.64 mm square test pins for spacing validation; the production connector uses only eight contacts and leaves position 8 empty;
- labels 1 through 9 in PS1 mating-view order;
- nine contact centers on continuous uniform 4.00 mm pitch, with plastic-division reference marks kept mechanically separate;
- PCB-edge datum;
- contact-field centerline;
- approximately 8.0 mm mating projection beyond the console-facing datum;
- shell/nose mechanical reference marks;
- red solder mask.

No active circuitry, donor plug, cable, internal wires, or female socket array is included. The coupon uses the measured 4.00 mm pitch and must not substitute an ordinary 2.54 mm header.

The measured position centers are fixed at `0,4,8,12,16,20,24,28,32 mm`. A printed guide carrying all nine 0.64 mm square test pins was inserted together into a spare original PS1 controller port, so the pitch/span and insertion concept have passed an initial physical fit check. This test does not define the production population: the controller plug has no metal contact at position 8. The outer 8.0 mm is the console mating section; the inner 8.0 mm is reserved for nose capture and support. Exact pin MPN, tail geometry, production drill/tolerance, retention, plating thickness and assembly method remain TBD. Pin 5 is `PS_3V5_CONSOLE` and measured 3.58 V to pin 4/GND; it remains isolated on the PlayBridge MVP. Pin 8 is NC and physically omitted.

Acceptance:

- all eight production contacts enter their matching console contacts without binding, socket damage or permanent deflection, while the empty position 8 remains correctly aligned;
- keyed shell prevents wrong insertion and rotation;
- engagement reaches the measured datum without bottoming;
- pin retention survives repeated insertion;
- the production shell—not pin tails or solder joints—carries insertion force;
- continuity passes for installed positions 1–7 and 9; position 8 remains absent and isolated.

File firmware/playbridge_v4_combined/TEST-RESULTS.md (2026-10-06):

# Combined firmware verification — 2026-10-02

Status: native tests and both ESP32 builds pass. **Bench-profile combined image
flashed; controller movement and real read-only serial transfers verified.**
Simultaneous gameplay/rapid input with serial traffic and the assembled PCB
remain unqualified. The controller-only firmware remains the rollback baseline.

## Executed checks

- Native controller protocol and button lease tests: PASS for both profiles.
- Actual transport core under AddressSanitizer and UndefinedBehaviorSanitizer:
  PASS. Covers binary forwarding, partial writes, queue backpressure, independent
  stall deadlines, disconnect/reconnect cleanup, UART/socket faults, single
  ownership, malformed controls, all supported baud requests, bounded drain,
  clock rollover, duplicate/lost-ACK controls, and failed baud changes.
- Embedded browser script with mocked DOM/network: PASS for press/release,
  chords, heartbeat, cancel/blur, serialized updates, neutral, network errors
  and page exit.
- Arduino CLI 1.5.1, Arduino-ESP32 3.3.11 (ESP-IDF 5.5.5), Node32s: PASS for
  default bench profile and explicitly selected V4 PCB profile.
- ELF symbol inspection: both profiles place controller `exchange` and
  `pollBus` in `.iram0.text`.
- Git whitespace/error check: PASS.

| Compiled profile | Program bytes / 1,310,720 | Static RAM bytes / 327,680 |
| --- | ---: | ---: |
| 1 — working bench pin map | 942,392 | 65,760 |
| 2 — V4 PCB pin map | 942,384 | 65,760 |

Locally generated application binary SHA-256 values:

- Bench: `d9149f65b6262d916cbd0fd903daa90e7038ccbdd131227623361f3f64dca870`
- PCB: `56e2dd3263a751f37990032d135bd0d4e3dc5f2119894aacd165f6cf3ee2311a`

These identify this verification run, not a reproducible-build guarantee.
Binaries and build caches are not committed. A subsequent source comment
correction only clarifies that the serial task now owns GPIO16/17.

## Subsequent bench checks — 2026-10-02

The bench binary identified above was flashed and its upload hash verified.
The user confirmed movement in the web-controller UI on this combined image.
This does not extend the earlier every-button confirmation to a new simultaneous
controller/serial stress test.

### Harness and electrical changes

- UART2 remains TX GPIO17 / RX GPIO16, 115200 8N1, no inversion/flow control.
- Continuity and readable Unirom startup output established ground and the
  console-TX receive path. Final bench mapping: yellow console RX via **220 Ω**
  to GPIO17; orange console TX via **1 kΩ** to GPIO16; green to common GND.
  Colours identify this particular verified harness only, not a standard.
- A **10 kΩ** pull-up connects the orange/harness-side end of its 1 kΩ resistor
  to verified ESP32 3.3 V. It removed UART noise with the console disconnected.
  The orange junction is in A30/B30/C30 on this particular breadboard; the
  opposite F30–J30 group is separate across the centre gap. Row coordinates
  must not be generalized to another layout.
- The yellow TX resistor was originally 1 kΩ. Changing it to 220 Ω was followed
  by command echoes and later successful dumps. A voltage-divider explanation
  was a hypothesis, not an oscilloscope-confirmed cause.
- With the pull-up and console disconnected: 4 UART bytes sent, 0 received,
  no UART errors. Reconnecting the console restored the PING echo. No wire
  swapping or PCB-value change is justified by the echo alone.

### Transport and real-console evidence

1. With the PS1 disconnected, UART loopback returned 65,536 bytes exactly at
   115200 (8.077 s), then 131,072 bytes exactly at each higher supported rate:
   230400 (9.798 s), 518400 (3.966 s), 691200 (2.276 s), 1036800 (1.996 s),
   2073600 (1.612 s). Hash comparisons passed; UART/socket errors were zero.
   These are loopback observations, not PS1 throughput qualifications.
2. Passive capture received readable Unirom 8.0.K startup text from console
   TX through ESP32 RX16 and Wi-Fi. Boot-time UART errors occurred; error-free
   transfer claims below refer to counter deltas during those tests, not to
   lifetime counters.
3. PING returned `PING` (including with a three-second receive window and a
   separately paced-byte test), not `PONG`. The user reported the same PING
   limitation in their working Windows setup. Therefore the old local PING UI
   verdict was not a reliable end-to-end acceptance gate for this console.
4. Two 64-byte RAM dumps succeeded at 115200: `0x80010000` (all zero) and
   `0x80000080` (40 nonzero bytes). Handshake: `DUMPOKV2OKAY`, with host `UPV2`.
   The latter had additive checksum **2992**, matching the console; each test
   had 16 host-to-UART bytes, 80 UART-to-host bytes and zero new UART/socket
   errors. Nonzero dump SHA-256:
   `9b9456c961739dcd4ddbec1957fb1c214aab95f6780c814dad58235e5c233a13`.
5. Physical memory-card **slot 1**: **131,072 bytes** read via Unirom to temporary
   PS1 RAM at `0x80080000`, then through rear serial → ESP32 → Wi-Fi → Mac →
   mounted exFAT SD card. Protocol V2 checksum **0x014ac447** matched; raw image
   began with `MC`. The saved file's SHA-256 matched its in-memory payload on
   read-back. No memory-card writes were requested. Transfer elapsed time for
   the successful continuation was **52.815 s**, including card read and host
   transfer; this is not a pure Wi-Fi throughput measurement.

The first card-download attempt followed the newer client's `MCDN → HLTD`
expectation and timed out without sending a card index or saving a file. The
older client source confirmed **`MCDN → OKAY`**. The bench session was continued
once by sending slot index 0, then receiving `MCRD` and performing the dump.
During that successful continuation, counter deltas were TX/TCP-to-UART **276**,
RX/UART-to-TCP **131,100**, UART errors **0**, socket errors **0**. These exclude
the initial MCDN negotiation. The repository tool uses the corrected complete
sequence; its refactored CLI is offline-tested, not claimed as a second physical
card backup run. No blind resume feature is shipped.

Personal memory-card contents, the backup image, its per-file manifest, private
host paths and network configuration are intentionally **not committed**.
Only non-content measurements and source/test tooling are included.

### Host-tool regression checks

`tests/test_memcard_backup.py` exercises fragmented V2/V3 handshakes and full
synthetic card transfers, slot indexing, 2048-byte MORE pacing, checksum
rejection, echo-only timeout, console error tokens, RAM buffer bounds, readiness
guards, exclusive file creation and file read-back. No hardware/network used.

## Limits

Native tests mock physical GPIO/UART/network behavior. The ESP32 adapter has
now been exercised on the bench as described above. The UART driver reset and
nonblocking drain implementation were reviewed against the installed API and
[ESP-IDF 5.5.5 UART source](https://github.com/espressif/esp-idf/blob/v5.5.5/components/esp_driver_uart/src/uart.c).
Source review alone does not establish physical behavior beyond the recorded tests.

Static RAM figures exclude runtime task stacks, UART rings, TCP/Wi-Fi buffers,
and other heap allocations. Monitor heap/stack and UART error counters during
hardware qualification. There is no hardware flow control.

The earlier every-button confirmation applies to the controller-only sketch.
Combined-build movement and a read-only serial backup are now verified, but
Mac-to-PS1 game loading, high-speed PS1 transfers, simultaneous gameplay,
write/restore operations and assembled V4 PCB electrical qualification are not.
External PS1 patches, PC asset server and game assets are not included. Follow
the README acceptance checklist before production claims or assembled-PCB use.

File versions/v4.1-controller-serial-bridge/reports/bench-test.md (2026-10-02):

# NewPlayBridge2 V4.1 current-limited bench-test plan

Status: **NOT EXECUTED - PRODUCTION HOLD**

No assembled board, programmable supply, DMM, oscilloscope, PlayStation
harness/system, or USB host is connected to this workspace. EDA checks and 3D
renders are not substitutes for the measurements below.

## Pre-power

1. Inspect polarity and soldering at J3, F1/F2, D1/D2, U4/U6, J5, L1,
   Q1/Q2, Q4/Q5, and U1.
2. Confirm no low-resistance short from USB VBUS, J1 pin 8, 5 V, or 3.3 V to
   GND.
3. Confirm continuity from J1 pin 4 and both J1 retention tabs to GND, and
   from J2 pin 7 and both J2 retention tabs to GND.

## USB-only power and programming

1. Apply 5.0 V at J3 with a 100 mA limit for the initial smoke check, then
   raise to 500 mA for ESP32 startup peaks after verifying the rails.
2. Measure protected USB 5 V and 3.3 V; confirm no abnormal heating.
3. Confirm D8 power LED operation and firmware control of D9 status LED.
4. Confirm CH340 enumeration and UART0 logging.
5. Verify programming with the accepted manual sequence: hold BOOT (SW2),
   pulse RESET (SW1), then release BOOT.

The existing DTR/RTS-assisted network may be characterized, but automatic
programming is not a production acceptance requirement because manual
BOOT/RESET is explicitly accepted. Do not describe DTR/RTS operation as
bench-qualified until it is measured on hardware.

## PS1 power and source switching

1. With USB removed, feed the verified PS1 harness voltage into J1 pin 8 from
   a current-limited supply, starting at 100 mA.
2. Verify AP63203, TPS2116, AP2112K, and the final 3.3 V rails.
3. Confirm no reverse voltage appears at USB VBUS.
4. Apply USB and PS1 sources together; verify source selection, stable output,
   and no reverse-current/source-contention fault.

## Interfaces

1. Verify CMD GPIO19, CLK GPIO32, and ATT GPIO21 directions and waveforms.
2. Verify Q1 DATA and Q2 ACK are high impedance when released and pull low
   when GPIO33/GPIO27 assert their gates; verify GPIO34 senses ACK.
3. Verify J2 pin 1 TX from GPIO17, pin 4 RX to GPIO16, and pin 7 GND. Confirm
   J2 causes no activity on UART0 GPIO1/GPIO3.
4. Verify service-hole order GND/TX/RX and 3.2 mm pitch.

## Required recorded results

| Test | Required evidence | Status |
| --- | --- | --- |
| USB current-limited power | Input current and 5 V/3.3 V measurements | NOT EXECUTED |
| PS1 current-limited power | Input current and regulator measurements | NOT EXECUTED |
| Dual-source switching | TPS2116 selection and reverse-current measurements | NOT EXECUTED |
| Manual programming | CH340 enumeration and successful manual BOOT/RESET upload | NOT EXECUTED |
| J1 controller interface | CMD/CLK/ATT and open-drain DATA/ACK captures | NOT EXECUTED |
| J2 serial interface | TX/RX voltage and UART transaction captures | NOT EXECUTED |

Production approval remains blocked until an operator records passing results.

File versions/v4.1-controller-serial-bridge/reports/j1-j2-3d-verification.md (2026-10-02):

# J1/J2 exact-model verification

Date: 2026-10-01

## Model source

- Part: Hong Cheng HC-USB3.0-L168-ZP, LCSC C7501856
- Project model: `PlayBridge.3dshapes/HC-USB3.0-L168-ZP_C7501856.wrl`
- STEP SHA-256: `f520a450f9d80237587fb2a4dddd8b4d12c20504a3b4a4d833d242cad28aa385`
- WRL SHA-256: `cd701c8fe0843f3be053458451192e131f831f955c700702210e23dc49a00f45`
- Both hashes exactly match the supplied v3.0 reference assets.

## Authoritative transform and geometry

Both supplied reference footprints assign the WRL HC model with:

- offset: `(0, 0, 0) mm`
- scale: `(1, 1, 1)`
- rotation: `(0, 0, 0) degrees`

The current J1 and J2 footprints retain the same anchor-relative signal-hole and
retention-slot centers as the supplied references:

| Feature | Local X (mm) | Local Y (mm) |
| --- | ---: | ---: |
| Pin 1 | -3.5 | -0.3 |
| Pin 2 | -1.0 | -0.3 |
| Pin 3 | 1.0 | -0.3 |
| Pin 4 | 3.5 | -0.3 |
| Pin 5 | 4.0 | -1.8 |
| Pin 6 | 2.0 | -1.8 |
| Pin 7 | 0.0 | -1.8 |
| Pin 8 | -2.0 | -1.8 |
| Pin 9 | -4.0 | -1.8 |
| Left retention slot | -6.4 | 1.8 |
| Right retention slot | 6.4 | 1.8 |

J1 anchor: `(14.0, 48.5) mm`; retention-slot centers:
`(7.6, 50.3)` and `(20.4, 50.3) mm`.

J2 anchor: `(39.2, 48.5) mm`; retention-slot centers:
`(32.8, 50.3)` and `(45.6, 50.3) mm`.

No connector footprint anchor, pad, slot, connected route, net, zone, or
board-outline coordinate was changed. The board-specific connector body
overhang is 2.0 mm at the lower edge; every signal pin and retention slot
remains supported by PCB material.

## Through-board Z verification

The board stackup thickness is `1.600 mm`. Direct measurement of the bound WRL
geometry, after applying its native VRML scale, gives a minimum model Z of
`-2.800096 mm` relative to the footprint datum. With the model bound at the
authoritative zero Z offset, the nine signal tails and both shell-retention
legs therefore extend `1.200096 mm` beyond the PCB underside. This is the
solderable protrusion visible in the close side and oblique-underside renders.

No visual-only X, Y, or Z correction was applied. The PCB footprints and the
model bindings remain at their validated coordinates and zero transform.

The STEP file was also rendered at the same zero transform. It does not share
the WRL model's effective KiCad frame and visibly mis-registers the body/pin
field. It is retained as source geometry but is not bound to J1/J2. No
compensating visual offset was introduced.

## Visual verification

- `renders/j1-orthographic-top.png`
- `renders/j1-orthographic-bottom.png`
- `renders/j1-orthographic-side.png`
- `renders/j1-mechanical-underside.png`
- `renders/j1-mechanical-side.png`
- `renders/j2-orthographic-top.png`
- `renders/j2-orthographic-bottom.png`
- `renders/j2-orthographic-side.png`
- `renders/j2-mechanical-underside.png`
- `renders/j2-mechanical-side.png`

The independent orthographic bottom views expose all nine plated-hole centers
and both retention slots. The new close oblique-underside views show all nine
metal signal tails emerging from those holes, and the close edge-on views show
the tails and both retention legs extending below the 1.6 mm PCB. The modeled
pins/tabs are concentric with their corresponding PCB holes for J1 and J2.

## Electrical verification

- ERC: 0 errors, 0 warnings.
- Final parity-enabled DRC: 0 violations, 0 unconnected items, and 0 schematic
  parity issues (`reports/drc-final.rpt`).

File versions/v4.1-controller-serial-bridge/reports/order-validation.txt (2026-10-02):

NEWPLAYBRIDGE2 V4.1 ORDER PACKAGE VALIDATION - 2026-10-01

Fabrication archive
  exports/fabrication.zip: PASS (unzip integrity test)
  archive entries: 13
  Gerbers: F.Cu, B.Cu, F.Mask, B.Mask, F.Silkscreen, B.Silkscreen, Edge.Cuts
  drills: plated and non-plated Excellon files
  routed vias: 190 hits, 0.900 mm copper / 0.400 mm drill
  drill maps: plated and non-plated PDF maps
  auxiliary: Gerber job and drill report

BOM / placement consistency
  engineering BOM references: 80 unique
  engineering position references: 80 unique
  assembly BOM references: 77 unique
  assembly CPL references: 77 unique
  assembly BOM / CPL reference mismatch: 0
  assembly rows with blank LCSC code: 0
  DNP service holes: TP1, TP2, TP3

Board
  outline: 68.0 x 60.0 mm
  copper layers: 2
  ERC errors/warnings: 0 / 0
  DRC violations/unconnected/parity issues: 0 / 0 / 0

Release status: DIGITAL PACKAGE PASS; PRODUCTION HOLD PENDING PHYSICAL TESTS

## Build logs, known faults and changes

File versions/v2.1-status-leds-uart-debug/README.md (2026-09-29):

# PlayBridge V2.1 — status and service/debug revision

This directory is the authoritative V2.1 project derived from frozen V2.0.

## Implemented changes

- D1 is the green firmware `STATUS` LED: Everlight `19-217/GHC-YR1S2/3T` / LCSC `C72043`, driven by ESP32 module pin 26 on `STATUS_LED` through R13, 1 kΩ UNI-ROYAL `0603WAF1001T5E` / `C21190`.
- D6 is the red always-on 3V3 `PWR` LED: KENTO `KT-0603R` / `C2286`, through R29, 1 kΩ UNI-ROYAL `0603WAF1001T5E` / `C21190`.
- The physical J4 header was removed. The lower-right SERVICE/DEBUG row contains DNP plated holes: TP2 GND at (43.500, 54.000) mm, TP3 UART_TX at (46.700, 54.000) mm, and TP4 UART_RX at (49.900, 54.000) mm. Pitch is 3.200 mm; each pad is 2.0 mm with a 1.0 mm finished plated hole.
- J1, J2, J3, and SERVICE / DEBUG are explicitly identified on F.Silkscreen. No J4 reference is fabricated in V2.1; the planned third SNAC-style connector in V2.2 will take reference J4.
- TP1 remains the existing 3V3 test point. UART signals are 3.3 V logic only.
- RESET, BOOT, J1/J2/J3, USB orientations, antenna keepout, outline, and unrelated V2.0 placement/copper remain unchanged.

## Final verification and outputs

Verified 2026-09-25: DRC 0 errors, 0 unconnected, and only three approved historical `track_dangling` warnings; ERC 0 errors/0 warnings; schematic/PCB parity 0; release gate PASS.

- Accepted verification renders: `renders/service-debug-full-top.png` and `renders/service-debug-close.png`.
- Generic outputs: `exports/gerbers/`, `exports/gerbers/board.drl`, `exports/bom.csv`, `exports/positions.csv`, `exports/assembly-bom.csv`, `exports/assembly-cpl.csv`, `exports/netlist.net`, and `exports/fabrication.zip`.
- JLCPCB preparation: `ordering/jlcpcb-bom.csv`, `ordering/jlcpcb-cpl.csv`, and `ordering/gerbers-jlcpcb.zip`.
- Detailed evidence: `reports/V2.1-AUDIT.md`.

**DO NOT ORDER:** pending final human render, mechanical, BOM/CPL rotation, substitution, and live-stock review.

The fabrication exports and validation reports have been regenerated for V2.1.

V2 replaces the PCB-mounted PlayStation pin array with a removable donor-plug harness.

The main PlayBridge board will expose removable multi-contact connectors. A console-specific adapter will use a genuine donor controller cable and molded PlayStation male plug soldered to a matching breakout board. Swapping the adapter cable will make it possible to support other console systems without manufacturing their proprietary plug contacts directly on the main PCB.

## Architecture

- Keep the ESP32, signal protection and protocol-generation circuitry on the main board.
- Replace the console-facing PCB pin array with a removable cable interface.
- Use the genuine molded PlayStation donor plug for console alignment, contact geometry and insertion loads.
- Map every donor wire by continuity testing; never rely on wire color.
- Treat the observed missing pin 8 as a donor-plug property that must be verified electrically.
- Define connector pin allocation, power/backfeed protection, shield policy and cable requirements before designing the V2 PCB.
- Add other console adapters only after the PS1 harness is validated.

## Safety warning

The concept currently uses USB 3 Type-A connector hardware because it provides enough inexpensive contacts and readily available breakout boards. The signals would be native console signals—not USB. Any implementation must be clearly marked **NOT USB**, protected against accidental connection to computers/chargers, and reviewed before hardware is powered.

## References

- [`concepts/`](concepts/) contains the supplied system architecture, breakout-board example and illustrative product layout.
- [`references/ps1-donor-plug/`](references/ps1-donor-plug/) contains photographs of the actual donor plug, including the empty pin-8 position.

## V2.0.0 baseline checkpoint

This directory began as a self-contained copy of the V2.0.0 release snapshot. It includes the
KiCad project, FabDesk netlist/configuration, local symbol/footprint/3D-model
libraries, verification reports, manufacturing package, release tools,
references, and accepted renders.

The baseline details below remain useful for comparison, but V2.1 must pass a
fresh release gate after modification.

- Board: 56.295 × 62.000 mm, four layers, 1.20 mm thick.
- J1: Molex 48393-0003 / JLCPCB C3197928 used as a nine-contact **non-USB** PS1 donor-harness interface.
- J2: the same connector reserved for a future rear-serial harness; its contacts remain intentionally unassigned until that interface is characterized.
- J1/J2 use `Molex_48393-0003_TraceParts_exact_visual.wrl`, converted from the exact TraceParts catalog preview for 48393-0003. Registration is documented in `PlayBridge.3dshapes/README_MOLEX_48393-0003_TRACEPARTS.md`.
- J1 is at (4.525, 50.525) mm, J2 at (22.525, 50.525) mm, both at 0°, with their mating mouths facing outward through the lower edge. F1 is at (12.500, 38.000) mm. J3 remains at (51.025, 9.625) mm, 90°, facing outward through the right edge.
- ERC, DRC, schematic parity, and connectivity currently pass with zero errors, warnings, or unconnected items. Ordering remains subject to the sourcing and PCBA-completeness checks in `ordering/`.

See [`RELEASE-v2.0.0.md`](RELEASE-v2.0.0.md) for the release gate,
manufacturing-package status, 3D-model provenance, and remaining checkout hold.

## Snapshot layout

- `board.kicad_*`, `circuit.netlist.json`, and `fabdesk.json` — complete V2 design.
- `PlayBridge.pretty/`, `PlayBridge.3dshapes/`, and the symbol libraries — project-local libraries required to reopen the design.
- `ordering/` — Gerber archive, BOM, CPL, sourcing audit, and checkout hold.
- `reports/` — release build, DRC, ERC, statistics, and gate reports.
- `tools/` — scripts used for model inspection and order-file generation.
- `renders/` — accepted V2.0.0 renders only.

## USB-A mechanical fit

J1 and J2 use the official Molex 48393-0003 through-hole pattern: nine 0.70 mm
signal holes plus four polarized shell-retention slots. The 13.80 × 14.25 mm
connector body fits the footprint and requires no PCB cutout. With the current
placement, its mating lip projects 0.275 mm beyond the straight board edge so
the cable remains accessible, while every signal pin and retention leg remains
inside the board outline. The V2 PCB thickness is 1.20 mm, matching the PCB
thickness stated on Molex drawing `483930003_sd.pdf`.

## 3D-model validation

The datasheet-derived model contains separate solids for all nine signal tails
and four shell-retention posts. Their centerlines match the corresponding
footprint holes/slots with a reported XY delta of 0.000 mm. The model uses zero
offset and zero rotation in the footprint frame; its WRL scale is
`0.3937007874` on all axes. The nominal tails/posts extend 1.10 mm below the
top seating datum on the 1.20 mm PCB.

The production footprints retain the official Molex entry geometry. The
TraceParts visual model is used for populated-board inspection, while the
datasheet-derived section proof remains available for dimensional audit.
See `PlayBridge.3dshapes/README_MOLEX_48393-0003_TRACEPARTS.md` and
`PlayBridge.3dshapes/Molex_48393-0003_DATASHEET_DERIVED_README.md`.

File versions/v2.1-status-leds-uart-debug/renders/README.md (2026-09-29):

# Accepted V2.1 verification renders

- `service-debug-full-top.png`: bright populated full-top KiCad render showing the complete board, both USB-A bodies, USB-C, antenna/module, RESET, BOOT, STATUS, PWR, and the lower-right GND/TX/RX service row.
- `service-debug-close.png`: corrected lower-board close view showing STATUS, PWR, BOOT, both USB-A relationships, board edge, and the unobstructed GND/TX/RX holes.

Both renders show board surface, routing, pads, vias, silkscreen, and populated component models without selection borders or application UI.

SHA-256:

```text
383c5050c014bc21f2286277cde47892aabb3d7aaaf03e59859af51b7aeb5a22  service-debug-full-top.png
8d876d6af57bd42fa26932f45aeba3c829c0efe7d64f4039b675d4db12052a4d  service-debug-close.png
```

Older J4 and intermediate render files are obsolete historical artifacts and are not release deliverables.

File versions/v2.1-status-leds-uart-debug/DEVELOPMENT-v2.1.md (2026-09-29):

# PlayBridge V2.1 development record

V2.1 is derived from frozen V2.0 and preserves its USB connectors, switches, ESP32 placement/antenna keepout, outline, and unrelated routing.

Final scoped changes:

- D1/R13: green firmware STATUS LED on ESP32 module pin 26, `STATUS_LED`, 1 kΩ series resistance.
- D6/R29: red always-on 3V3 POWER LED, 1 kΩ series resistance.
- J4 removed.
- J1/J2/J3 and SERVICE / DEBUG added as explicit F.Silkscreen interface labels. J4 is reserved for the planned third SNAC-style connector in V2.2.
- TP1 retained as 3V3.
- TP2 GND (43.500,54.000), TP3 UART_TX (46.700,54.000), TP4 UART_RX (49.900,54.000); DNP 2.0/1.0 mm plated holes at 3.2 mm pitch.

Final board SHA-256: `1a1a1da305ea273c94f223b624208c1a9615784997cdfd1591985f96933a2df3`.

Final checks dated 2026-09-25: DRC 0 errors/0 unconnected with only three accepted historical dangling-track warnings; ERC 0/0; parity 0; release gate PASS.

See `reports/V2.1-AUDIT.md` for measurements and `ordering/DO-NOT-ORDER.md` for the remaining human review hold.

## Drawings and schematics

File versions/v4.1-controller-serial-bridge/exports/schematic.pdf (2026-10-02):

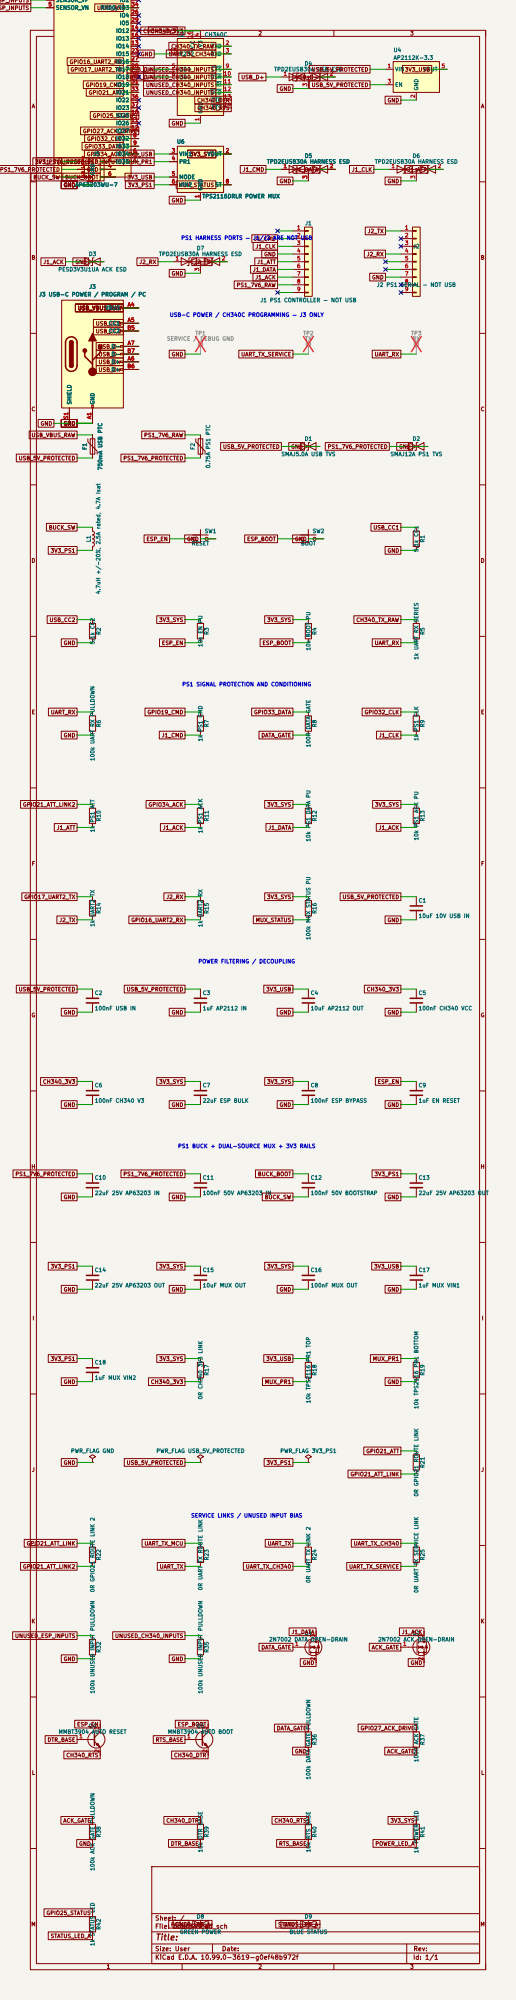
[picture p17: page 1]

4 UD+ 5 UD- 6 CTS 9 DSR 10 RI 11 DCD 12 DTR 13 RTS 14 R232 15 VCC U2 16CH340C

J3 USB-C POWER / PROGRAM / PC

J3 USB-C POWER / PROGRAM / PC GND A1

PS1 SIGNAL PROTECTION AND CONDITIONING

PS1 BUCK + DUAL-SOURCE MUX + 3V3 RAILS POWER FILTERING / DECOUPLING

SERVICE LINKS / UNUSED INPUT BIAS

2N7002 DATA OPEN-DRAIN R32 100k UNUSED INPUT PULLDOWN

Size: User | Rev:
KiCad E.D.A. 10.99.0-3619-g0ef48b972f | Id: 1/1

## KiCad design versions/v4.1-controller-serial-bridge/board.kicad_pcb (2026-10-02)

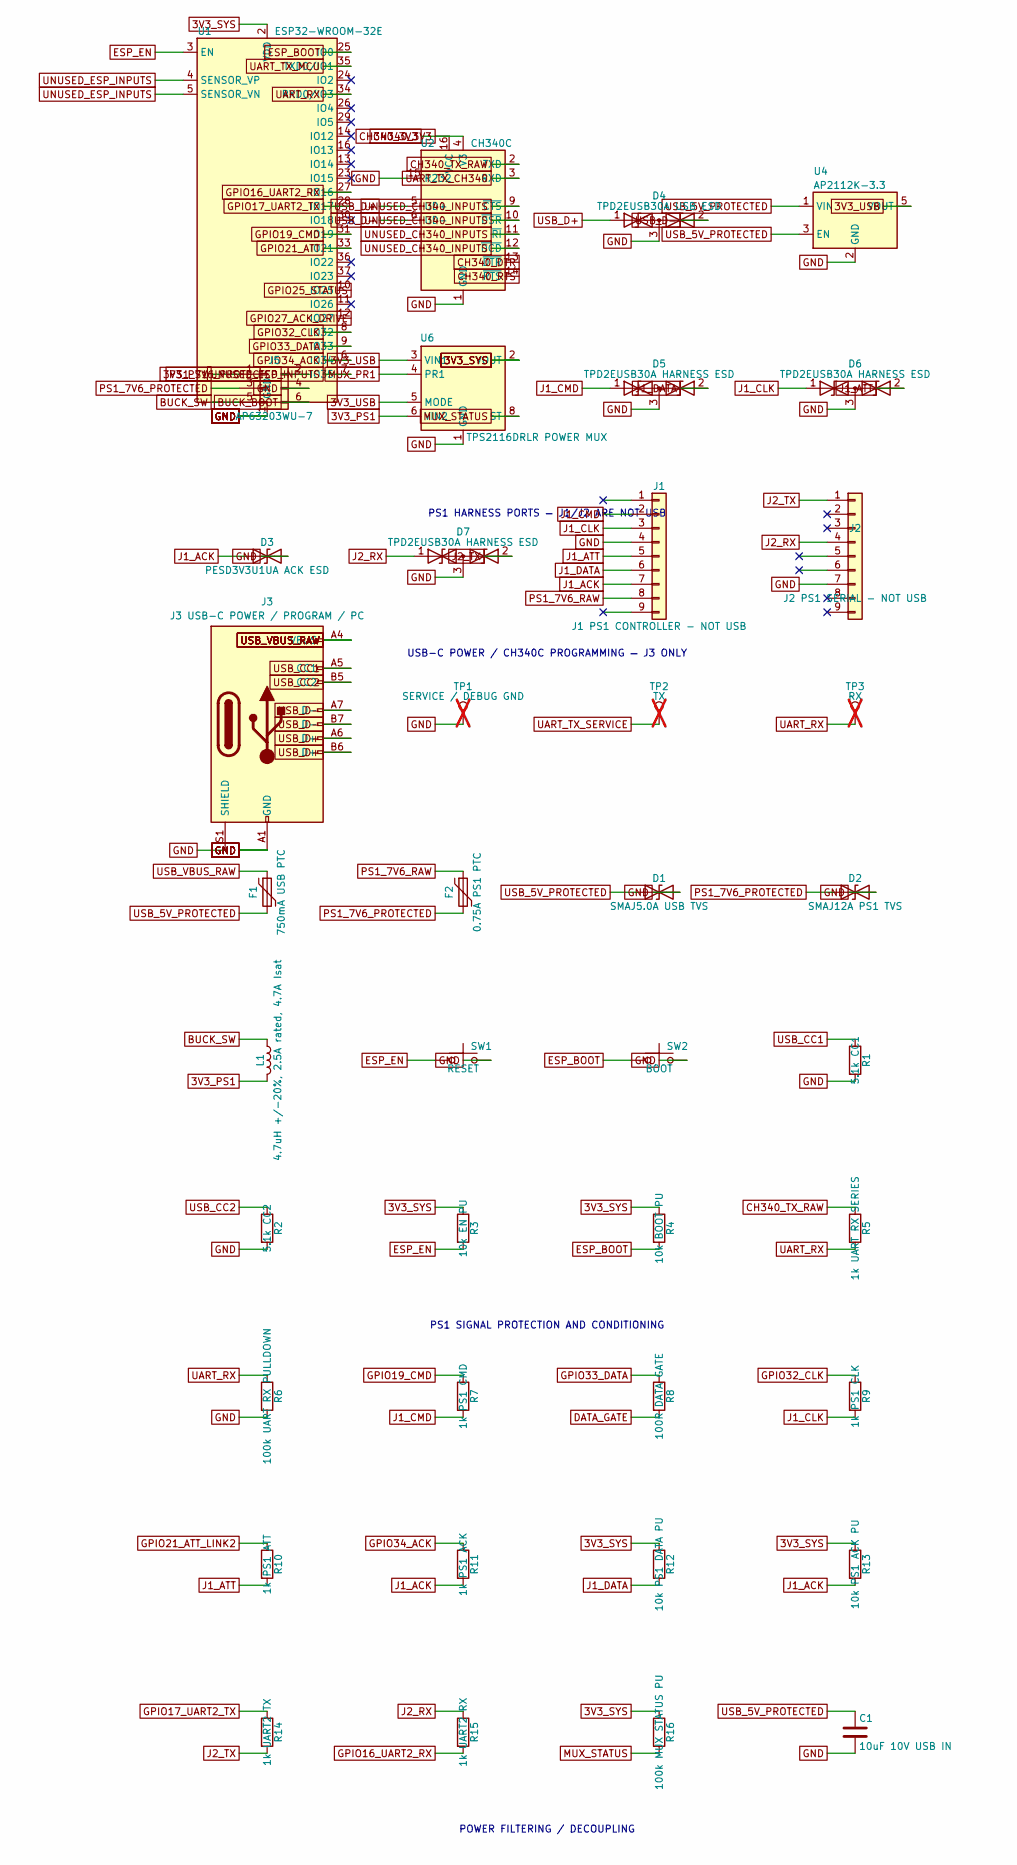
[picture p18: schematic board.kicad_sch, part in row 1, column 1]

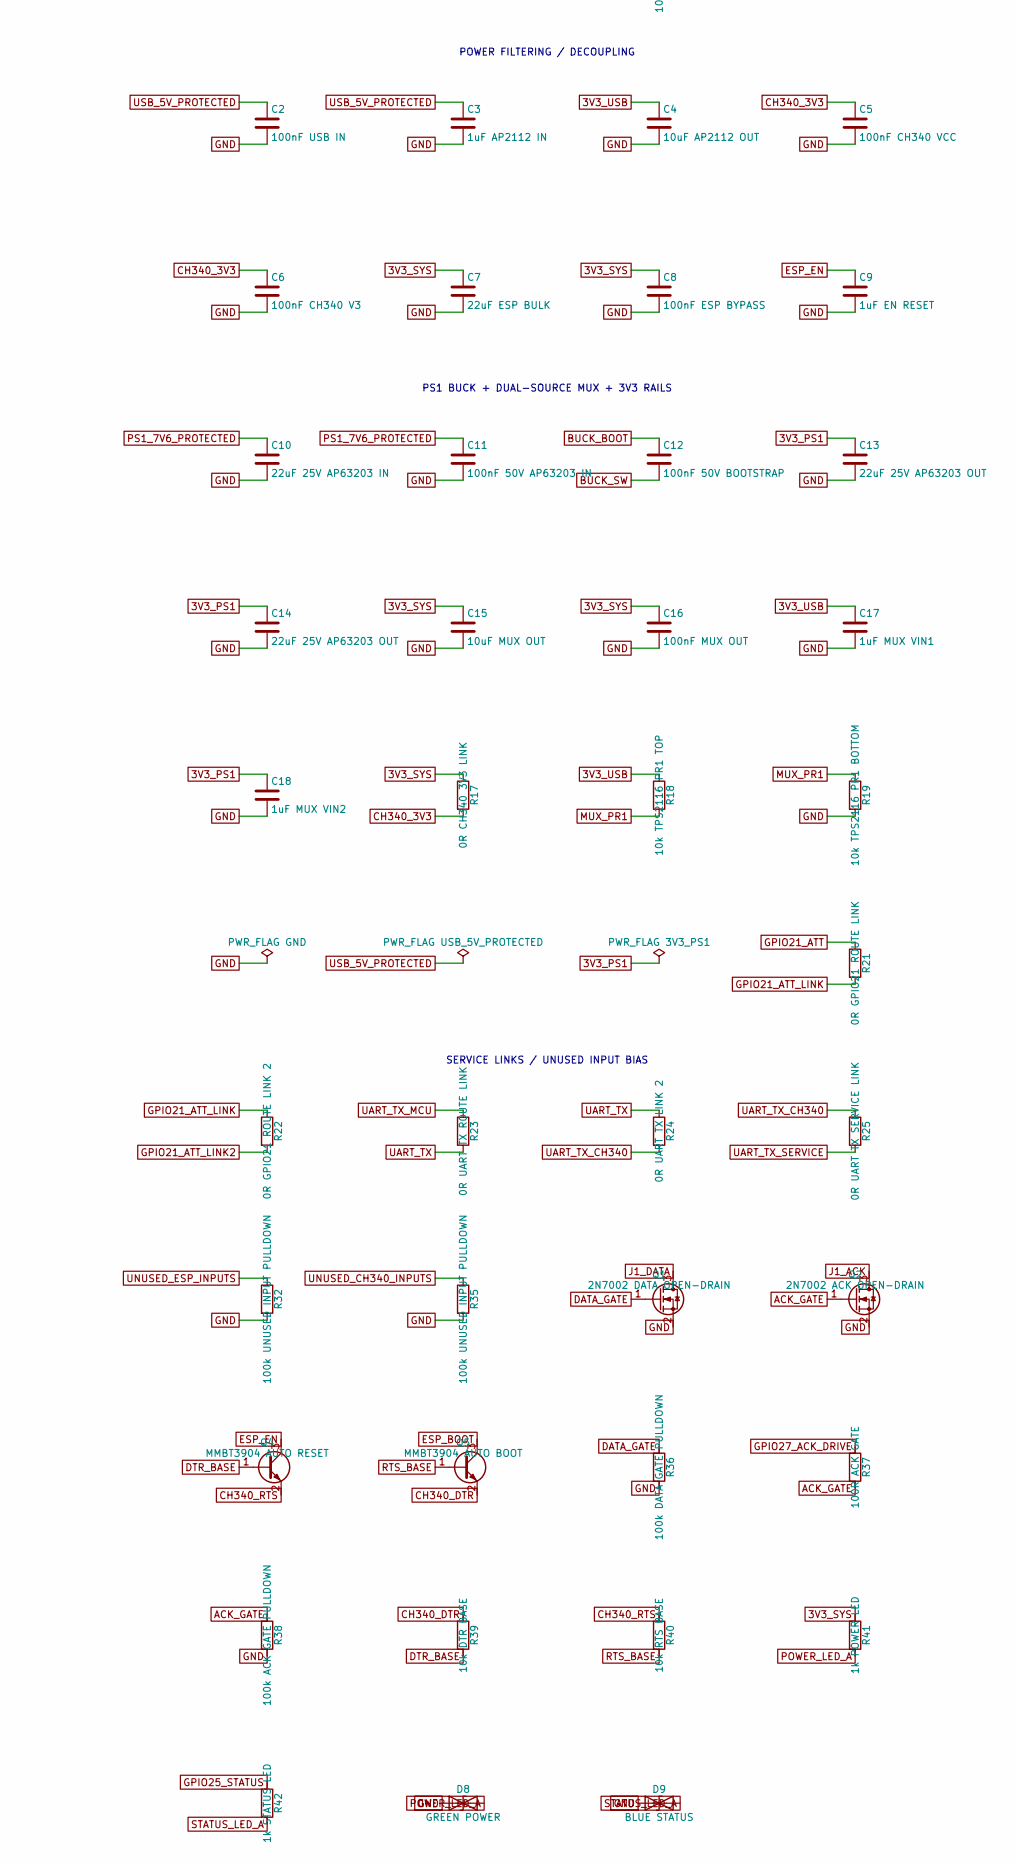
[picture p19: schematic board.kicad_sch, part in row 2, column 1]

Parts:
C1: 10uF 10V USB IN; C_0805_2012Metric; MPN CL21A106KOQNNNE; LCSC C1713
C2: 100nF USB IN; C_0603_1608Metric; MPN CC0603KRX7R9BB104; LCSC C14663
C3: 1uF AP2112 IN; C_0603_1608Metric; MPN CL10A105KA8NNNC; LCSC C5673
C4: 10uF AP2112 OUT; C_0805_2012Metric; MPN CL21A106KOQNNNE; LCSC C1713
C5: 100nF CH340 VCC; C_0603_1608Metric; MPN CC0603KRX7R9BB104; LCSC C14663
C6: 100nF CH340 V3; C_0603_1608Metric; MPN CC0603KRX7R9BB104; LCSC C14663
C7: 22uF ESP BULK; C_0805_2012Metric; MPN CL21A226MQQNNNE; LCSC C5674
C8: 100nF ESP BYPASS; C_0603_1608Metric; MPN CC0603KRX7R9BB104; LCSC C14663
C9: 1uF EN RESET; C_0603_1608Metric; MPN CL10A105KA8NNNC; LCSC C5673
C10: 22uF 25V AP63203 IN; C_1206_3216Metric; MPN CL31A226KAHNNNE; LCSC C12891
C11: 100nF 50V AP63203 IN; C_0603_1608Metric; MPN CC0603KRX7R9BB104; LCSC C14663
C12: 100nF 50V BOOTSTRAP; C_0603_1608Metric; MPN CC0603KRX7R9BB104; LCSC C14663
C13, C14: 22uF 25V AP63203 OUT; C_1206_3216Metric; MPN CL31A226KAHNNNE; LCSC C12891
C15: 10uF MUX OUT; C_0805_2012Metric; MPN CL21A106KOQNNNE; LCSC C1713
C16: 100nF MUX OUT; C_0603_1608Metric; MPN CC0603KRX7R9BB104; LCSC C14663
C17: 1uF MUX VIN1; C_0603_1608Metric; MPN CL10A105KA8NNNC; LCSC C5673
C18: 1uF MUX VIN2; C_0603_1608Metric; MPN CL10A105KA8NNNC; LCSC C5673
D1: SMAJ5.0A USB TVS; D_SMA; MPN SMAJ5.0A; LCSC C140902
D2: SMAJ12A PS1 TVS; D_SMA; MPN SMAJ12A; LCSC C908766
D3: PESD3V3U1UA ACK ESD; D_SOD-323; MPN PESD3V3U1UA,115; LCSC C403915
D4: TPD2EUSB30A USB ESD; Texas_DRT-3; MPN TPD2EUSB30ADRTR-TP; LCSC C2987043
D5, D6, D7: TPD2EUSB30A HARNESS ESD; Texas_DRT-3; MPN TPD2EUSB30ADRTR-TP; LCSC C2987043
D8: GREEN POWER; LED_0603_1608Metric; MPN 19-217/GHC-YR1S2/3T; LCSC C2286
D9: BLUE STATUS; LED_0603_1608Metric; MPN 19-217/BHC-ZL1M2RY/3T; LCSC C2293
F1: 750mA USB PTC; Fuse_1206_3216Metric; MPN BSMD1206-075-30V; LCSC C976305
F2: 0.75A PS1 PTC; Fuse_1206_3216Metric; MPN BSMD1206-075-30V; LCSC C976305
J1: J1 PS1 CONTROLLER - NOT USB; HC-USB3.0-L168-ZP; MPN HC-USB3.0-L168-ZP; LCSC C7501856
J2: J2 PS1 SERIAL - NOT USB; HC-USB3.0-L168-ZP; MPN HC-USB3.0-L168-ZP; LCSC C7501856
J3: J3 USB-C POWER / PROGRAM / PC; USB_C_Receptacle_HRO_TYPE-C-31-M-12_S1; MPN TYPE-C-31-M-12; LCSC C165948
J5: AP63203WU-7; TSOT-23-6; MPN AP63203WU-7; LCSC C780769
L1: 4.7uH +/-20%, 2.5A rated, 4.7A Isat; L_Sunlord_SWPA4020S; MPN CPN4020H4R7MT; LCSC C52741363
Q1: 2N7002 DATA OPEN-DRAIN; SOT-23; MPN 2N7002; LCSC C8545
Q2: 2N7002 ACK OPEN-DRAIN; SOT-23; MPN 2N7002; LCSC C8545
Q4: MMBT3904 AUTO RESET; SOT-23; MPN MMBT3904LT1G; LCSC C81464
Q5: MMBT3904 AUTO BOOT; SOT-23; MPN MMBT3904LT1G; LCSC C81464
R1: 5.1k CC1; R_0402_1005Metric; MPN 0402WGF5101TCE; LCSC C25905
R2: 5.1k CC2; R_0402_1005Metric; MPN 0402WGF5101TCE; LCSC C25905
R3: 10k EN PU; R_0603_1608Metric; MPN 0603WAF1002T5E; LCSC C25804
R4: 10k BOOT PU; R_0603_1608Metric; MPN 0603WAF1002T5E; LCSC C25804
R5: 1k UART RX SERIES; R_0603_1608Metric; MPN 0603WAF1001T5E; LCSC C21190
R6: 100k UART RX PULLDOWN; R_0603_1608Metric; MPN 0603WAF1003T5E; LCSC C25803
R7: 1k PS1 CMD; R_0603_1608Metric; MPN 0603WAF1001T5E; LCSC C21190
R8: 100R DATA GATE; R_0603_1608Metric; MPN 0603WAF1000T5E; LCSC C22775
R9: 1k PS1 CLK; R_0603_1608Metric; MPN 0603WAF1001T5E; LCSC C21190
R10: 1k PS1 ATT; R_0603_1608Metric; MPN 0603WAF1001T5E; LCSC C21190
R11: 1k PS1 ACK; R_0603_1608Metric; MPN 0603WAF1001T5E; LCSC C21190
R12: 10k PS1 DATA PU; R_0603_1608Metric; MPN 0603WAF1002T5E; LCSC C25804
R13: 10k PS1 ACK PU; R_0603_1608Metric; MPN 0603WAF1002T5E; LCSC C25804
R14: 1k UART2 TX; R_0603_1608Metric; MPN 0603WAF1001T5E; LCSC C21190
R15: 1k UART2 RX; R_0603_1608Metric; MPN 0603WAF1001T5E; LCSC C21190
R16: 100k MUX STATUS PU; R_0603_1608Metric; MPN 0603WAF1003T5E; LCSC C25803
R17: 0R CH340 3V3 LINK; R_0402_1005Metric; MPN 0402WGF0000TCE; LCSC C17168
R18: 10k TPS2116 PR1 TOP; R_0603_1608Metric; MPN 0603WAF1002T5E; LCSC C25804
R19: 10k TPS2116 PR1 BOTTOM; R_0603_1608Metric; MPN 0603WAF1002T5E; LCSC C25804
R21: 0R GPIO21 ROUTE LINK; R_0402_1005Metric; MPN 0402WGF0000TCE; LCSC C17168
R22: 0R GPIO21 ROUTE LINK 2; R_0402_1005Metric; MPN 0402WGF0000TCE; LCSC C17168
R23: 0R UART TX ROUTE LINK; R_0402_1005Metric; MPN 0402WGF0000TCE; LCSC C17168
R24: 0R UART TX LINK 2; R_0402_1005Metric; MPN 0402WGF0000TCE; LCSC C17168
R25: 0R UART TX SERVICE LINK; R_0402_1005Metric; MPN 0402WGF0000TCE; LCSC C17168
R32, R35: 100k UNUSED INPUT PULLDOWN; R_0603_1608Metric; MPN 0603WAF1003T5E; LCSC C25803
R36: 100k DATA GATE PULLDOWN; R_0603_1608Metric; MPN 0603WAF1003T5E; LCSC C25803
R37: 100R ACK GATE; R_0603_1608Metric; MPN 0603WAF1000T5E; LCSC C22775
R38: 100k ACK GATE PULLDOWN; R_0603_1608Metric; MPN 0603WAF1003T5E; LCSC C25803
R39: 10k DTR BASE; R_0603_1608Metric; MPN 0603WAF1002T5E; LCSC C25804
R40: 10k RTS BASE; R_0603_1608Metric; MPN 0603WAF1002T5E; LCSC C25804
R41: 1k POWER LED; R_0603_1608Metric; MPN 0603WAF1001T5E; LCSC C21190
R42: 1k STATUS LED; R_0603_1608Metric; MPN 0603WAF1001T5E; LCSC C21190
SW1: RESET; K2-1107ST-A4SW-06; MPN K2-1107ST-A4SW-06; LCSC C2837195
SW2: BOOT; K2-1107ST-A4SW-06; MPN K2-1107ST-A4SW-06; LCSC C2837195
TP1: SERVICE / DEBUG GND; TestPoint_THTPad_D2.0mm_Drill1.0mm; not fitted
TP2: TX; TestPoint_THTPad_D2.0mm_Drill1.0mm; not fitted
TP3: RX; TestPoint_THTPad_D2.0mm_Drill1.0mm; not fitted
U1: ESP32-WROOM-32E; ESP32-WROOM-32E-N4-PROD; MPN ESP32-WROOM-32E-N4; LCSC C701341
U2: CH340C; SOIC-16_3.9x9.9mm_P1.27mm; MPN CH340C; LCSC C84681
U4: AP2112K-3.3; SOT-23-5; MPN AP2112K-3.3TRG1; LCSC C51118
U6: TPS2116DRLR POWER MUX; SOT-583-8; MPN TPS2116DRLR; LCSC C3235557

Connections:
3V3_PS1: C13.1, C14.1, C18.1, J5.1, L1.2, U6.6 (VIN2)
3V3_SYS: C7.1, C8.1, C15.1, C16.1, R3.1, R4.1, R12.1, R13.1, R16.1, R17.1, R41.1, U1.2 (VDD), U6.2 (VOUT), U6.7 (VOUT)
3V3_USB: C4.1, C17.1, R18.1, U4.5 (VOUT), U6.3 (VIN1), U6.5 (MODE)
ACK_GATE: Q2.1 (G), R37.2, R38.1
BUCK_BOOT: C12.1, J5.6
BUCK_SW: C12.2, J5.5, L1.1
CH340_3V3: C5.1, C6.1, R17.2, U2.4 (V3), U2.16 (VCC)
CH340_DTR: Q5.2 (E), R39.1, U2.13 (~DTR)
CH340_RTS: Q4.2 (E), R40.1, U2.14 (~RTS)
CH340_TX_RAW: R5.1, U2.2 (TXD)
DATA_GATE: Q1.1 (G), R8.2, R36.1
DTR_BASE: Q4.1 (B), R39.2
ESP_BOOT: Q5.3 (C), R4.2, SW2.1, U1.25 (IO0)
ESP_EN: C9.1, Q4.3 (C), R3.2, SW1.1, U1.3 (EN)
GND: C1.2, C2.2, C3.2, C4.2, C5.2, C6.2, C7.2, C8.2, C9.2, C10.2, C11.2, C13.2, C14.2, C15.2, C16.2, C17.2, C18.2, D1.2 (A2), D2.2 (A2), D3.2 (A2), D4.3 (common), D5.3 (common), D6.3 (common), D7.3 (common), D8.1 (A1), D9.1 (A1), J1.4, J2.7, J3.A1 (GND), J3.A12 (GND), J3.B1 (GND), J3.B12 (GND), J3.S1 (SHIELD), J5.4, Q1.2 (S), Q2.2 (S), R1.2, R2.2, R6.2, R19.2, R32.2, R35.2, R36.2, R38.2, SW1.2, SW2.2, TP1.1 (1_1), U1.1 (GND), U1.15 (GND), U1.38 (GND), U1.39 (GND), U2.1 (GND), U2.15 (R232), U4.2 (GND), U6.1 (GND)
GPIO16_UART2_RX: R15.2, U1.27 (IO16)
GPIO17_UART2_TX: R14.1, U1.28 (IO17)
GPIO19_CMD: R7.1, U1.31 (IO19)
GPIO21_ATT: R21.1, U1.33 (IO21)
GPIO21_ATT_LINK: R21.2, R22.1
GPIO21_ATT_LINK2: R10.1, R22.2
GPIO25_STATUS: R42.1, U1.10 (IO25)
GPIO27_ACK_DRIVE: R37.1, U1.12 (IO27)
GPIO32_CLK: R9.1, U1.8 (IO32)
GPIO33_DATA: R8.1, U1.9 (IO33)
GPIO34_ACK: R11.1, U1.6 (IO34)
J1_ACK: D3.1 (A1), J1.7, Q2.3 (D), R11.2, R13.2
J1_ATT: D6.2 (A2), J1.5, R10.2
J1_CLK: D6.1 (A1), J1.3, R9.2
J1_CMD: D5.1 (A1), J1.2, R7.2
J1_DATA: D5.2 (A2), J1.6, Q1.3 (D), R12.2
J2_RX: D7.1 (A1), J2.4, R15.1
J2_TX: D7.2 (A2), J2.1, R14.2
MUX_PR1: R18.2, R19.1, U6.4 (PR1)
MUX_STATUS: R16.2, U6.8 (ST)
POWER_LED_A: D8.2 (A2), R41.2
PS1_7V6_PROTECTED: C10.1, C11.1, D2.1 (A1), F2.2, J5.2, J5.3
PS1_7V6_RAW: F2.1, J1.8
RTS_BASE: Q5.1 (B), R40.2
STATUS_LED_A: D9.2 (A2), R42.2
UART_RX: R5.2, R6.1, TP3.1 (1_1), U1.34 (RXD0/IO3)
UART_TX: R23.2, R24.1
UART_TX_CH340: R24.2, R25.1, U2.3 (RXD)
UART_TX_MCU: R23.1, U1.35 (TXD0/IO1)
UART_TX_SERVICE: R25.2, TP2.1 (1_1)
UNUSED_CH340_INPUTS: R35.1, U2.9 (~CTS), U2.10 (~DSR), U2.11 (~RI), U2.12 (~DCD)
UNUSED_ESP_INPUTS: R32.1, U1.4 (SENSOR_VP), U1.5 (SENSOR_VN), U1.7 (IO35)
USB_5V_PROTECTED: C1.1, C2.1, C3.1, D1.1 (A1), F1.2, U4.1 (VIN), U4.3 (EN)
USB_CC1: J3.A5 (CC1), R1.1
USB_CC2: J3.B5 (CC2), R2.1
USB_D+: D4.1 (A1), J3.A6 (D+), J3.B6 (D+), U2.5 (UD+)
USB_D-: D4.2 (A2), J3.A7 (D-), J3.B7 (D-), U2.6 (UD-)
USB_VBUS_RAW: F1.1, J3.A4 (VBUS), J3.A9 (VBUS), J3.B4 (VBUS), J3.B9 (VBUS)

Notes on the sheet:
PS1 HARNESS PORTS — J1/J2 ARE NOT USB
USB-C POWER / CH340C PROGRAMMING — J3 ONLY
POWER FILTERING / DECOUPLING
PS1 BUCK + DUAL-SOURCE MUX + 3V3 RAILS
SERVICE LINKS / UNUSED INPUT BIAS
PS1 SIGNAL PROTECTION AND CONDITIONING

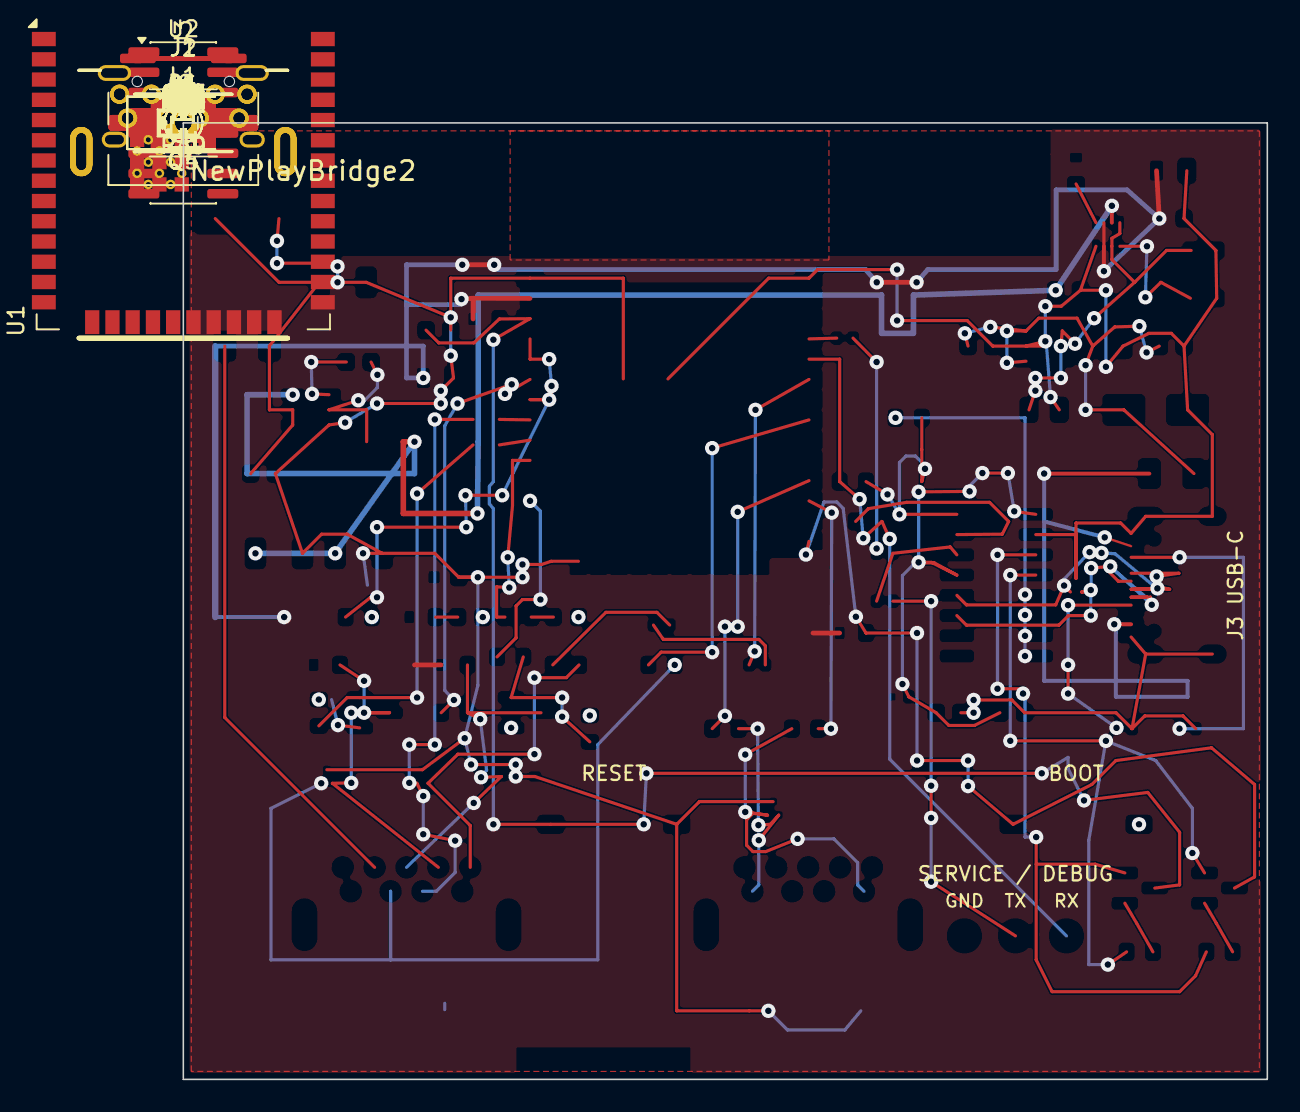
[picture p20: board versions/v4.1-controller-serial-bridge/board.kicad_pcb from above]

Board: 2 copper layers, 68.0 x 60.0 mm, 80 parts (0 on the bottom side), 53 nets.

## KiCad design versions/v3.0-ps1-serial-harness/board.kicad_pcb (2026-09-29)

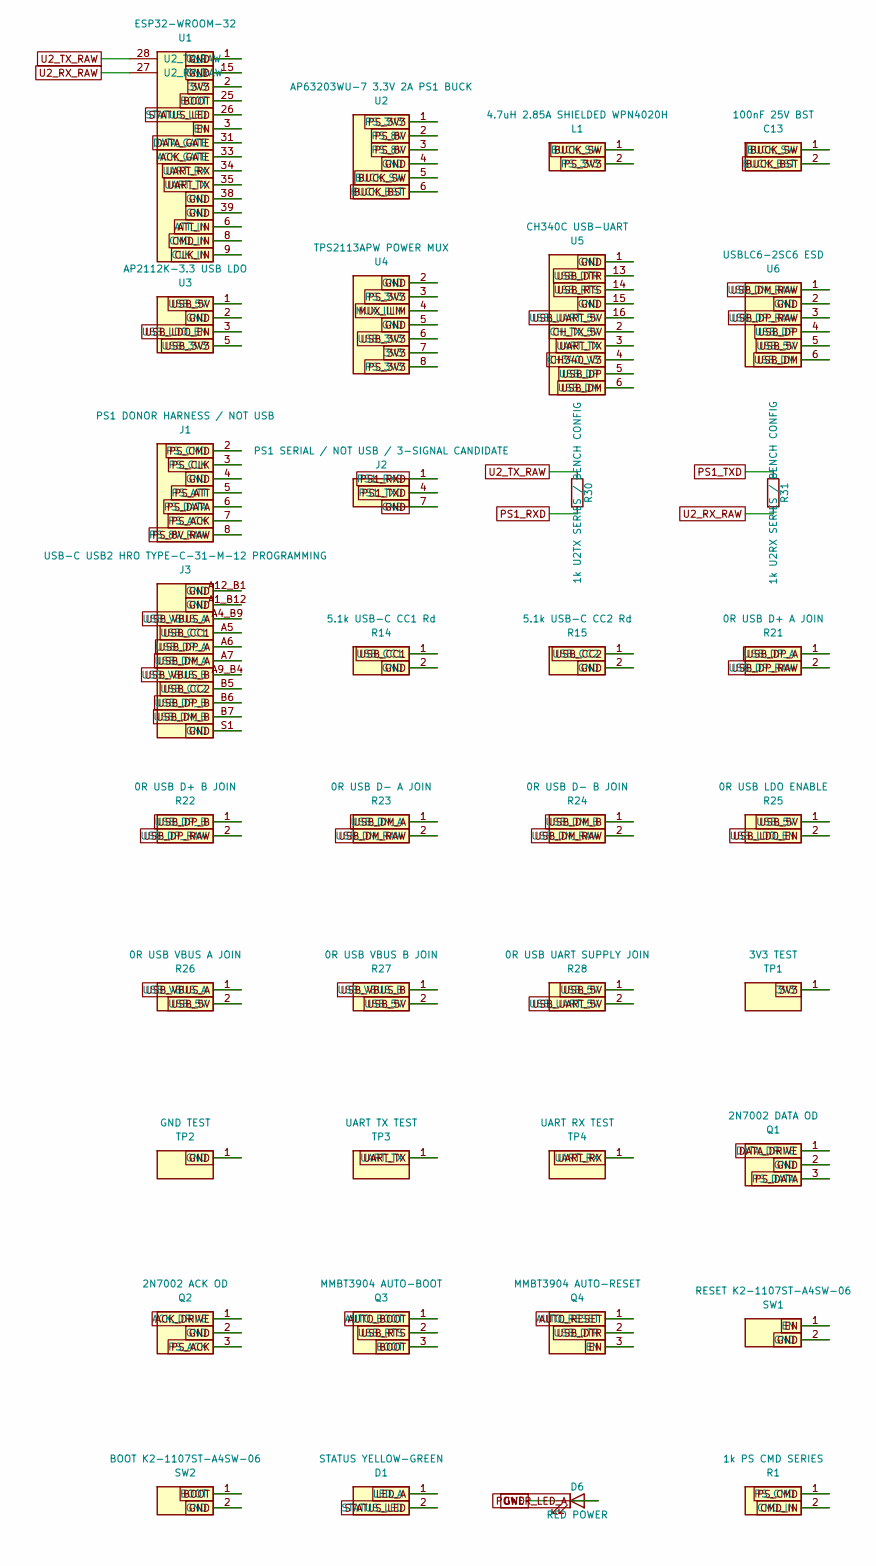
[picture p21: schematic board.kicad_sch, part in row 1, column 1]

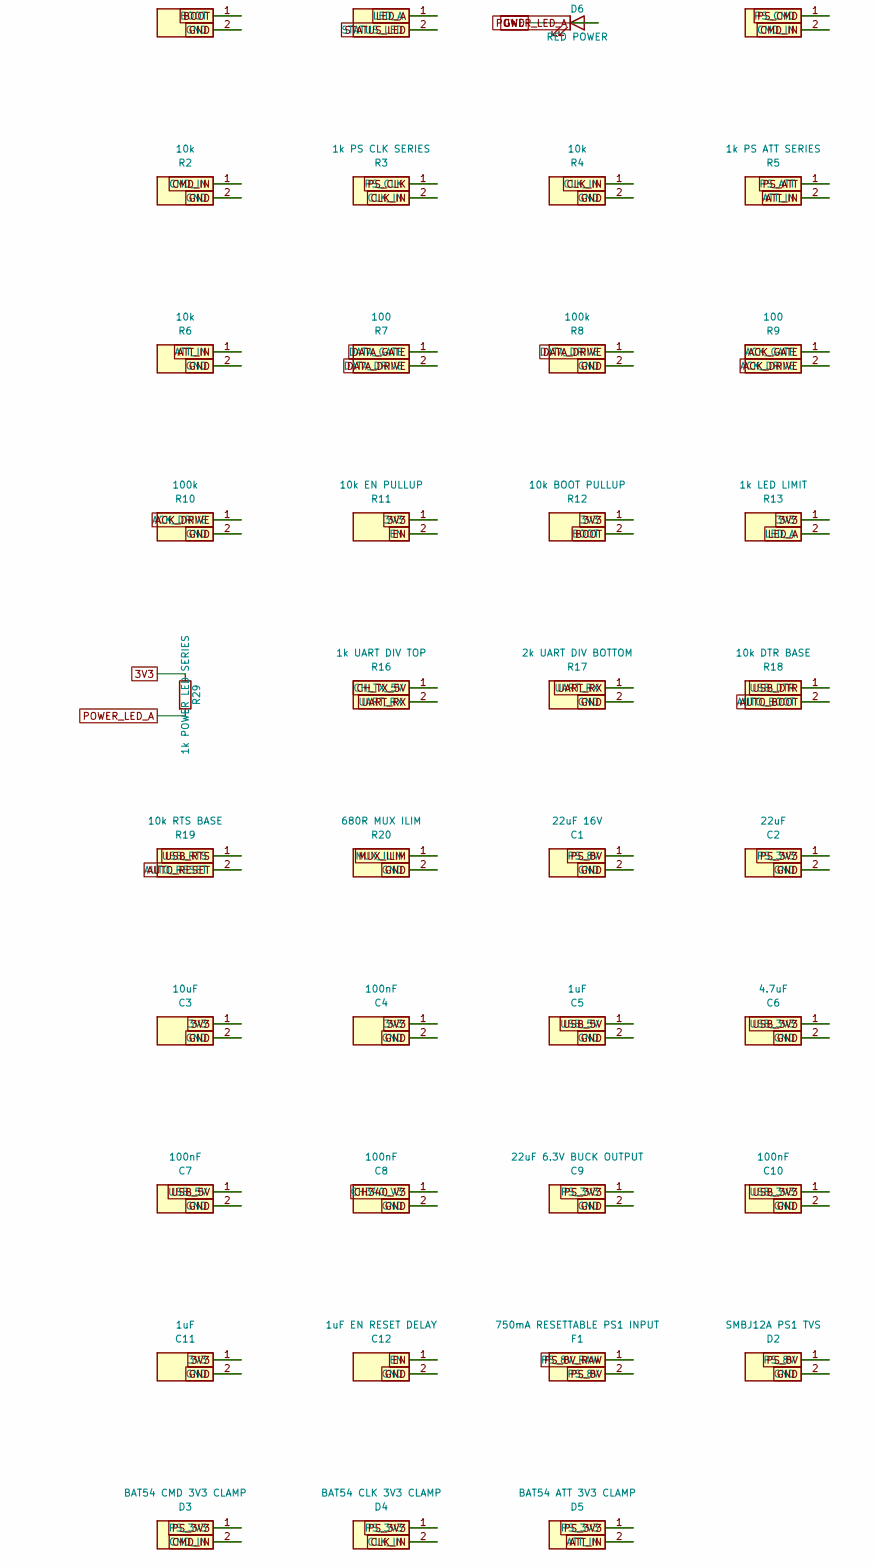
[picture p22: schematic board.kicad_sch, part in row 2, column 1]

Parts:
C1: 22uF 16V; C_1206_3216Metric; MPN CL31A226KAHNNNE; JLCPCB/LCSC Part C12891
C2: 22uF; C_1206_3216Metric; MPN CL31A226KAHNNNE; JLCPCB/LCSC Part C12891
C3: 10uF; C_0805_2012Metric; MPN CL21A106KOQNNNE; JLCPCB/LCSC Part C1713
C4, C7, C8, C10: 100nF; C_0603_1608Metric; MPN CC0603KRX7R9BB104; JLCPCB/LCSC Part C14663
C5, C11: 1uF; C_0603_1608Metric; MPN CL10A105KA8NNNC; JLCPCB/LCSC Part C5673
C6: 4.7uF; C_0805_2012Metric; MPN TCC0805X5R475K160FT; JLCPCB/LCSC Part C380342
C9: 22uF 6.3V BUCK OUTPUT; C_0805_2012Metric; MPN CL21A226MQQNNNE; JLCPCB/LCSC Part C5674
C12: 1uF EN RESET DELAY; C_0603_1608Metric; MPN CL10A105KA8NNNC; JLCPCB/LCSC Part C5673
C13: 100nF 25V BST; C_0603_1608Metric; MPN CC0603KRX7R9BB104; JLCPCB/LCSC Part C14663
D1: STATUS YELLOW-GREEN; LED_0603_1608Metric; MPN KT-0603YG; JLCPCB/LCSC Part C2289
D2: SMBJ12A PS1 TVS; D_SMA; MPN SMAJ12A; JLCPCB/LCSC Part C908766
D3: BAT54 CMD 3V3 CLAMP; D_SOD-323_SILK_CLEAN; MPN BAT54WS; JLCPCB/LCSC Part C916997
D4: BAT54 CLK 3V3 CLAMP; D_SOD-323_SILK_CLEAN; MPN BAT54WS; JLCPCB/LCSC Part C916997
D5: BAT54 ATT 3V3 CLAMP; D_SOD-323_SILK_CLEAN; MPN BAT54WS; JLCPCB/LCSC Part C916997
D6: RED POWER; LED_0603_1608Metric; MPN KT-0603R; LCSC C2286
F1: 750mA RESETTABLE PS1 INPUT; Fuse_1206_3216Metric; MPN BSMD1206-075-30V; JLCPCB/LCSC Part C976305
J1: PS1 DONOR HARNESS / NOT USB; USB3_A_HongCheng_HC-USB3.0-L168-ZP_C7501856_PS1_FRONT_MODEL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; MPN HC-USB3.0-L168-ZP; JLCPCB/LCSC Part C7501856
J2: PS1 SERIAL / NOT USB / 3-SIGNAL CANDIDATE; USB3_A_HongCheng_HC-USB3.0-L168-ZP_C7501856_PS1_SERIAL_MODE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; MPN HC-USB3.0-L168-ZP; JLCPCB/LCSC Part C7501856
J3: USB-C USB2 HRO TYPE-C-31-M-12 PROGRAMMING; USB_C_Receptacle_HRO_TYPE-C-31-M-12_INTERIOR_FANOUT_V16_C16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; MPN TYPE-C-31-M-12; JLCPCB/LCSC Part C165948
L1: 4.7uH 2.85A SHIELDED WPN4020H; L_Sunlord_WPN4020H; MPN WPN4020H4R7MT; JLCPCB/LCSC Part C98363
Q1: 2N7002 DATA OD; SOT-23_SILK_CLEAN_V2; MPN 2N7002; JLCPCB/LCSC Part C8545
Q2: 2N7002 ACK OD; SOT-23_SILK_CLEAN_V2; MPN 2N7002; JLCPCB/LCSC Part C8545
Q3: MMBT3904 AUTO-BOOT; SOT-23_SILK_CLEAN_V2; MPN MMBT3904(RANGE:100-300); JLCPCB/LCSC Part C20526
Q4: MMBT3904 AUTO-RESET; SOT-23_SILK_CLEAN_V2; MPN MMBT3904(RANGE:100-300); JLCPCB/LCSC Part C20526
R1: 1k PS CMD SERIES; R_0603_1608Metric_SILK_CLEAN; MPN 0603WAF1001T5E; JLCPCB/LCSC Part C21190
R2, R4, R6: 10k; R_0603_1608Metric_SILK_CLEAN; MPN 0603WAF1002T5E; JLCPCB/LCSC Part C25804
R3: 1k PS CLK SERIES; R_0603_1608Metric_SILK_CLEAN; MPN 0603WAF1001T5E; JLCPCB/LCSC Part C21190
R5: 1k PS ATT SERIES; R_0603_1608Metric_SILK_CLEAN; MPN 0603WAF1001T5E; JLCPCB/LCSC Part C21190
R7, R9: 100; R_0603_1608Metric_SILK_CLEAN; MPN 0603WAF1000T5E; JLCPCB/LCSC Part C22775
R8, R10: 100k; R_0603_1608Metric_SILK_CLEAN; MPN 0603WAF1003T5E; JLCPCB/LCSC Part C25803
R11: 10k EN PULLUP; R_0603_1608Metric_SILK_CLEAN; MPN 0603WAF1002T5E; JLCPCB/LCSC Part C25804
R12: 10k BOOT PULLUP; R_0603_1608Metric_SILK_CLEAN; MPN 0603WAF1002T5E; JLCPCB/LCSC Part C25804
R13: 1k LED LIMIT; R_0603_1608Metric_SILK_CLEAN; MPN 0603WAF1001T5E; JLCPCB/LCSC Part C21190
R14: 5.1k USB-C CC1 Rd; R_0402_1005Metric_SILK_CLEAN; MPN 0402WGF5101TCE; JLCPCB/LCSC Part C25905
R15: 5.1k USB-C CC2 Rd; R_0402_1005Metric_SILK_CLEAN; MPN 0402WGF5101TCE; JLCPCB/LCSC Part C25905
R16: 1k UART DIV TOP; R_0603_1608Metric_SILK_CLEAN; MPN 0603WAF1001T5E; JLCPCB/LCSC Part C21190
R17: 2k UART DIV BOTTOM; R_0603_1608Metric_SILK_CLEAN; MPN 0603WAF2001T5E; JLCPCB/LCSC Part C22975
R18: 10k DTR BASE; R_0603_1608Metric_SILK_CLEAN; MPN 0603WAF1002T5E; JLCPCB/LCSC Part C25804
R19: 10k RTS BASE; R_0603_1608Metric_SILK_CLEAN; MPN 0603WAF1002T5E; JLCPCB/LCSC Part C25804
R20: 680R MUX ILIM; R_0603_1608Metric_SILK_CLEAN; MPN 0603WAF6800T5E; JLCPCB/LCSC Part C23228
R21: 0R USB D+ A JOIN; R_0402_1005Metric_SILK_CLEAN; MPN 0402WGF0000TCE; JLCPCB/LCSC Part C17168
R22: 0R USB D+ B JOIN; R_0402_1005Metric_SILK_CLEAN; MPN 0402WGF0000TCE; JLCPCB/LCSC Part C17168
R23: 0R USB D- A JOIN; R_0402_1005Metric_SILK_CLEAN; MPN 0402WGF0000TCE; JLCPCB/LCSC Part C17168
R24: 0R USB D- B JOIN; R_0402_1005Metric_SILK_CLEAN; MPN 0402WGF0000TCE; JLCPCB/LCSC Part C17168
R25: 0R USB LDO ENABLE; R_0402_1005Metric_SILK_CLEAN; MPN 0402WGF0000TCE; JLCPCB/LCSC Part C17168
R26: 0R USB VBUS A JOIN; R_0402_1005Metric_SILK_CLEAN; MPN 0402WGF0000TCE; JLCPCB/LCSC Part C17168
R27: 0R USB VBUS B JOIN; R_0402_1005Metric_SILK_CLEAN; MPN 0402WGF0000TCE; JLCPCB/LCSC Part C17168
R28: 0R USB UART SUPPLY JOIN; R_0402_1005Metric_SILK_CLEAN; MPN 0402WGF0000TCE; JLCPCB/LCSC Part C17168
R29: 1k POWER LED SERIES; R_0603_1608Metric; MPN 0603WAF1001T5E; LCSC C21190
R30: 1k U2TX SERIES / BENCH CONFIG; R_0603_1608Metric_SILK_CLEAN; MPN 0603WAF1001T5E; JLCPCB/LCSC Part C21190
R31: 1k U2RX SERIES / BENCH CONFIG; R_0603_1608Metric_SILK_CLEAN; MPN 0603WAF1001T5E; JLCPCB/LCSC Part C21190
SW1: RESET K2-1107ST-A4SW-06; SW_SPST_HRO_K2-1107ST-A4SW-06_RESET_V8; MPN K2-1107ST-A4SW-06; LCSC C2837195
SW2: BOOT K2-1107ST-A4SW-06; SW_SPST_HRO_K2-1107ST-A4SW-06_BOOT_V8; MPN K2-1107ST-A4SW-06; LCSC C2837195
TP1: 3V3 TEST; TestPoint_Pad_D1.5mm_SILK_CLEAN
TP2: GND TEST; TestPoint_THTPad_D2.0mm_Drill1.0mm
TP3: UART TX TEST; TestPoint_THTPad_D2.0mm_Drill1.0mm
TP4: UART RX TEST; TestPoint_THTPad_D2.0mm_Drill1.0mm
U1: ESP32-WROOM-32; ESP32-WROOM-32_D0.3mm_SILK_CLEAN; MPN ESP32-WROOM-32E-N4; JLCPCB/LCSC Part C701341
U2: AP63203WU-7 3.3V 2A PS1 BUCK; TSOT-23-6; MPN AP63203WU-7; JLCPCB/LCSC Part C780769
U3: AP2112K-3.3 USB LDO; SOT-23-5; MPN AP2112K-3.3TRG1; JLCPCB/LCSC Part C51118
U4: TPS2113APW POWER MUX; TSSOP-8_3x3mm_P0.65mm_AUTHORIZED_KICAD_COPY; MPN TPS2113APWR; JLCPCB/LCSC Part C130052
U5: CH340C USB-UART; SOIC-16_3.9x9.9mm_P1.27mm_SILK_CLEAN; MPN CH340C; JLCPCB/LCSC Part C7464026
U6: USBLC6-2SC6 ESD; SOT-23-6; MPN USBLC6-2SC6; JLCPCB/LCSC Part C7519

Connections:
3V3: C3.1 (3V3), C4.1 (3V3), C11.1 (3V3), R11.1 (3V3), R12.1 (3V3), R13.1 (3V3), R29.1, TP1.1 (3V3_1), U1.2 (3V3), U4.7 (3V3)
ACK_DRIVE: Q2.1 (ACK_DRIVE), R9.2 (ACK_DRIVE), R10.1 (ACK_DRIVE)
ACK_GATE: R9.1 (ACK_GATE), U1.33 (ACK_GATE)
ATT_IN: D5.2 (ATT_IN), R5.2 (ATT_IN), R6.1 (ATT_IN), U1.6 (ATT_IN)
AUTO_BOOT: Q3.1 (AUTO_BOOT), R18.2 (AUTO_BOOT)
AUTO_RESET: Q4.1 (AUTO_RESET), R19.2 (AUTO_RESET)
BOOT: Q3.3 (BOOT), R12.2 (BOOT), SW2.1 (BOOT), U1.25 (BOOT)
BUCK_BST: C13.2 (BUCK_BST), U2.6 (BUCK_BST)
BUCK_SW: C13.1 (BUCK_SW), L1.1 (BUCK_SW), U2.5 (BUCK_SW)
CH340_V3: C8.1 (CH340_V3), U5.4 (CH340_V3)
CH_TX_5V: R16.1 (CH_TX_5V), U5.2 (CH_TX_5V)
CLK_IN: D4.2 (CLK_IN), R3.2 (CLK_IN), R4.1 (CLK_IN), U1.9 (CLK_IN)
CMD_IN: D3.2 (CMD_IN), R1.2 (CMD_IN), R2.1 (CMD_IN), U1.8 (CMD_IN)
DATA_DRIVE: Q1.1 (DATA_DRIVE), R7.2 (DATA_DRIVE), R8.1 (DATA_DRIVE)
DATA_GATE: R7.1 (DATA_GATE), U1.31 (DATA_GATE)
EN: C12.1 (EN), Q4.3 (EN), R11.2 (EN), SW1.1 (EN), U1.3 (EN)
GND: C1.2 (GND), C2.2 (GND), C3.2 (GND), C4.2 (GND), C5.2 (GND), C6.2 (GND), C7.2 (GND), C8.2 (GND), C9.2 (GND), C10.2 (GND), C11.2 (GND), C12.2 (GND), D2.2 (GND), D6.1 (K), J1.4 (GND), J2.7 (GND), J3.A1_B12 (GND), J3.A12_B1 (GND), J3.S1 (GND), Q1.2 (GND), Q2.2 (GND), R2.2 (GND), R4.2 (GND), R6.2 (GND), R8.2 (GND), R10.2 (GND), R14.2 (GND), R15.2 (GND), R17.2 (GND), R20.2 (GND), SW1.2 (GND), SW2.2 (GND), TP2.1 (GND_1), U1.1 (GND), U1.15 (GND), U1.38 (GND), U1.39 (GND), U2.4 (GND), U3.2 (GND), U4.2 (GND), U4.5 (GND), U5.1 (GND), U5.15 (GND), U6.2 (GND)
LED_A: D1.1 (LED_A), R13.2 (LED_A)
MUX_ILIM: R20.1 (MUX_ILIM), U4.4 (MUX_ILIM)
POWER_LED_A: D6.2 (A), R29.2
PS1_RXD: J2.1 (PS1_RXD), R30.2
PS1_TXD: J2.4 (PS1_TXD), R31.1
PS_3V3: C2.1 (PS_3V3), C9.1 (PS_3V3), D3.1 (PS_3V3), D4.1 (PS_3V3), D5.1 (PS_3V3), L1.2 (PS_3V3), U2.1 (PS_3V3), U4.3 (PS_3V3), U4.8 (PS_3V3)
PS_8V: C1.1 (PS_8V), D2.1 (PS_8V), F1.2 (PS_8V), U2.2 (PS_8V), U2.3 (PS_8V)
PS_8V_RAW: F1.1 (PS_8V_RAW), J1.8 (PS_8V_RAW)
PS_ACK: J1.7 (PS_ACK), Q2.3 (PS_ACK)
PS_ATT: J1.5 (PS_ATT), R5.1 (PS_ATT)
PS_CLK: J1.3 (PS_CLK), R3.1 (PS_CLK)
PS_CMD: J1.2 (PS_CMD), R1.1 (PS_CMD)
PS_DATA: J1.6 (PS_DATA), Q1.3 (PS_DATA)
STATUS_LED: D1.2 (STATUS_LED), U1.26 (STATUS_LED)
U2_RX_RAW: R31.2, U1.27 (U2_RX_RAW)
U2_TX_RAW: R30.1, U1.28 (U2_TX_RAW)
UART_RX: R16.2 (UART_RX), R17.1 (UART_RX), TP4.1 (UART_RX_1), U1.34 (UART_RX)
UART_TX: TP3.1 (UART_TX_1), U1.35 (UART_TX), U5.3 (UART_TX)
USB_3V3: C6.1 (USB_3V3), C10.1 (USB_3V3), U3.5 (USB_3V3), U4.6 (USB_3V3)
USB_5V: C5.1 (USB_5V), C7.1 (USB_5V), R25.1 (USB_5V), R26.2 (USB_5V), R27.2 (USB_5V), R28.1 (USB_5V), U3.1 (USB_5V), U6.5 (USB_5V)
USB_CC1: J3.A5 (USB_CC1), R14.1 (USB_CC1)
USB_CC2: J3.B5 (USB_CC2), R15.1 (USB_CC2)
USB_DM: U5.6 (USB_DM), U6.6 (USB_DM)
USB_DM_A: J3.A7 (USB_DM_A), R23.1 (USB_DM_A)
USB_DM_B: J3.B7 (USB_DM_B), R24.1 (USB_DM_B)
USB_DM_RAW: R23.2 (USB_DM_RAW), R24.2 (USB_DM_RAW), U6.1 (USB_DM_RAW)
USB_DP: U5.5 (USB_DP), U6.4 (USB_DP)
USB_DP_A: J3.A6 (USB_DP_A), R21.1 (USB_DP_A)
USB_DP_B: J3.B6 (USB_DP_B), R22.1 (USB_DP_B)
USB_DP_RAW: R21.2 (USB_DP_RAW), R22.2 (USB_DP_RAW), U6.3 (USB_DP_RAW)
USB_DTR: Q4.2 (USB_DTR), R18.1 (USB_DTR), U5.13 (USB_DTR)
USB_LDO_EN: R25.2 (USB_LDO_EN), U3.3 (USB_LDO_EN)
USB_RTS: Q3.2 (USB_RTS), R19.1 (USB_RTS), U5.14 (USB_RTS)
USB_UART_5V: R28.2 (USB_UART_5V), U5.16 (USB_UART_5V)
USB_VBUS_A: J3.A4_B9 (USB_VBUS_A), R26.1 (USB_VBUS_A)
USB_VBUS_B: J3.A9_B4 (USB_VBUS_B), R27.1 (USB_VBUS_B)

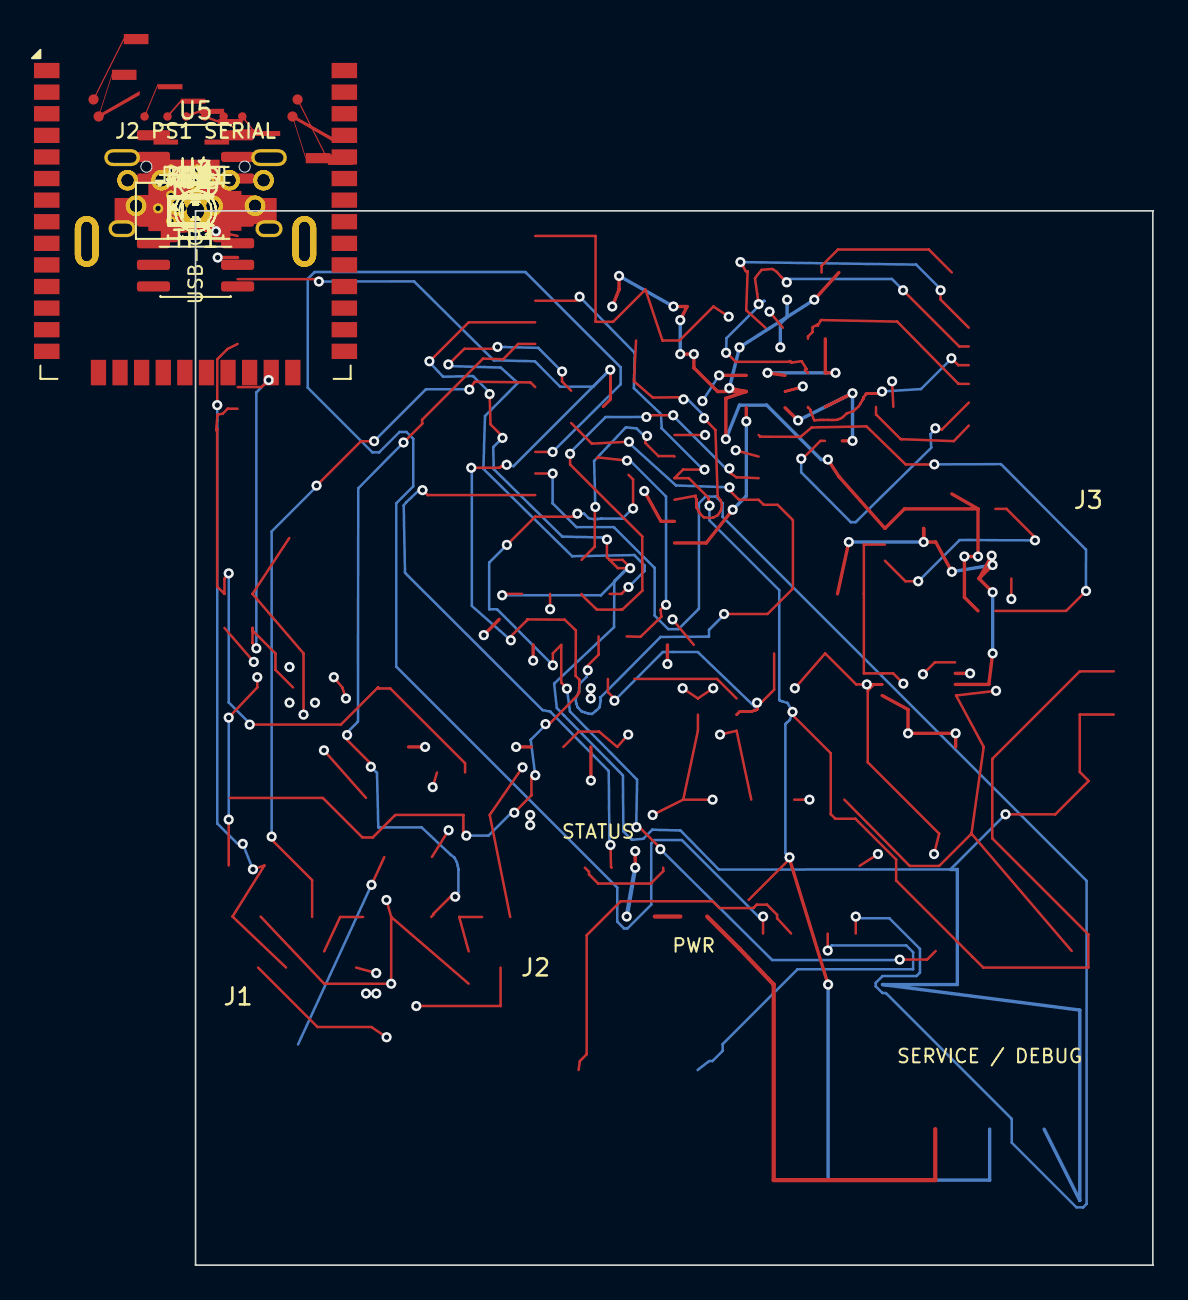
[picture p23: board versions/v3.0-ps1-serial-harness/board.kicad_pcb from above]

Board: 4 copper layers, 56.3 x 62.0 mm, 71 parts (0 on the bottom side), 53 nets.

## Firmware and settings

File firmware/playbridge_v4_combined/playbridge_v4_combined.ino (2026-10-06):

#include <WiFi.h>
#include <WebServer.h>
#include "ps1_polled_engine.h"
#include "pad_state.h"
#include "controller_page.h"
#include "Ps1GameBridge.h"

// Verified bench mapping, NOT an assertion that production V4 uses CMD34.
// Keep DATA C50 pull-up=1k, E51 base resistor=1k, C51 pull-down=100k.
// Bench readback: E50--1k--F50/G50--GPIO19.
// The separate core0 serial task owns J2 RX GPIO16 / TX GPIO17.
static WebServer server(80);
static portMUX_TYPE stateMux = portMUX_INITIALIZER_UNLOCKED;
static PadState pad;
struct Diagnostics {
  uint32_t frames, addresses, commands, replies, aborts, mismatches;
  uint8_t rx[5], data[5], count;
};
static Diagnostics published = {};
static bool serviceReady = false;
static bool bridgeTaskReady = false;
static constexpr const char *FIRMWARE_VERSION = "v4-combined-polled-0.1.0";

static void publishDiagnostics() {
  // Called only by the bus task after pollBus has released its critical section.
  portENTER_CRITICAL(&stateMux);
  published.frames=transactions; published.addresses=addresses;
  published.commands=commands; published.replies=fullReplies;
  published.aborts=aborted; published.mismatches=dataByteMismatches;
  published.count=lastBytes;
  for(unsigned i=0;i<5;++i){published.rx[i]=lastRx[i];published.data[i]=lastData[i];}
  portEXIT_CRITICAL(&stateMux);
}

static void handleState() {
  const String value=server.arg("mask");
  if(value.length()==0 || value.length()>5){server.send(400,"text/plain","Invalid mask");return;}
  uint32_t number=0;
  for(unsigned i=0;i<value.length();++i){
    if(value[i]<'0'||value[i]>'9'){server.send(400,"text/plain","Invalid mask");return;}
    number=number*10+(value[i]-'0');
  }
  if(number>65535){server.send(400,"text/plain","Invalid mask");return;}
  const uint32_t now=millis();
  portENTER_CRITICAL(&stateMux);pad.set(number,now);portEXIT_CRITICAL(&stateMux);
  server.send(200,"text/plain","Received");
}

static void handleStatus() {
  Diagnostics s;
  portENTER_CRITICAL(&stateMux);s=published;portEXIT_CRITICAL(&stateMux);
  char json[440];
  snprintf(json,sizeof(json),
    "{\"firmware\":\"v4-combined-polled-0.1.0\",\"transactions\":%lu,\"addresses\":%lu,\"commands\":%lu,\"fullReplies\":%lu,\"aborted\":%lu,\"dataMismatches\":%lu,\"bytes\":%u,\"rx\":\"%02X %02X %02X %02X %02X\",\"data\":\"%02X %02X %02X %02X %02X\"}",
    (unsigned long)s.frames,(unsigned long)s.addresses,(unsigned long)s.commands,
    (unsigned long)s.replies,(unsigned long)s.aborts,(unsigned long)s.mismatches,s.count,
    s.rx[0],s.rx[1],s.rx[2],s.rx[3],s.rx[4],s.data[0],s.data[1],s.data[2],s.data[3],s.data[4]);
  server.sendHeader("Cache-Control","no-store");server.send(200,"application/json",json);
}

static void handleBridgeStatus() {
  const auto s=Ps1GameBridge::snapshot();
  const auto &t=s.transport;
  char json[1600];
  snprintf(json,sizeof(json),
    "{\"firmware\":\"%s\",\"profile\":\"%s\",\"dataReadbackEnabled\":%s,"
    "\"taskCreated\":%s,\"initialized\":%s,\"fault\":%s,\"active\":%s,"
    "\"baud\":%lu,\"sessions\":%lu,\"aborts\":%lu,\"tcpReceived\":%lu,\"uartWritten\":%lu,"
    "\"uartReceived\":%lu,\"tcpWritten\":%lu,\"uartErrors\":%lu,\"socketErrors\":%lu,"
    "\"discardedSoftwareBytes\":%lu,\"shortWrites\":%lu,\"wouldBlock\":%lu,"
    "\"rejectedClients\":%lu,\"malformedControls\":%lu,\"duplicateControls\":%lu,"
    "\"controlAckAttempts\":%lu,\"drainTimeouts\":%lu,\"uartResetFailures\":%lu,"
    "\"toTcpPeak\":%lu,\"toUartPeak\":%lu,\"ownerCore\":%d,\"maxServiceGapUs\":%lu,"
    "\"maxIterationUs\":%lu,\"heapFree\":%lu,\"stackFreeBytes\":%lu}",
    FIRMWARE_VERSION,PROFILE_NAME,HAS_DATA_READBACK?"true":"false",
    bridgeTaskReady?"true":"false",s.initialized?"true":"false",t.fault?"true":"false",t.active?"true":"false",
    (unsigned long)t.baud,(unsigned long)t.sessions,(unsigned long)t.aborts,
    (unsigned long)t.tcpReceived,(unsigned long)t.uartWritten,(unsigned long)t.uartReceived,(unsigned long)t.tcpWritten,
    (unsigned long)t.uartErrors,(unsigned long)t.socketErrors,(unsigned long)t.discarded,
    (unsigned long)t.shortWrites,(unsigned long)t.wouldBlock,(unsigned long)t.rejected,
    (unsigned long)t.malformed,(unsigned long)t.duplicates,(unsigned long)t.controlAcks,
    (unsigned long)t.drainTimeouts,(unsigned long)t.resetFailures,(unsigned long)t.toTcpPeak,
    (unsigned long)t.toUartPeak,s.ownerCore,(unsigned long)s.maxServiceGapUs,
    (unsigned long)s.maxIterationUs,(unsigned long)s.heapFree,(unsigned long)s.stackFreeBytes);
  server.sendHeader("Cache-Control","no-store");server.send(200,"application/json",json);
}

static void bridgeTask(void *) {
  if(!Ps1GameBridge::begin()){Serial.println("J2 init failed; controller remains available");vTaskDelete(nullptr);}
  while(true){Ps1GameBridge::poll();vTaskDelay(1);}
}

static void webTask(void *) {
  WiFi.persistent(false); // No credential/NVS writes while timing tasks run.
  WiFi.mode(WIFI_AP_STA);
  WiFi.softAP("PlayBridge-Test","playbridge");
  WiFi.setAutoReconnect(true);
  WiFi.begin(); // Reuse saved credentials; no password in source or logs.
  WiFi.setSleep(false);
  // UART driver/ISR is installed by its owner on core0, never the pad core.
  bridgeTaskReady=xTaskCreatePinnedToCore(bridgeTask,"playbridge-j2",6144,nullptr,2,nullptr,0)==pdPASS;
  server.on("/",HTTP_GET,[]{server.sendHeader("Cache-Control","no-store");server.send_P(200,"text/html",CONTROLLER_PAGE);});
  server.on("/state",HTTP_POST,handleState);
  server.on("/status",HTTP_GET,handleStatus);
  server.on("/bridge/status",HTTP_GET,handleBridgeStatus);
  server.onNotFound([]{server.send(404,"text/plain","Not found");});
  server.begin();
  Serial.printf("Web polled controller: AP http://%s/ (PlayBridge-Test)\n",WiFi.softAPIP().toString().c_str());
  bool connected=false;
  while(true){
    server.handleClient();
    const bool current=WiFi.status()==WL_CONNECTED;
    if(current&&!connected)Serial.printf("Local UI: http://%s/\n",WiFi.localIP().toString().c_str());
    connected=current;
    vTaskDelay(1);
  }
}

void setup() {
  digitalWrite(DATA_DRIVE,LOW);digitalWrite(ACK_DRIVE,LOW);
  pinMode(DATA_DRIVE,OUTPUT);pinMode(ACK_DRIVE,OUTPUT);
  pinMode(CMD,INPUT);pinMode(CLK,INPUT);pinMode(ATT,INPUT);
  if(HAS_DATA_READBACK)pinMode(DATA_SENSE,INPUT);
  Serial.begin(115200);
  cyclesPerUs=getCpuFrequencyMhz();
  senseEnabled=HAS_DATA_READBACK;
  // Arduino loop runs on core1; network handling runs on core0. No per-edge ISR.
  if(xPortGetCoreID()!=1){Serial.println("ERROR: this build requires Arduino loop on core1");return;}
  serviceReady=xTaskCreatePinnedToCore(webTask,"playbridge-web",8192,nullptr,1,nullptr,0)==pdPASS;
  Serial.printf("%s profile=%s; UART2 RX16 TX17; neutral at boot, 800ms lease\n",FIRMWARE_VERSION,PROFILE_NAME);
  if(!serviceReady)Serial.println("ERROR: web task creation failed");
}

void loop() {
  if(!serviceReady){dataBit(true);ack(false);delay(10);return;}
  const uint32_t now=millis();
  portENTER_CRITICAL(&stateMux);const uint16_t buttons=pad.get(now);portEXIT_CRITICAL(&stateMux);
  pollBus(buttons);
  publishDiagnostics();
  delay(1); // Same idle yield as the console-verified diagnostic firmware.
}

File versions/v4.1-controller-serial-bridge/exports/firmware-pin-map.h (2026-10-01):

#pragma once

/* NewPlayBridge2 production hardware handoff. */
#define PLAYBRIDGE_PIN_CMD             19
#define PLAYBRIDGE_PIN_CLK             32
#define PLAYBRIDGE_PIN_ATT             21
#define PLAYBRIDGE_PIN_DATA_DRIVE      33
#define PLAYBRIDGE_PIN_ACK_DRIVE       27
#define PLAYBRIDGE_PIN_ACK_SENSE       34
#define PLAYBRIDGE_PIN_STATUS_LED      25
#define PLAYBRIDGE_PIN_UART2_TX        17
#define PLAYBRIDGE_PIN_UART2_RX        16

/* ESP32 UART0 remains dedicated to CH340C programming/debug. */
#define PLAYBRIDGE_PIN_UART0_TX         1
#define PLAYBRIDGE_PIN_UART0_RX         3

/* DATA and ACK drives are external 2N7002 open-drain stages. */
#define PLAYBRIDGE_DATA_ACTIVE_LOW      1
#define PLAYBRIDGE_ACK_ACTIVE_LOW       1

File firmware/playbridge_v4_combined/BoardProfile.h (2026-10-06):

#pragma once
#include <stdint.h>

// Select explicitly: 1 = console-tested Node32 breadboard, 2 = V4 PCB map.
// Profile 2 is compile-checked, not physical-PCBA qualified.
#ifndef PLAYBRIDGE_PROFILE
#define PLAYBRIDGE_PROFILE 1
#endif
#if PLAYBRIDGE_PROFILE == 1
static constexpr uint8_t CMD = 34, CLK = 32, ATT = 21;
static constexpr uint8_t DATA_DRIVE = 33, ACK_DRIVE = 27, DATA_SENSE = 19;
static constexpr bool HAS_DATA_READBACK = true;
static constexpr const char *PROFILE_NAME = "bench-cmd34-data19";
#elif PLAYBRIDGE_PROFILE == 2
static constexpr uint8_t CMD = 19, CLK = 32, ATT = 21;
static constexpr uint8_t DATA_DRIVE = 33, ACK_DRIVE = 27;
// Placeholder never configured/read; GPIO34 on PCB is ACK sense, NOT DATA.
static constexpr uint8_t DATA_SENSE = 34;
static constexpr bool HAS_DATA_READBACK = false;
static constexpr const char *PROFILE_NAME = "v4-pcb-unqualified";
#else
#error Select PLAYBRIDGE_PROFILE=1 (bench) or 2 (V4 PCB)
#endif
static constexpr int UART_RX = 16, UART_TX = 17;
static_assert(CMD != UART_RX && CMD != UART_TX && DATA_DRIVE != UART_TX,
              "Controller and serial pins must not overlap");

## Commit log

2026-09-16 Initial PlayBridge PS1 adapter design
    [BlueRetro2_PS1_bottom_Ali.stl, BlueRetro2_PS1_top_Ali.stl, board.kicad_pcb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]
2026-09-16 Archive early direct-plug enclosure concept
2026-09-17 Archive 55x52 WIP board checkpoint
    [board.kicad_pcb, board.kicad_sch, playbridge_direct_plug_provisional.scad]
2026-09-17 Add PS1 connector fit-check models and photos
    [9-pin-fitcheck.stl, playbridge-ps1-fit-check-v4-one-piece.stl]
2026-09-17 Checkpoint routed 55x52 PlayBridge board and reviewed renders
    [board.kicad_pcb, board.kicad_sch]
2026-09-18 Correct PS1 connector to eight contacts with pin 8 absent
2026-09-18 Add versioned hardware architecture structure
    [9-pin-fitcheck.stl, BlueRetro2_PS1_bottom_Ali.stl, BlueRetro2_PS1_top_Ali.stl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]
2026-09-18 Add V2 modular donor harness board checkpoint
    [board.kicad_pcb, board.kicad_sch]
2026-09-18 Align V2 USB-A footprints with Molex mechanics
    [board.kicad_pcb]
2026-09-18 Replace V2 USB-A preview with datasheet-derived model
    [board.kicad_pcb]
2026-09-21 Add PS1 wireless bench firmware
2026-09-23 Release PlayBridge hardware v2.0.0
    [board.kicad_pcb, board.kicad_sch, jlcpcb-bom.csv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]
2026-09-23 Add self-contained V2.0.0 hardware snapshot
    [board.kicad_pcb, board.kicad_sch, jlcpcb-bom.csv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]
2026-09-23 Organize hardware as version-local FabDesk projects
    [9-pin-fitcheck.stl, BlueRetro2_PS1_bottom_Ali.stl, BlueRetro2_PS1_top_Ali.stl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]
2026-09-24 docs: link PCB Fiddle
2026-09-24 docs: add V2 board render
2026-09-24 docs: invite readers to try PCB Fiddle
2026-09-24 docs: credit PCB Fiddle render
2026-09-25 Release PlayBridge V2.1 status and debug board
    [board.kicad_pcb, board.kicad_sch, jlcpcb-bom.csv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]
2026-09-25 Start V2.2 third SNAC architecture
    [board.kicad_pcb, board.kicad_sch, jlcpcb-bom.csv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]
2026-09-25 Start V3.0 PS1 serial harness audit
    [board.kicad_pcb, board.kicad_sch, jlcpcb-bom.csv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]
2026-09-25 Route J2 on dedicated ESP32 UART2 pins
    [board.kicad_pcb, board.kicad_sch]
2026-09-25 Simplify J2 silkscreen label
    [board.kicad_pcb]
2026-09-25 Add verified V3.0 populated renders
    [board.kicad_pcb]
2026-09-25 Record V3 PoC evidence and refresh manufacturing files
    [assembly-bom.csv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]
2026-09-25 Replace USB-A connectors with stocked C7501856
    [assembly-bom.csv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]
2026-09-25 Use stocked JLCPCB assembly parts
    [assembly-bom.csv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]
2026-09-25 Document live JLCPCB resistor substitution
    [assembly-bom.csv, bom.csv, jlcpcb-bom.csv]
2026-09-29 Add PlayBridge V4 hardware design for bench testing
    [assembly-bom.csv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]
2026-09-29 Correct V3 and V4 connector comparison
2026-10-01 Add PlayBridge V4.1 ANTS fabrication revision
    [assembly-bom.csv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]
2026-10-26 Record V4.0 JLC assembly corrections and corrected LED BOM
2026-10-30 Record JLC prototype order and synchronize V4.0 LED metadata
